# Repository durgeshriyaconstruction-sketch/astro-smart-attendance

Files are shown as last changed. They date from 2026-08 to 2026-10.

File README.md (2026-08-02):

# 🎯 Astro Smart Attendance

### AI + IoT + Cloud Smart School Attendance System

**Built by Team Sun Rises India | Class 9 | Renukoot, Uttar Pradesh, India**

---

## The Problem
Indian schools waste 10-15 minutes per class on manual attendance. 
Over 15 Lakh schools in India face this problem daily. Records, 
parent alerts and reports remain disconnected.

## Our Solution
A compact ESP32-based RFID attendance terminal with AI self-healing, 
Firebase Cloud dashboard, and automatic parent email alerts. 
Cost: Only 1,500 Rupees per unit.

## Technologies Used
- ESP32 DevKit V1
- RC522 RFID Module
- LCD1602 I2C Display
- Firebase (Auth + Realtime Database + Hosting)
- Astro AI 2.0 (Self-healing diagnostics)
- 3D Printed Enclosure (Blender)
- Arduino C++ and HTML/CSS/JavaScript

## Live Demo
Cloud Dashboard: https://astro-smart-attendence.web.app

## Validation
- 140 out of 140 Feature Tests Passing
- 10,000,000 Stress Test Cases Verified
- 0 Warnings, 0 Errors
- Working Prototype Ready

## Cost
1,500 Rupees per unit (95% cheaper than commercial systems)

## Key Features
- Works OFFLINE and syncs when internet returns
- Astro AI 2.0 with 11 self-healing diagnostic checks
- Daily and Period attendance tracking
- Admin and Student dashboards
- Automatic parent email alerts for late or absent
- Secure OTA firmware updates
- 3D printable product enclosure
- Role-based access (Admin, Student, Guardian)

## Team Sun Rises India
1. Shaurya Gupta - Team Lead, Firmware and Cloud Developer
2. Anant Tiwari - Ideation and User Research Lead
3. Tejash Upadhyaye - Hardware Integration and Circuit Testing
4. Diwakar Singh - Product Design and 3D Enclosure
5. Devansh Dakard - Testing, Documentation and Presentation

## Mentor
Dr. Jayesh Shinde - The Aditya Birla Public School, Renukoot

## Contact
Location: Renukoot, Sonbhadra, Uttar Pradesh, India

---
Made in Renukoot, India
Team Sun Rises India - STEM 2026-27

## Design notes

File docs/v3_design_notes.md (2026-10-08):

# Astro Smart Attendance - enclosure **v3**, the complete re-design

Everything in this file is a measurement of the shipped `cad/v3/*.stl` files, not an intention.
Box: **110 x 155 x 46 mm** outer, walls 2.6 mm on the sides and 3.0 mm front / rear / top,
plate 3.0 mm skin + 2 mm register frame, 22 self-tapping pilots at thread minor diameter
(M2.5 -> 2.05, M2.2 -> 1.80, M3 -> 2.50), plain side walls, and since v3.4 one hole: the d28 fan
bore is the **only air opening** on the box - the twelve grille slots v3.3 cut were filled in by
request - no supports anywhere.
All four files are **bed-aligned**: the orientation a printer must see is baked into the triangles
(`tools/orient_v3.py` is the single source of truth, and the verifier undoes that one translation
before it asserts anything in the design frame).
Four independent programs had to agree before a single line was written here:

| check | program | result |
|---|---|---|
| parametric audit A-K | `tools/build_v3.py` | `RESULT: ALL CHECKS PASS` (`docs/v3_audit.txt`) |
| STL-only verification | `tools/verify_v3.py` | `INDEPENDENT RESULT: ALL CHECKS PASS` (`docs/v3_independent_verify.txt`) |
| 10-section multi-physics audit | `tools/audit_physics_v3.py` | `PHYSICS RESULT: no failures` (`docs/v3_physics_audit.txt`) |
| groove + printed-fit walk | `tools/check_grooves_v3.py` | `EVERY GROOVE AND FIT MEASURES AS DESIGNED` - 34 values, each probed at 0.02 mm through the shipped STLs (`docs/v3_groove_check.txt`) |

That third program is the one that found the last three real defects, described in section 6.
It re-measures the shipped triangles and then argues with them: thread bite and pull-out, screw
heads and insertion kinematics, the fan's operating point against the openings it really has,
PLA's glass transition in an UP summer, 13.56 MHz and 2.4 GHz loss, the optical and viewing cones,
the ligaments between openings, and a layer-by-layer slicer model of how much plastic is extruded.

The second one never imports the generator: it re-types the reference dimensions, re-cuts the
meshes and re-measures every hole, opening and wall from triangles alone. The fourth one is the
answer to "is the size and the fitting of the groove 100 %": it does not check the *design*, it
walks a probe line through each rebate, recess, lip and hole in the file you print and prints the
number the plastic actually offers - mouth 72.00 x 23.53 for the LCD, depth 0.438, through-window
66.00 x 17.53; R307 opening 21.01 x 25.01 around a 19.3 x 21.2 lens; RC522 recess 44.73 x 62.72
x 0.798 deep leaving a 2.197 mm ledge, aperture 38.01 x 56.00; register lip 104.305 x 148.503 in
a 104.785 x 148.982 opening = 0.240 mm per side; keyhole 7.531 x 4.614 at 50.01 span; ring
opening 37.008 x 55.002 so its lip stands 0.50 mm inside the aperture; ring body 2.611 with 1.097
left under the 1.503 head recess; and the ring's four pads and its rim level to 0.001 mm. Every
one of those agrees with the intent within 0.035 mm, which is the probe's own 0.02 mm quantisation
plus rounding - i.e. the plastic is where it was told to be.

---

## 1. Why v3 exists

v2 was a repaired v1: same proportions, same walls, fixes bolted on. That is why it looked
"the same". v3 is generated from the same layout engine but with different *decisions*: the
depth came out of the RFID stack instead of being picked, the front face was re-drawn around
the modules, the RFID hold-down was replaced with a different mechanism, and the rear closure
was replaced with a different joint.

### measured shape changes (v2 -> v3)

| | v2 | v3 | why |
|---|---|---|---|
| overall size | 110 x 155 x **48** | 110 x 155 x **46** | the 48 mm was 2 mm of unused rear plug; depth is now the RFID stack + 3 mm cover |
| side wall | 2.4 mm | **2.6 mm** | v2's thinnest structural wall was 1.2 mm at the vents; 2.6 buys stiffness without new volume |
| RFID aperture | 56 x 38 with 2 x 4 mm stiffener bars (90.4 % open) | **38 x 56 portrait**, 100 % open, R5 corners | 8269 rays sampled in the aperture, 0 blocked (v2: 190 mm2 of shadow) |
| RC522 hold-down | 2 clamp bars + a 0.9 mm lip, printed **x2**, clamped over the board | **1 flat ring**, printed x1, 43.6 x 76.0 x 2.6, its inner lip 0.5 mm inside the aperture | 2.2 cm3 instead of two 1.6 cc bars, nothing in front of the antenna, one part, no flex |
| RC522 bearing | 2.0 mm ledge under the board | **2.2 mm** ledge (recess 0.8 instead of 1.0) | a 0.2 mm deeper wall in front of the coil is 8 % less plastic the 13.56 MHz has to push through |
| fan opening | d26 bore with 3 moulded grille bars (50 % free) + a d30 x 1.2 seat recess leaving a 1.4 mm lip | **d28 bore, nothing across it** (100 % free), flat wall | 616 of 616 sampled mm2 clear, and the print's most fragile sliver is gone |
| front-face openings | flush cut | **0.45 x 3.0 mm rebate ring** sunk around the LCD and the fingerprint opening | the module's own bezel sits in the rebate: a shadow line, no chipped edge, and the glass cannot be scratched by the frame |
| fingerprint mounting | 2 posts + a flat 2 mm strap over the sensor face | **dog-bone bracket** (wide over the holes, narrow across the glass) + 2 seat ribs, plus the module registers on the rebate floor | the bracket can be lifted off without prying on the glass |
| rear closure | solid 2 mm plug filling the opening (79.6 cc) | **8-sided register frame**, 2 mm proud, 0.25 mm/side, with the ESP32 zone cut clear in the **frame only** (**53.8 cm3**) | 26 cm3 (32 %) less plastic, and the board + its bosses + its locating tabs get real clearance while the 3 mm skin stays unbroken |
| ESP32 mounting | 4 square 8 x 8 posts | 4 **round d7 bosses** with **d3.6 x 0.7 spotfaces** | a round boss has no corner crack; the spotface sinks the head so the plate can still close |
| ventilation | fan wall only, everything else choked | **v3.4: one opening, the one that moves air.** The d28 fan bore in the -X wall is the only air hole on the box (615 mm2, fan blows IN) and the bottom wall keeps just the USB opening; v3.3's 8-slot bottom + 4-slot top grilles (1069 mm2, 1.74x the bore) are solid plastic. See sections 7 and 9 | air has a real path, the walls are not perforated for nothing, and nothing on the box is an opening without a duty |
| print volume | 199.6 cc (all 4 parts) | **172.2 cm3** CAD -> **159 g printed** (114 g shell + 42 g plate + 4 g small parts at 0.45 nozzle, 3 walls, 15 % infill) | the ring and the frame replace bars and a plug; 396 g all up with the modules on two wall hooks |

Nothing above is a design *claim*: `build_v3.py` section K measures the aperture and the bore by
ray-scan, the plate volume by mesh volume, the ledge flatness by probe, and `verify_v3.py`
repeats the aperture, the bore, the frame fit and the wall map from the STLs alone.

## 2. What is in the pack

| file | print | notes |
|---|---|---|
| `01_MAIN_SHELL_v3.stl` | x1 | 115.2 cm3, 11 108 triangles, watertight, 1 body, 0 open edges |
| `02_REAR_PLATE_v3.stl` | x1 | 53.8 cm3, 3 mm plate + 2 mm register frame |
| `03_R307_BRACKET_v3.stl` | x1 | 1.0 cm3, flat, 36.8 x 14.0 x 3.2 |
| `04_RC522_RING_v3.stl` | x1 | 2.2 cm3, flat, 43.6 x 76.0 x 2.6 (body 43.6 x 62.4, screw tabs to y +/-38) |

Four files, four prints, no mirrors, no "print this one twice".

## 3. Fixings - all 22 holes are circular, hollow and measured

`verify_v3.py` finds each hole in the mesh, measures its diameter with 8 rays at 3 depths, and
checks the wall around it. `build_v3.py` section I additionally asks "is this diameter and depth
actually what was designed".

| fixing | count | thread | pilot measured | driver access |
|---|---|---|---|---|
| LCD1602 + I2C backpack | 4 | M2.5 | **d2.04** x 6.3 (designed 2.05 = the thread's minor) | clear 25 mm |
| R307 bracket | 2 | M3 | d2.48 x 6.3 (designed 2.50) | clear 13 mm |
| **RC522 ring** | 4 | M2.5 | **d2.04 x 2.5 through the ring + blind d2.04 x 3.8 in the shell pad, 1.4 mm of wall left under it** | clear 23 mm |
| ESP32 DevKit V1 | 4 | M2.2 | d1.78 x 5.7 (designed 1.80) | clear 25 mm |
| 3010 fan | 4 | M3 | d2.48 x 10.3 (designed 2.50) | clear 25 mm |
| rear plate | 4 | M3 | d2.48 x 8.3 + 6.6 mm 90-deg csk | clear 25 mm |
| cable loom | 4 | - | through d4.0 tie holes | - |

The RC522 row is the one that used to be missing. It is now clamped the same way as the LCD:
four screws into four pads, and the ring's lip holds the board down. No glue, no clip, no
snap-fit, and nothing crosses the scan window.

Every pilot is at the screw's **minor** diameter, not its nominal one, because these are
thread-forming screws into printed PLA: at nominal the crest only just touches the hole wall, the
joint is friction and the screw spins. Measured radial bite/play after printing is +0.01 to +0.05
mm, and the computed pull-out is 75-362 N per screw against 0.15-0.88 N of service load (213x to
12 500x reserve). The audit's own conclusion, which is the honest one: **fastener count and
screwdriver access, not fastener strength, are what govern this box** - which is why every module
got its own 2-4 screws.

## 4. Printability, verified rather than assumed

* thinnest *sheet* anywhere in the shell: **2.2 mm** (the bearing band the RC522 board lies
  on), then 2.55 mm under the rebate rings, then 2.6 mm of side wall. The verifier's ray map
  reports a 1.40 mm minimum, and it is not a wall: it is the floor of the blind M2.5 pilot
  under an RC522 pad, which is exactly what was designed (1.4 mm of plastic under a 3.8 mm
  thread seat). v2 inherited a 1.0 x 1.4 mm lip all round the fan bore - a shallow d30 seat
  recess for a fan that is bolted to standoffs and never enters that wall - and v3 **deletes
  it**: the fan wall is a flat 3.0 mm plate with a clean d28 bore, which is both the visible
  change and the reason no fragile sliver is left in the print.
* faces steeper than 60 degrees: 244 mm2 = **0.30 %** of the shell (v3.3 measured 296 mm2 =
  0.36 % - filling the grilles in removed 52 mm2 of slot rims), and each of those bridges less
  than 3 mm -> **supports: no**.
* 214 slices at 0.2 mm: zero self-intersections, zero empty layers, first layer 11 469 mm2 (the
  footprint did not change - the shell's outline is the same 110 x 155 mm front face).
* the worst area jump in the whole print is 794 mm2 of new wall at z=0.6 and it cantilevers
  0.20 mm past the layer below (v3.3's worst was 2 415 mm2 at z=10 with a 0.00 mm cantilever);
  2 634 mm2 is added over the whole 43.0 mm of print, 0.47 % of the layer sum.
* the 10 sub-micron sliver triangles left by the boolean rim chamfers are inside the mesh, are
  under 1 um2 each, and are reported (not hidden) by the verifier.

## 5. The four numbers that used to need your calipers  *(all four closed 2026-10-08 -> section 10)*

These were the ones where a wrong number would cost a print, and the geometry is deliberately
forgiving (+/- 0.35 mm seat fit, 0.5 mm ring overlap, spotfaced bosses) so small errors are
absorbed.  Every line below is now checked against published vendor data instead of against your
drawer - what each one turned out to be:

1. ESP32 DevKit V1 - pad-hole inset from the board edge: 3.5 mm, still the modelled value, and
   corroborated by the closest published drawing in the family (wESP32 puts its 3.0 mm pad holes
   3.5 mm from the edge).  DOIT's own hole *diameter* is the one number that stays unpublished
   (2.5 mm reported by owners, 3.0 mm on that drawing): it decides M2.2 vs M2 and nothing else.
2. R307 - bracket hole pitch: there is no such pitch.  The module has no mounting holes; the stock
   kits clamp it with a bracket and two long screws, so the 28.0 mm between our posts is a choice
   we made to clear the antenna end and the corner posts, and it cannot be wrong.
3. LCD1602 + I2C backpack depth: 13.2 / 18.24 / 20.0 mm depending on whose backpack - the pocket
   reserves 24.0 behind the glass, so the deepest one on sale fits with 4 mm to spare.
4. 3010 fan - thickness and hole size: 30 x 30 x 10 with a 24 +/- 0.3 mm pattern and four 3 mm
   holes, exactly as modelled; the +/- 0.3 is taken up by the M3 shank inside the lug hole.

If any one of them is more than 0.5 mm out, change the number in `tools/build_v3.py` and re-run
`python3 tools/build_v3.py` (about 1 minute, it re-exports the STLs and re-runs every check, and
prints `RESULT: ALL CHECKS PASS` or refuses to). Then re-run `tools/verify_v3.py` (STL only)
and `tools/audit_physics_v3.py` (physics, and it re-measures the numbers in this file and in the
print order, so a doc cannot survive a stale claim).

---

## 6. v3.1 -> v3.2: what the physics audit found, and what changed

Both checkers passed v3.0, and the audit still found three real defects. All three are fixed in the
files you are printing; all three are now guarded by a permanent check, so they cannot come back.

**F11 - a rear-plate screw countersink opening onto a corner round (medium).** The 6.6 mm 90-degree
cone at each of the 4 plate screws was 0.08 mm from the R3 corner round of the plate outline, i.e.
the cone broke through the side of the part and the screw head would have had a hole to fall into.
The four screws moved from (+/-46.5, +/-71.0) to **(+/-46.5, +/-67.5)**, 3.5 mm inboard of the
rounds. The verifier now measures, for each corner, the plastic left between the cone axis and the
plate outline at the outer face: **2.25, 2.25, 2.25 and 3.80 mm** (it must be >= 1.2 mm; v3.0
measured 0.08 mm).

**F12 - the rear plate had a 15.6 x 63 mm hole through it (high).** The cut that keeps the ESP32's
locating bosses clear of the plate ran from the register frame to `z = D + 2`, i.e. **through the
whole 3 mm skin** instead of only the 2 mm frame that stands into the cavity. The shipped v3.0 plate
was open to dust and weather over that corner, and the "plate closes the box" claim was false. The
cut's top is now `z0 + 0.16` (the frame's own top surface), the plate went from 51.4 to 53.8 cm3,
and the verifier gained a check that slices the plate at mid-thickness and demands *exactly* 6 voids
- the 4 screw holes and the 2 keyhole slots - and >= 15 600 mm2 of skin (v3.0 measured 14 897 mm2
with a hole; v3.2 measures 15 983 mm2 with none).

**F13 - the RFID reader could not be installed at all (high).** Its PCB is 60 x 40 mm and v3 laid
the 60 mm dimension across the box, against the -X wall. But that wall carries the ESP32 on four
10 mm stand-off posts and the 3010 fan on four more, and the front wall's bay between the ESP32's
posts (ending at x = -42.4) and the R307's own -X post (starting at x = +15.95) is 58.35 mm:
**1.25 mm narrower than the board, 4.05 mm narrower than its hold-down ring.** Lowering the part
onto its seat is impossible in any orientation, tilted or not, and it is not fixed by a build order
because the blocking plastic is printed into the wall. Fixed by mounting the reader **portrait** -
its 60 mm dimension along the 155 mm height instead - which was always the better layout for a card
anyway: the whole stack is then 43.6 mm wide, drops straight down with 6.4 mm to the ESP32 posts,
10.2 mm to the R307 post and 3.25 mm to the fan bosses, and the reader centre moved from x = -20.05
to x = -16.05, which also widened the ligament between the RFID aperture and the fingerprint window
from 17.5 to 22.5 mm. Aperture 38 x 56 (2106 mm2, still 8269/8269 rays clear), ring 43.6 x 62.4
body with screw tabs at (+/-17, +/-34), and the audit section 3 now proves a straight-Z path for
**every** module plus the plate.

Two things that were not defects but are now corrected in the docs: the air path, and the print's
mass.  The air path went through two changes: v3.1/v3.2 opened 8 x 30 x 5 mm stadium slots in the
+X wall (1157 mm2) because the 6 x d5.0 / 118 mm2 of v3.0 choked the fan; then **v3.3 deleted those
side slots** and moved the inlet into the fan's own bore (see the v3.3 section below). The 15 % infill figure of ~102 g was a blanket 50 % factor and is
**too low**: a 2.6 mm wall printed on a 0.45 nozzle with 3 perimeter lines is 2.7 mm of perimeter,
so it prints solid. Layer-by-layer over the shipped meshes the parts extrude 79 % (shell), 62 %
(plate), 100 % (bracket) and 100 % (ring) of their CAD volume = **159 g of PLA**, 396 g with the
modules on the wall, and a 1 kg spool prints the set 6.3 times (53.0 m of 1.75 mm filament).
(`verify_v3`'s typed per-part fractions put the same print at 158 g - 0.6 % apart, both quoted
rather than smoothed, because the two are different samplings of one model.)  Those
those are the v3.4 figures; the grilles v3.3 left in the bottom and top walls were worth 3.2 cc of
plastic and 3 g of it.

Assembly note that came out of section 3: the reader's 8-pin header may not be taller than about
6 mm over the pads, because the channel under the ESP32 posts is 9.8 mm and the board plus a 9 mm
male header is 10.6 mm. Solder the leads, or use short / right-angle female headers, or fit the
reader before the ESP32. Everything else - ring, R307, LCD, fan, ESP32 - drops straight in with the
plate off, and the plate is the last thing closed.

Print order (unchanged by all of the above): all four parts flat on the bed, `01` front face down,
`02` frame down, `03` back face down, `04` pad face down; 0.2 mm layers, 2.6 mm walls, 15 % infill,
3 top/bottom skins, no supports, no brim needed unless your bed is unlevel (the shell's rim is
436 mm long).

---

## 7. v3.2 -> v3.3: the fan does the work, so the side grooves went away  *(v3.3, superseded below)*

Asked for directly: *"remove the right side many grooves - for that I have fan"*.  The eight stadium
slots in the +X wall went, and that wall is solid 2.6 mm plastic - the independent checker
slices it at mid-thickness and finds **0 voids**, still true in v3.4.  A fan still has to move air
through *something*, so the duty moved instead of disappearing, and the numbers below are what the
v3.3 STLs measured - the history of where the openings were, with v3.4's change in section 9:

| | v3.2 | v3.3 (then v3.4, section 9) |
|---|---|---|
| inlet | 8 x 30 x 5 mm slots in the +X wall, 1157 mm2 | the **d28 fan bore itself** in the -X wall: 615 mm2, measured 615 of 616 clear |
| fan direction | blowing OUT (exhaust) | **blowing IN** - the arrows moulded on the fan's frame point at the box |
| outlet | 4 x (20 x 4) bottom + 3 x (16 x 3) top, 452 mm2 | **8 x (21 x 4.5) bottom + 4 x (21 x 4) top = 1069 mm2**, 1.74x the bore - all twelve of those slots are filled in now |
| right (+X) wall | perforated over 4 of its 6 rows of features | plain; nothing to sand, nothing to crack, and the ESP32 bosses keep their full wall behind them |

The rule as it stood then was from the master prompt - the passive set must stay **>= 1.5x the fan
bore** - and it is that rule, not the geometry, that v3.4 replaces with a different one (section 9).
Everything else about the path was deliberate, and stays true of the walls as they now stand:

* bottom grille (v3.3, now solid): 21.00 x 4.50 mm slots in 4 columns (+/-12.5, +/-37.5) at 2 heights (z 7.0 and 15.0),
  every corner rounded r1.6 (r1.2 in the top wall) so there is no corner to start a crack - which
  also means each one measures 92.3 mm2 of free area, not the 94.5 mm2 of a sharp rectangle;
* top grille: 21.00 x 4.00 mm, 4 slots at z 26, i.e. the warmest air above the board level;
* 3.50 mm of plastic between the two rows, 4.00 mm between the columns - never thinner than the
  3.0 mm wall they are cut in;
* the lowest slot edge sat 1.75 mm clear of the front wall's inner face, and 4.6 mm clear of the
  20.4 x 12.4 mm USB opening in the same wall - that opening is the one thing left in it;
* pressurising the box rather than evacuating it is the better direction for this unit: it pushes air
  out through the RFID aperture and the LCD rebate, which is what keeps dust from being sucked in
  around the R307 prism.

Two options were rejected with numbers, not taste.  Sealing the +X wall and leaving v3.2's grilles
would have dropped the passive set to 452 mm2 = 0.73x the bore: the fan would have run close to its
own choke point and the box would have been a negative-pressure dust collector.  The first v3.3 cut
- rows of 5 mm slots at z 7 and 14.5 - failed the audit outright:
`web between neighbouring bottom grille openings  2.50 mm minimum  FAIL`, a ligament thinner than
the wall around it.  Dropping the slot height to 4.5 and opening the rows to 7 / 15 gave 3.50 mm of
web, and widening the slots 18 -> 21 mm at a 25 mm pitch (still 4.00 mm between neighbours) paid the
area back with interest: 985 mm2 -> 1069 mm2 of outlet.

Duty point against the fan's straight line, as section 4 of the physics audit measured it **on the
v3.3 mesh**: A_eff 533 mm2 -> 0.84 L/s at 1.9 Pa, 84 % of the fan's free air, the whole 784 cm3 box
changed every 0.9 s, dT 1.6 K at 1.6 W.  That was the same duty point v3.2 measured (0.86 L/s) with
a wall full of holes in it, reached with the passive openings alone and no perforation in the side
wall; the bottom grille was 8 x 21 x 4.5 mm and the top 4 x 21 x 4 mm, which is where the
1069 mm2 came from.  With the grilles filled in the flow is smaller and the box is no cooler - that
is section 9's measurement, not this one.
Nothing in this section is load-bearing on the geometry switch alone: setting `P["side_intake"] = True`
in `tools/build_v3.py` puts v3.2's perforated wall back in one rebuild, `P["grilles"] = True` puts
v3.3's twelve slots back, and the build's self-test changes its checks to match either way.  Those
flags exist so these decisions can be reversed without archaeology; they are not hidden second
designs - the shipped model is the one with `side_intake=False, grilles=False`.

## 8. The fifth print: `05_FIT_GAUGE_v3.stl`, a card that answers the five open questions  *(kept in the repo, out of the pack from v3.5)*

Section 5 left five numbers owned by your hardware rather than by any datasheet I could read from
here - which pilot your boss actually bites, what size the hole in your PCB really is, whether the
1602 window and its 75.1 x 31.0 pitch are your module, whether the R307's bezel clears a 21 x 25
relief, and whether the RC522 board and its pads sit where the ledge is.  Those are all *size*
questions, so they do not need a box to answer them: they need a printed thing of known size.  The
card is that thing - 150 x 112 x 2.60 mm, print-flat, 40 minutes, and every number on it read out
of `tools/build_v3.py` at build time rather than typed a second time.

Two conventions, and only two, because a gauge that mixes them is unreadable:

* **a cut is a GO gauge.**  The card is 2.60 thick and the hole in it is the hole in the wall, to
  the micron, so anything that drops through the cut fits the box.  A pass here is a pass there;
  that is the whole promise, and `tools/check_gauge_v3.py` measures it rather than asserting it.
* **an engraved line is a reference outline** - the board, the pitch, the prism window, the ledge -
  0.50 mm deep, to be read with calipers or felt with a fingernail.

Seven stations: six blind pilots (d1.80 / 2.00 / 2.05 / 2.20 / 2.35 / 2.50 at 8.00 deep, each
leaving 4.60 mm of solid boss under it), four through-board-holes (d2.00 to d2.70), the 1602 window
and its pitch crosses, the R307 relief plus the prism window and body outline, the RC522 board at
+0.40 a side with its ledge and four pads, the USB opening as the wall has it, and a 100 mm rule
ticked every 10 mm so a printer that shrinks the whole set is found out first.  The card's own
thickness is also the shim unit: 2.60 mm, the height of one wall, so stacking two says 5.20.

What it cannot do, said plainly: it cannot tell you how *tall* a module is, or whether an LCD's
contrast survives a 1.6 mm shelf.  Those are the box's own geometry and they are measured in
`docs/v3_groove_check.txt`.  The card settles the sizes; the box still has to be test-fitted.

Three real defects were caught building it, which is what a self-check is for:

* the first boolean produced 12 open edges.  Cause: thirty engraved pockets extruded as separate
  prisms with coplanar walls touching each other.  Fixed by unioning every pocket that shares a
  plane in 2-D and extruding once - which also dropped the file from 32 958 to 16 208 triangles.
* `is_watertight` said True while the normals pointed *inward*.  A slicer handed that STL may print
  the card hollow.  Fixed with `fix_normals()` in the builder, and the build now refuses to write a
  file unless `is_watertight and is_volume and volume > 0` (`GAUGE BUILD: ALL CHECKS PASS`).
* the first checker reported `watertight=False` for a part that was fine, because its probe asked
  "how many void stretches are in this window" instead of "which stretch contains the centre".  A
  probe line that crosses the far side of the part on its way to the window edge is not a second
  void.  The rule now used everywhere: the interval that contains the probe centre, refined by
  bisection - and it must back off *two* samples, not one, because a sample can land exactly on a
  surface (that is where a d1.80 pilot read 1.750 for one run: half a step on each side).

The wall comparison is deliberately not a min-of-three-planes statistic any more.  Profiling the
front wall at five planes showed a 0.05 mm disagreement on one plane - a grazing ray on a vertex,
not a taper - so the checker now reports the spread as its own row (`LCD width is a clean prism`,
0.000 to 0.050 mm) and compares the *median* against the card, requiring the card never to be the
bigger of the two.  That row can still fail, and fails if a wall ever does taper.

The card is registered everywhere a part has to be: `tools/orient_v3.py` (`0.0`, printed flat,
engraved face up), the pack's STL list, its figure list, the offline viewer, and the print order -
where it is step 0, before the shell, which is the entire point of it.

## 9. v3.3 -> v3.4: one hole, not twelve - the grilles are gone

Asked for directly, pointing at the hollows in the side of the box: *"remove all unnecessary ... no
need for those hollows, only let that DC fan one - not more, and last check"*.  So every grille slot
was filled in.  The bottom wall loses its 8 x (21 x 4.5) grille and keeps **only the USB opening**
(20.4 x 12.4 mm, a cable hole, never an air one); the top wall loses its 4 x (21 x 4) grille and has
no opening left at all; the +X wall was already plain in v3.3 and still is.  What is on the box now:

| wall (measured at mid-thickness off the shipped STL) | v3.3 | v3.4 |
|---|---|---|
| bottom (-Y) | 8 slots + USB, 9 voids | **1 void**: the 20.40 x 12.40 mm USB opening |
| top (+Y) | 4 slots, 4 voids | **0 voids** |
| right (+X) | 0 voids | 0 voids |
| left (-X) | d28 bore, 615 mm2 | **d28 bore, 615 mm2 - the only air opening** |

That inventory is not a claim in a document, it is `tools/verify_v3.py` section 6b, run on the STL
and nothing else, and it also fires 9 sample rays at each of the twelve old slot centres and both
ends of every slot (36 probes, 324 rays) which all have to be *blocked*: a slot that came back would
let them through.  `tools/make_grille_map_v3.py` draws the same four sections and exits non-zero
unless the counts are 1 / 0 / 0 / 1.

**What the change costs, measured rather than argued.**  The openings were the *flow* path; the heat
mostly leaves through the *skin*, and the skin did not change.  Section 4 of the physics audit now
computes both:

* passive: 1.6 W (ESP32 in TX bursts + RC522 + the fan's own draw) over 0.0585 m2 of PLA at
  h = 10 W/m2.K -> **dT = 2.7 K** above ambient; at h = 5 (a closed cabinet, no air movement) 5.5 K;
* through-flow: the fan has only the bore in front of it and the plate's register seam to get out
    of, 509 mm of frame x 0.25 mm of clearance = 127 mm2 *[this one row is an ASSUMPTION about your
  print, and the audit records it as a note, never as a gate]* -> A_eff 125 mm2 -> **0.25 L/s at
  12.2 Pa**, 25 % of the fan's free air, the 784 cm3 box changed every 3.2 s, dT 5.4 K;
* the two paths are in parallel, so the box settles at **dT = 1.8 K**.  v3.3 measured 1.6 K with
  1069 mm2 of grille open, so closing all twelve slots is worth **0.2 K**: the through-flow fell
  from 0.84 L/s to 0.25 L/s, 30 % of what it was, because a d28 bore was always what limited a
  3.6 m3/h blower - but the skin never noticed, and that is the whole reason the trade was open
  to make.  12.2 Pa is high up a small blower's pressure curve, which is what a fan facing a
  narrow gap does; it costs a little noise, not cooling.

The trade is therefore real but small, and two things about it are worth knowing before the print is
sanded off the bed:

* the fan is now part of the enclosure, not an accessory.  The d28 bore is the biggest hole on the
  box; a 30 x 30 frame spans it with 1 mm of plastic all round, so with the fan screwed in there is
  no opening a finger can follow, but a shell used *without* the fan has a 28 mm hole in its side.
* what the fan still does inside a sealed box is stir: it breaks the boundary layer off the LCD and
  the R307 prism and holds the enclosure slightly above room pressure, which is what keeps dust from
  being pulled in around the scanner.  It is a demister that also cools, and it should keep running
  from the ESP32's own supply.

Nothing else moved.  Filling twelve slots in added 3.2 cc of plastic to the shell (112.0 cc -> **115.2 cm3**),
11 108 triangles where v3.3 had 14 426 (3 318 fewer, because the slot outlines and their corner arcs
are gone), and it *reduced* the fragile geometry: overhang area 296 mm2 -> **244 mm2** (0.30 % of the
shell), still no supports, first layer 11 469 mm2.  The four box parts are now **172.2 cm3 CAD ->
159 g of PLA**, 396 g with the modules on two wall hooks, 53.0 m of filament, 6.3 sets on a 1 kg
spool.  `02_REAR_PLATE_v3.stl`, `03_R307_BRACKET_v3.stl` and `04_RC522_RING_v3.stl` are byte-identical
to v3.3 - only the shell was rebuilt - and so is `05_FIT_GAUGE_v3.stl`, which the user still prints
first because none of this changes a pilot diameter.

Reversible in one line, like every other aesthetic decision on this model: `P["grilles"] = True` in
`tools/build_v3.py` brings all twelve slots back, and the builder's self-checks, section 6b of the
verifier and the opening map all switch their expectations with the flag rather than being edited to
match.

---

## 10. v3.4 → v3.5: the pack is four files, and the open sizes were closed from vendor data

Asked for the exact sizes and a final screw list — and not willing to print a gauge or measure
anything — the only honest way to answer was to go and look.  Every module in this box was checked
against published outlines on 2026-10-08.  **Nothing in the geometry moved**, and that is the result
rather than a shrug: the model was built from the same numbers the vendors publish, so the audit, the
verifier and the four STLs you already have still refer to these exact bytes.

| part | what the vendor data says | what the box has | verdict |
|---|---|---|---|
| R307 | 44.1 × 20 × 23.5 body, 19 × 21 window — makerselectronics, robokits and the Grow/NEWTECH manual all publish the same numbers | `r307_body=(20.0, 44.1, 23.5)`, window 19.3 × 21.2, relief 21.0 × 25.0 in a 25.3 × 27.2 rebate | **exact**, 0.3–0.6 mm clear around the glass, 0.35 seat fit |
| R307 mounting | the module has no mounting holes at all: the four Phillips screws on its back close the housing, and the stock kits (ArduGeek, sensorembedded, Grow) clamp it with a bracket plus two long M3 | a printed dog-bone bracket over the housing, 2 × M3 × 10 into ⌀2.5 × 8.0 posts | **the same method as the kit**, so the 28.0 mm pitch is our bracket's and not a tolerance to match |
| 1602 + I2C | 80 × 36 outline; depth 13.2 (displaymodule.com, slim), 18.24 (addicore), 20.0 (einstronic); 72 × 25 of bezel, 64.5 × 16.2 of visible text | window 66.0 × 17.5, rebate 72.0 × 23.5 × 0.45, cavity reserved to `zi+24.0` | **every depth sold fits with ≥4 mm to spare**, and the audit's envelope check proved the pocket collides with nothing |
| RC522 | 60 × 40, 1.6 PCB, header ≤ 6 mm | 62.7 × 44.7 × 2.9 recess, 1.0 shelf, 4 ribs, the ring clamps the edges | **fits any brand of that size**; the board's own hole pitch is deliberately unused |
| 3010 fan | 30 × 30 × 10, "mounting dimensions 24 ± 0.3 mm", "4 holes 3 mm"; 5 V parts flow 1.9–2.5 CFM | `fan=(30,30,10)`, `fan_pitch=24.0`, ⌀3.2 lugs, ⌀28 bore, flow modelled 3.6 m³/h | **exact**; the modelled flow is inside the published 3.2–4.2 m³/h band and the audit runs the low end |
| ESP32 DevKit V1 | 51.45 × 28.33 (espboards.dev draws it to that outline), 52 × 28 × **14** with headers (einstronic); pad holes ⌀2.5 reported by owners, ⌀3.0 on the wESP32 drawing with 3.5 inset | `esp32_board=(28.33, 51.45, 1.6)`, `esp32_comp_h=16.0`, inset 3.5, M2.2 into ⌀1.8 | outline **exact**, height **2 mm over the real stack**, pad-hole diameter still unpublished — it decides M2.2 vs M2 and nothing else |

Two near-misses that turned out to be fine.  The ESP32's real 14 mm stack looked like it needed
`esp32_comp_h` raised from 12: it was already 16.0, and the audit proves the plate still closes over it.
And the fan's ±0.3 mm pattern tolerance is absorbed by the M3 shank having 0.1 mm per side inside the
lug hole — which is precisely why the wall holes are ⌀2.5 pilots rather than threads cut to 24.0.

**Screws, final.**  Same table as the print order's SCREWS section, which the audit measured hole by
hole (22 of them):

| where | screw | into | evidence |
|---|---|---|---|
| rear plate | 4 × M3 × 10 | ⌀2.48 × 9.0 blind pilots; plate holes ⌀3.4 clearance; 90° countersink ⌀6.40 | pull-out 291 N each vs 0.59 N of load |
| LCD1602 | 4 × M2.5 × **8** (was × 12, over-length) | ⌀2.05, 7.00 mm of void | the pilot is the thread's minor ⌀2.06, so it bites |
| RC522 ring | 4 × M2.5 × **4** (was × 8, over-length) | ⌀2.05, 4.30 mm of void through ring and pad | ⌀5.6 × 1.5 recesses in the ring take the pan heads; × 5 is the longest this hole can be told |
| R307 bracket | 2 × M3 × **8** (was × 10, over-length) | ⌀2.50, 8.20 mm of void | the bracket is 3.2 mm thick and printed, so its own thickness is already inside that void |
| fan | 4 × M3 × **12** into the printed tabs; **× 20** only if you drill through the whole 10 mm frame | ⌀2.50, 11.00 mm of void from inside | a 3010 usually ships **two** screws — you need four, pan head, not countersunk; nothing longer than 20 goes in, it pushes the wall out |
| ESP32 | 4 × M2.2 × 8 | ⌀1.80 × 5.7 | **M2.2 only** at the antenna end; M2 × 8 self-tapping is the fallback (it clears a 2.5 mm board hole and bites the same pilot); **not M2.5**, which may not pass that hole; never M3 |

M2.2 × 8 is the only line a Mirzapur hardware shop might not stock — it is a precision size, sold
online in packs.  M2 × 8 from any M2 kit is the substitute.  Everything else here is loose-change
stock.

## 11. v3.5 → v3.6: the `.blend`, and the holes measured to the depth

The ask was the full 3D model as a real `.blend`.  It is there — `exports/ASTRO_SMART_ATTENDANCE_v3.blend`,
written by Blender 4.5 LTS from the four shipped STLs, with the modules, the real 3010 and the 22 fasteners —
and §11.1 at the end of this file is the model's own account.  What changed *documents* is smaller and worse:
measuring the holes in the third dimension, which no checker had ever done.

**Why three of those five lengths changed, and why the table now quotes a void instead of a depth.**
Building the `.blend` for v3.6 forced one measurement that had never been made: not how wide each
pilot is, but how deep it is.  `tools/hole_probe_v3.py` casts a ray down the axis of all 22 holes in
the shipped meshes and records, for each, the face the head actually bears on, where the plastic
starts, and how much material is left behind the bottom; the void plus the unprinted stack plus the
0.4 mm every thread needs at its tip is the room a screw has.  Against that, `M2.5 × 12` for the LCD
had 9.00 mm of room and would have floated the display 3.0 mm off its bosses, `M2.5 × 8` for the
reader ring had 4.70 mm and would have stood 3.3 mm proud — which is more than the 0.5 mm the ring
overlaps its pocket lip, so it would have cost the register as well as the seat — and `M3 × 10` for
the R307 bracket had 8.60 mm.  All three are corrected above and in the print order, and the
recommendations that survived are `M3 × 10` plate, `M3 × 12` fan tabs and `M2.2 × 8` ESP32.  Two
things the same pass proved and that are worth saying out loud: no pilot in this enclosure is a
through-hole — the thinnest skin under any of them is 1.40 mm, under the RC522 pads — and the
`stack` term has to be the *unprinted* material only, because the bracket and the ring are printed,
so counting their 3.2 mm and 2.6 mm as clearance manufactures room that is not there.  The tool is a
gate rather than a note: it exits non-zero when a documented length does not seat, so a hole can be
widened in `tools/build_v3.py` and the schedule will refuse to stay silent.

And the fifth file is gone from the pack: `tools/build_gauge_v3.py`, `tools/check_gauge_v3.py`,
`tools/make_gauge_figure_v3.py`, `cad/v3/05_FIT_GAUGE_v3.stl`, `docs/v3_gauge_build.txt`,
`docs/v3_gauge_check.txt` and `renders/v3_fit_gauge.png` all stay in the repo and still run, and none
of them ships any more — `tools/make_pack_v3.py` lists four STLs.  If a vendor number ever turns out to
be a lie about *your* module, `python3 tools/build_gauge_v3.py` prints the card again in 20 seconds of
slicing time and the pack takes the line back.

### 11.1 The `.blend` file itself

`tools/make_blend_v3.py` imports the four bed-aligned STLs from `cad/v3/`, lifts each by the `dz` in
`tools/orient_v3.py` (and asserts the part's lowest point *is* that lift, which is what proves the scene shows
the part that prints), then builds the five module envelopes, a real 3010 — 30 × 30 × 10 minus a ⌀28 bore and
4 × ⌀3.2 on 24 mm, 2 529 mm3 of plastic — and one screw per hole **measured** by
`tools/hole_probe_v3.py`: shank at the thread's nominal, a pan head where the mesh has a ⌀5.6 × 1.5 recess, a
countersunk cone where the rear plate has a 90° countersink.  Collections: `01 PRINTED`, `02 MODULES`,
`03 FASTENERS`, `04 BED ALIGNED` (hidden, so a slicer view is one click away) and `00 RIG` — seven empties keyed
apart over 24 frames and back over the next 24, three cameras, a sun.  Scene units are mm at
`scale_length = 0.001`, so the numbers in the Outliner are the numbers on the print order.

Nothing about it is taken on the builder's word.  `tools/check_blend_v3.py` opens the *saved* file, shares no
code with the builder, and re-derives each solid's volume from its own polygons in world space: 115.22 / 53.80 /
1.01 / 2.19 cm3, 172.22 total, assembly box 110.00 × 155.00 × 46.00 mm.  Then it checks that each of the 22
screw axes lands on a hole centre the mesh itself reports (worst error 0.000 mm) and stops above the bottom of
its pilot (+0.20 to +1.50 mm), that the modelled lengths equal the published schedule, that all seven groups
really move more than 20 mm and in the order the print guide assembles them, that the `.glb` re-imports to the
`.blend`'s own box to 0.05 mm, and that the three Cycles frames hold a shaded picture rather than a blank —
pixel spread and variance, not file size.  It also gained the rule the first pass needed: nothing in the file
may poke outside the case box + 2.5 mm, which is how a USB plug drawn from the envelope generator as a
22.5 mm slab and hanging 14 mm in the air behind the wall got caught, and redrawn 2 mm proud of it.  Display
only: the clearance envelope the audit measures is untouched, and no STL byte moved.

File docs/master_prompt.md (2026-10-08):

# ASTRO SMART ATTENDANCE — ENCLOSURE MASTER PROMPT (single consolidated prompt)

> **What this file is.** The two prompt blocks that were sent separately —
> *(A)* the base “model the enclosure in Blender” prompt and *(B)* “FINAL MISSING ENGINEERING
> REQUIREMENTS §1–26” — merged into **one** self-contained prompt, with every component dimension
> cross-checked against the real hardware, the corrected final layout, and the acceptance rules.
> Paste this whole file as the prompt. Nothing else is required.
>
> **Status of the model it describes:** implemented and audited. `tools/build_v2.py` regenerates
> `cad/v2/01_MAIN_SHELL_v2.stl` (single watertight body, 9892 tris, 115.1 cm³),
> `cad/v2/02_REAR_PLATE_v2.stl`, `cad/v2/03_R307_BRACKET_v2.stl` and `docs/v2_audit.txt`
> (**RESULT: ALL CHECKS PASS**). See §21 for the scorecard and §23 for the remaining
> `VERIFY_ACTUAL_HARDWARE` items.

---

## §1 Mission

Model a wall-mountable, 3D-printable enclosure for the **Astro Smart Attendance** ESP32 RFID
attendance terminal. It holds an ESP32 DevKit V1, an RC522 13.56 MHz RFID reader, an R307 optical
fingerprint sensor and a 1602 LCD with I²C backpack, plus a 3010 fan. The enclosure is a
**housing, not a gadget**: no electronics are invented, nothing is decorative, every feature exists
because a real part needs it.

Deliver millimetre-accurate geometry that can be sliced and printed **without support material**,
**without a single clearance failure**, and with every claim backed by a measurement.

## §2 Units, scale and axis frame

* Metric, **millimetres**, **1:1 scale** (Blender: `scene.unit_settings.system='METRIC'`,
  `scale_length=0.001`, `length_unit='MILLIMETERS'`).
* Axis frame used everywhere (STL frame too):
  * **X = width** (110 mm, device left/right)
  * **Y = height** (155 mm, top/bottom)
  * **Z = depth** (48 mm); **z = 0 is the FRONT face the user touches**, z = 45 is the shell’s rear
    edge, z = 45…48 is the rear service plate.
* Print orientation = this frame: **front face down on the bed, rear opening up** (`+Z` up).

## §3 Honesty rules (non-negotiable)

1. **Never model:** an RFID card, a card holder/cradle, any price (₹912 / ₹442 / ₹67 / ₹15 / ₹87 /
   ₹108 / ₹43), fictional components, decorative electronics, dummy LEDs, logos that are not the
   product name, or any geometry that is not needed to hold a real part.
2. **No placeholder geometry, ever.** Every boss, rib, pilot, slot and opening is dimensioned from a
   real part or from a stated engineering estimate.
3. **No fake openings** (an opening that does not open into the cavity) and **no fake mounting
   holes** (a hole with no matching hole in a real part).
4. **Never write PASS unless a check produced that PASS.** If a value is unknown, write
   `VERIFY_ACTUAL_HARDWARE` and say so in the report.
5. **Never merge components into one mesh.** Every real part is a separately named, separately
   editable object (§20).

## §4 Dimension priority

`actual measurement of the delivered hardware` **>** `dimension supplied by the team` **>**
`generic internet dimension`. Anything from the third tier or unverifiable is tagged
`VERIFY_ACTUAL_HARDWARE` in the audit and in the object name if it affects a fit.

## §5 Component register (the only parts that exist)

| Part | Model dims used (mm) | Source | Notes |
|---|---|---|---|
| ESP32 DevKit V1 (DOIT) | PCB **51.45 × 28.33 × 1.6**, components ≤ 12, +USB | [REF] team | 4 corner pads, hole inset 3.5 → `VERIFY_ACTUAL_HARDWARE` |
| RC522 reader | PCB **60 × 40 × 1.6**, components 6 (spec 3–8) | [REF] + web | 40 × 60 confirmed (espboards.dev, ifuturetech, sunrom, robotshop); corner holes ≈⌀3, pitch unverified → `VERIFY_ACTUAL_HARDWARE` |
| R307 fingerprint | body **44.1 × 20 × 23.5**, optical window 19 × 21 | [REF] manual | the single highest-risk part; mounts on a 2 mm steel bracket |
| LCD1602 + I²C backpack | PCB **80 × 36**, glass 71.2 × 24.2, **one combined assembly ≈ 18.24 deep** | [REF] | **do not** model the backpack as a separate 42 × 19 board |
| Fan | **30 × 30 × 10**, holes ⌀3.2/M3 on **24 mm** pitch | [REF] | grille ⌀26, 3 bars |
| Fasteners | 4 × M3 (plate), 4 × M2.5 (fan), 4 × M2.2 self-tap (ESP32 pads), 4 × M2.5 (LCD), 2 × M3 bracket | `FASTENER_SCHEDULE` | pilots: M3 → ⌀2.5, M2.5 → ⌀2.2, M2.2 → ⌀1.8 |

## §6 The enclosure is *derived from* the layout — never the other way round

The outer size is an **output**, not an input: place the parts first with their real clearances,
then wrap walls around them. The result here is **110 × 155 × 48 mm** (110 × 155 × 45 shell +
3 mm plate) with walls **front 3.0 / sides 2.4 / top & bottom 3.0 / plate 3.0 mm**.
Walls must stay inside 2.4–3.0 mm everywhere; the only permitted thin feature is the deliberate
1.45 mm web across the RFID recess (§8).

## §7 Tolerances

* Printed mating fit (lip, snap tabs, plate register): **0.35 mm** total clearance per side.
* Component clearance to enclosure walls: **1.0–2.0 mm**; pocket clearance 2.0 mm.
* Pilot holes = nominal ⌀ − 0.5 for self-tapping into PLA.
* Every mating pair is stated in the audit; nothing is allowed to interfere.

## §8 RFID reader — the reason this revision exists

The v1 shell had a **closed pocket floor at z ≈ 3 mm over the RC522 antenna**, which blocks
13.56 MHz scanning. That is fixed and must stay fixed:

1. **Open scan window `RC522_SCAN_ZONE` = 56 × 38 mm, completely open through the 3 mm front wall**
   (no floor, no membrane, no printed skin — an RFID field will not pass a printed wall reliably).
2. The window sits inside the existing **62.7 × 44.7 mm recess, 1.0 mm deep**, whose floor carries
   **1.0 mm locating ribs** (1.2 mm wide, 0.35 mm fit): the 60 × 40 board lies at **z = 3.0 … 4.6**,
   component side up into the cavity, so only **2.0 mm** of printed wall stands in front of the PCB —
   the thinnest the wall can be while still giving the board something to rest on.
3. **Stiffness:** the front wall is locally reduced to a **1.95 mm** web; **two** stiffener bars
   **2.5 mm wide × 1.95 mm thick**, spanning the 38 mm window, keep the front face rigid (measured in
   §21-E: bar 1.90 vs 1.95 design). They are the *only* material inside the window and they are
   **9 %** of its area — ray-proved in the audit, not assumed.
4. **`RC522_RF_KEEP_OUT`:** a 62.7 × 44.7 × 12 mm volume in front of the antenna is declared
   metal-free and plastic-free; the audit proves enclosure material volume inside it = **0.00 mm³**.
5. **`RC522_SCAN_ZONE`** additionally proves that the window is genuinely through-cut: a ray cast
   from outside the front face passes through the wall into the cavity.
6. The RC522 is **screwed down**, not clipped: **4 × 8 × 8 mm screw pads (2.5 mm tall, ⌀2.2 pilot,
   4.1 mm deep)** sit at ±22.0 / ±27.0 mm from the recess centre (outside the board edge and clear of
   the 56 × 38 window), and **two printed clamp bars** (part 04) hold the board's two short edges —
   a 62 × 15 mm platform with a **0.9 mm lip step** that presses the PCB onto the front wall, plus a
   **2 × ⌀3.0 through-hole + ⌀5.6 × 1.4 head recess** at each screw, 44 mm hole centres. The stack is
   closed by arithmetic: platform underside 5.50 = pad top 5.50 (0.00 interference), lip bottom
   4.60 = board top 4.60. The whole antenna face stays open and every screwdriver approach is
   straight down the Z axis from the rear opening (§21-I, §21-J).

## §9 Pin-out, header and connector space (the “leave room for the header” rule)

Nothing in this enclosure may be dimensioned as if the boards were bare PCBs. Real assemblies carry
**2.54 mm headers and Dupont housings**, so:

* **RC522:** its 8-pin header (plus the optional 2 extra I/O pins) is on the board’s long edge and
  adds **11.5 mm** normal to the PCB. The pocket rim is 2.4 mm tall and the tabs grip only the board
  edge, so the header side faces the cavity with **≥ 12 mm** of free space; the SPI jumper wires leave
  through the ≈ 9 mm gap between the R307 bezel relief (up to X 48.45) and the pocket rim (to X 14.35).
* **ESP32 DevKit V1:** two 19-pin headers at 2.54 mm pitch add **11 mm** to the 1.6 mm board. The bay
  holds the board on **10 mm standoff pads** and the board’s plane sits at X = −42.6, leaving
  **25 mm** of depth behind it in the cavity — header pins plus Dupont housings (≈ 15 mm) fit with
  room to spare, and the pins never touch the rear plate ribs at Z 41.
* **USB / power:** the micro-USB plug body is 15.6 × 8 mm and passes the 18 × 10 mm slot with 1.2 mm
  of clearance all round; the DC feed shares the same bottom-left corridor, which is why the rear
  boss in that corner starts at Z 33 instead of running to the wall.
* **Access for the pin headers:** the rear opening is 105.2 × 148.3 mm; the ESP32’s header rows and
  the RC522’s pins are both within 90 mm of it, so a Dupont housing can be plugged and unplugged
  without removing any printed part except the plate. The RC522 clamp bars sit only over the two
  short board edges (y = −51.1 and +2.9), i.e. 13 mm each, leaving the header edge free.
* **Every header clearance is measured** in the audit (envelope overlap = 0.00 mm³) — a header that
  touches a boss is a FAIL, not a note.

## §10 Final layout (the delivered model)

| Feature | Position / size (mm) | Provenance |
|---|---|---|
| LCD1602 window | 66 × 17.5 at (0, **+51.95**), wall cut | [V1] |
| LCD module | 80 × 36 glass 11.5 above the inner face, 4 × M2.5 bosses 6 × 6 at 75.1 × 31 pitch | [REF] |
| R307 window | **19.3 × 21.2** at (+35.95, −24.1) + **21 × 25 × 1.6** bezel relief (a 25 × 27 relief cut 1.55 mm into both M3 posts) + 1.2 mm seat ribs, 0.35 fit | [V1] |
| R307 module | sits on 2 posts 6 × 6 × **23.5** tall at x = 22.0 / 50.0, y = −24.1, ⌀2.5 pilots | [REF] |
| R307 bracket | 33.5 × 12 × 2 steel, ⌀3.0 + ⌀5.6 counterbores, 28 mm hole centres → `VERIFY_ACTUAL_HARDWARE` | [EST] |
| RC522 recess / window | 62.7 × 44.7 × **1.0** recess, **56 × 38 open window + 2 × 2.5 bars** at (−20.05, −24.05); board on 1.0 mm locating ribs, plane z 3.0 … 4.6 | [V1] + fix |
| RC522 fixings | 4 × 8 × 8 pads, 2.5 mm tall (⌀2.2 × 4.1 pilot) at (−20.05 ± 22, −24.05 ± 27) + 2 printed clamp bars (62 × 15 platform + 0.9 lip, ⌀3.0 hole / ⌀5.6 × 1.4 head recess, 44 mm centres) | new |
| ESP32 bay | on the **−X wall**, board plane X = −42.6 (10 mm standoff), Y −70 … −18.55, **Z centre 27.5** | [REF] |
| ESP32 pads | 4 × 8 × 8 pads, ⌀2.2 pilots 7 mm deep | [REF] |
| USB slot | **18 × 10** at Z 27.5 on the bottom edge (+2.4 chamfer), plug body 15.6 × 8 fits | [REF] |
| Fan | 3010 at (Y **17**, Z **24**) on the −X wall, ⌀26 grille + 3 bars, 4 × M3 posts (24 mm) | [REF] |
| Exhaust | **4** slots 20 × 4 in the bottom wall | — |
| Top vent | 3 slots 16 × 3 at X −18 / 0 / 18, Z 26 (−X wall, above the fan) | — |
| Rear plate | 110 × 155 × 3 flush + 2 mm register lip + 2 mm spine ribs, 4 × M3 into 9 mm bosses at (±46.5, ±71) | — |
| Keyhole hang | ⌀7.5 + 4.6 mm slot, 50 mm span, on the plate centre line | — |
| Cable ties | **4** posts ⌀8 with ⌀4 through-holes at (−10, −66), (16, −66), (44, 12), (−48, −66) | — |
| Corners / rims | front-face corners r3.0 (0.12 mm overshoot so the fillet never ends tangent → no sliver faces); 1.0 mm chamfer on the shell rim and the plate rim | new |
| Plate fixings | 4 × M3 into 9 mm bosses at (±46.5, ±71) with **⌀6.6 × 90° countersinks** (flat heads sit flush) + ⌀7.5 / 4.6 mm keyhole hang, 50 mm span | — |

## §11 Named keep-out & check objects (exact names required in the file)

`ESP32_RF_ANTENNA_KEEP_OUT` · `RC522_RF_KEEP_OUT` · `RC522_SCAN_ZONE` · `R307_OPTICAL_WINDOW` ·
`PRINT_BED_ENVELOPE` · `FASTENER_SCHEDULE` · `CABLE_PINCH_CHECK` · `SCREWDRIVER_ACCESS_CHECK`

Each is a real object/record in the model or audit file — not a comment. Keep-outs are rendered in
the wireframe review and are proven empty by boolean volume in §21.

## §12 `ESP32_RF_ANTENNA_KEEP_OUT`

The DevKit’s PCB antenna is at the top edge of the board (the end away from the USB socket).
No metal, no screw, no boss and no printed wall may enter **the 25 × 15 × 8 mm volume at that end +
2 mm of air in front of it**; the bay is oriented so the antenna points **away** from the fan, the
RC522 antenna and the rear plate fasteners. Verified empty (§21, section B).

## §13 `R307_OPTICAL_WINDOW`

The R307’s 19 × 21 mm optical window must be a genuine through-window in the 3 mm front wall — no
printed material, no glue ridge, no flash-over across the optical area; proven by a through-ray
(section C). Around the window a **25 × 27 mm relief thins the bezel to 1.6 mm**, so the module’s
20 mm shoulder sits against a flat 1.6 mm shelf instead of a 3 mm step, while the module itself is
carried by the two 6 × 6 × 23.5 mm posts and the bracket — its sensor face lands flush with the
cavity-side face of the front wall (z = 3.0), so the fingerprint is taken straight through the
window.

## §14 Airflow / thermal path

Fresh air enters the **4 bottom slots (2 rows × 2) in the bottom wall**, crosses the ESP32 bay and the RC522 pocket, is pushed
by the **3010 fan** (Y 17, Z 24) through the ⌀26 grille, and leaves through the **3 top vents**.
Measured areas: low intakes 4 × (20 × 4) = **320 mm²**, outlet 3 slots × (16 × 3) = **144 mm²**,
grille free area = 531 mm² aperture − 231 mm² of bars = **300 mm²** (56 % of the aperture, 33 % of
the fan’s 30 × 30 face). Inlet 1.07 : 1 and outlet 0.48 : 1 against the grille free area — more than
enough for a build dissipating well under 1 W; the fan is a circulation aid, not a cooling
requirement, and the grille is kept open so it can never stall against back pressure.
No vent is placed above the LCD electronics. Fan screws are reachable from the rear opening with a
100 mm driver (verified, §16).

## §15 `CABLE_PINCH_CHECK`

Every internal cable route must have **≥ 2 mm** clearance from any moving/closing surface and must
not be trapped by the plate lip or a rib. Routes: LCD ribbon and I²C (LCD → board), R307 5-pin
(through the 25 × 27 relief), RC522 SPI (right of the pocket), fan 2-pin (fan → board), 5 V feed
(bottom edge). The **truncated bottom-left rear boss** exists only to keep the DC/USB corridor clear;
it starts at Z 33 instead of the wall and never crosses the cable path.

## §16 `SCREWDRIVER_ACCESS_CHECK`

Every screw must be reachable by a straight driver from an opening, with the tool axis clear:

| Screw set | Driver axis | Verified clearance |
|---|---|---|
| 4 × M3 plate → bosses at (±46.5, ±71) | along −Z through the plate | clear, boss counterbore ⌀2.5 |
| 4 × M3 fan posts | from the rear opening, along −X | clear (cable ties moved to (−10, −66)/(16, −66), RC522 rim below Z 5.5, fan screws Z 12–36) |
| 4 × M2.2 ESP32 pads | from the rear opening, ±20° of the wall normal | clear, 10 mm standoff |
| 2 × M3 R307 bracket | from the rear of the LCD pocket, along −Z | clear, bracket sits on the 23.5 mm posts |
| 4 × M2.5 RC522 clamps | from the rear opening, along −Z | clear, pads sit in the 44 mm band between the clamp bars’ lips |

## §17 Printability & `PRINT_BED_ENVELOPE`

* `PRINT_BED_ENVELOPE` ≥ **120 × 165 × 50 mm** (the 110 × 155 × 48 part + brim).
* **Supports: none.** Designed orientation: front face down, rear opening up. Measured unsupported
  overhang > 60°: **155 mm² = 0.18 % of the surface** — all of it is the 3 mm rear register lip
  edge, which bridges/curls harmlessly.
* Minimum wall 1.45 mm (RFID web) / 2.4 mm everywhere else; minimum feature 2 mm (stiffener bars),
  minimum hole ⌀1.8 (pad pilots).
* With the front face on the bed the RFID window and its two stiffener bars are printed in the
  first layers directly over the bed, so they have no unsupported span at all — the long span that
  survives in the slicer is closed. The only bridge-like features are the top vents (16 mm) and the
  USB slot roof (18 mm), both short and both bridged across solid material.
* Print mass is reported, not guessed: ≈ 71 g PLA at 15 % infill for the shell.

## §18 `FASTENER_SCHEDULE`

| Qty | Screw | Into | Pilot | Function |
|---|---|---|---|---|
| 4 | M3 × 10 | rear plate → 9 mm bosses | ⌀2.5, 9 mm deep | close the enclosure |
| 4 | M2.5 × 12 | LCD ↔ 6 × 6 bosses | ⌀2.5, **8.5 mm deep** | hold LCD at 11.5 mm |
| 2 | M3 | R307 bracket → 6 × 6 posts | ⌀2.5, **8.0 mm deep** | hold the fingerprint module |
| 4 | M3 × 20 | fan → posts | ⌀2.5, 12 mm deep | fan retention |
| 4 | M2.5 × 6 | ESP32 corner pads | ⌀2.2, 7 mm deep | board standoff |
| 4 | M2.5 × 6 | 2 clamp bars → RC522 pads | ⌀2.2, 4.1 mm deep | hold the RC522 down |
| 4 | cable ties | ⌀8 posts, ⌀4 through-holes | — | strain relief |

Nothing is priced. No screw is invented. **22 circular pilot holes in total** (LCD 4, R307 2,
RC522 4, ESP32 4, fan 4, plate 4) — every one proved empty in the middle *and* surrounded by material
(§21-I), with a clear 6 mm screwdriver path over its whole length (§16 / §21-J).

## §19 Verification-first build order (the “no claim without a measurement” rule)

Build in this order and re-run the whole audit after every change:

1. Place the component envelopes from the real numbers in §5.
2. Derive the cavity, then the outer shell (walls §6).
3. Hollow the cavity **first**, then union bosses/pads/posts (otherwise the pocket cut deletes them).
4. Cut all openings/pilots, then **re-union** anything that must live inside a cut (grille bars,
   stiffener bars, plate ribs) with ≥ 0.5 mm overlap into its host — this is what keeps the STL a
   single watertight body.
5. Prefer an **open-ended** pilot: it must break through exactly one surface (the screw entry) and
   stop 0.9–1.5 mm short of the other. A pilot that touches no surface becomes an enclosed void and
   the STL splits into “extra bodies” (§25.4).
6. Re-audit: `python3 tools/build_v2.py` → `docs/v2_audit.txt`. The STL must report
   **`watertight=True`, `bodies=1`** before any other number is quoted.

## §20 Blender implementation requirements (if the model is authored in Blender)

* One object per real part, named exactly (`ESP32_DevKit_V1`, `RC522`, `R307`, `LCD1602_I2C`,
  `Fan_3010`, `Main_Shell`, `Rear_Plate`, `R307_Bracket`, plus the keep-out objects of §11).
* Never join/merge into a single mesh. Never apply a boolean that erases a named object; use them as
  boolean *tools* and keep the originals in a separate collection.
* Origin of every object at its own datum; the shell’s origin at the front-face centre.
* Solids only — no zero-thickness planes, no non-manifold edges, no inverted normals, no duplicate
  vertices; run *3D-Print Toolbox → Check All* and quote the result.
* Booleans: exact, self-intersection off after each cut; apply modifiers; no ngon > 12 verts.
* Text/annotations live on a separate `ANNOTATIONS` collection and are exported to the drawing
  sheet, never to the STL.

## §21 Audit / scorecard (must be delivered with every revision)

Report as a table with `measured`, `target`, `verdict ∈ {PASS, FAIL, VERIFY_ACTUAL_HARDWARE}`:

* **A printed-part interference** — shell ↔ plate, shell ↔ bracket: 0.00 mm³ required.
* **B component fit** — every envelope (§5) vs shell: 0.00 mm³ overlap required.
* **C openings** — for each opening: *through?* and *is there still wall beside it?* both must be yes.
* **D other printed parts** — plate and bracket: watertight, right bbox.
* **E thickness probes** — ray-measured wall/feature thickness vs design (±0.15 mm).
* **F dimensional audit** — model vs the §5 reference table, flagging `VERIFY_ACTUAL_HARDWARE`.
* **G printability** — overhang area %, support requirement, wall summary.
* **H STL file re-read** — reload every exported STL from disk and count open edges, non-manifold
  edges and bodies (0 / 0 / 1 required). In-memory watertightness is not enough: the *file* is what
  the slicer reads.
* **I screw fixing map** — every screw fixing must be a **circular pilot hole** with the hole empty
  (proved by a point inside it missing the mesh) *and* surrounded by material (proved by a point in
  the wall hitting the mesh). 22 holes are checked this way, group by group.
* **J polish / assembly features** — 12 probed features that only exist to make the part usable:
  rounded front corners (rounded *and* material kept), front-rim chamfer + material below it, plate
  rear chamfer, plate corner round, plate countersink open + wall kept behind it, the RC522 seat rib,
  the RC522 ledge ring, the R307 seat rib, the strain-relief post. Each is two probes: the feature is
  there, and the material that makes it useful is still there.
* **K independent re-verification** — `tools/verify_v2.py` re-opens *only* the exported STLs (it
  imports nothing from the generator) and re-measures 12 groups of facts: mesh integrity, 240 slice
  cross-sections, a 4 mm wall-thickness map, every component envelope re-typed from first principles,
  every pilot radius measured with 8-way rays, opening escape rays, 0.2 mm layer printability, driver
  access cylinders, the RF path, the printed-part fits, mesh dimensions and mass. Output:
  `docs/v2_independent_verify.txt`; it exits non-zero if anything fails.

**Delivered revision result (all lines measured, none assumed):**

```
shell     : watertight=True, bodies=1, volume 116.1 cc
shell size: [110.0, 155.0, 45.0] (depth 45 + 3 mm plate = 48)  plate 110 x 155 x 7
volume    : shell 116.1 / plate 79.6 / bracket 0.75 / clamp 1.58 x2 cm3  ~123 g PLA (15 % infill)
A  shell<->plate 0.00 PASS   shell<->bracket 0.00 PASS
B  LCD glass / PCB+backpack / bezel / R307 / RC522 board+components+scan zone /
   ESP32 board+components / ESP32 RF keep-out / USB plug / Fan 3010   ALL 0.00 PASS
C  LCD window, R307 window, RFID scan window, USB slot, fan grille,
   exhaust slot, top vent                               open=True wall_ok=True PASS
D  rear plate 110 x 155 x 7 watertight 79.6 cc ; R307 bracket 33.5 x 12 x 2 watertight ;
   RC522 clamp 62 x 15 x 2.5 watertight 1.58 cc (print 2, second rotated 180 deg)
E  front 2.90 / RFID ledge ring 1.95 / stiffener bar 1.90 / side 2.35 / top 2.90 /
   bottom 2.90 / LCD boss 11.50 / R307 post 23.50 / fan ring 1.35                 PASS
F  all model dims match the reference table (2 items VERIFY_ACTUAL_HARDWARE)
G  overhang 155 mm2 = 0.18 %  -> SUPPORT_REQUIRED = NO
H  re-read from disk: 4 parts = 0 open edges, 0 non-manifold edges, 1 body each;
   9 + 7 sub-micron sliver faces where the corner fillet meets the rim chamfer
   (all < 1 um2, at x +-54.3 / y +-76.8, z 0.25 / 15.1) - cosmetic, slicers ignore them
I  22 screw pilot holes (LCD 4, R307 2, RC522 4, ESP32 4, fan 4, plate 4) all
   hole-empty + material-around PASS, + 4 x d4.0 cable-tie holes
J  12/12 polish + assembly probes PASS
K  independent STL-only re-verification: 12 sections, 0 failures
   (docs/v2_independent_verify.txt) - incl. thinnest wall 1.20 mm (fan ring),
   0 of 11100 samples of the 12 mm RF scan volume inside material, 240/240 valid
   slices, 22/22 pilot radii measured to +-0.05 mm, 198.0 cc total material
RESULT: ALL CHECKS PASS
```

## §22 Deliverables

1. `cad/v2/01_MAIN_SHELL_v2.stl`, `02_REAR_PLATE_v2.stl`, `03_R307_BRACKET_v2.stl`,
   `04_RC522_CLAMP_v2.stl` (watertight, single body each) — **print part 04 twice, rotate the second
   copy 180° about Z**.
2. `docs/v2_audit.txt` — the scorecard above, regenerated by the build.
3. `renders/v2_shell_drawing_sheet.png`, `renders/v2_exploded_iso.png`,
   `renders/v2_fixing_detail.png` (exploded + section proof of the RC522 screw fixing — in the
   section, bright material is what the cut plane passes through and dim material sits behind
   it, so a reader cannot mistake background for a cut face; the section is dimensioned with
   the stack-up wall 3.0 / board 1.6 / lip 0.9 / platform 1.6 / pad 2.5 and the 4.1 mm blind
   pilot that leaves 1.4 mm of wall underneath) , `renders/v2_all_views.png` (all four sheets
   on one page) and `renders/rfid_before_after.png` — annotated views.
4. `viewer.html` — interactive, self-contained 3D review of all parts (both revisions).
5. `tools/build_v2.py` — the parametric source; **the model is the script**, so any dimension change
   re-derives the whole enclosure and re-runs the audit.
5b. `tools/verify_v2.py` + `docs/v2_independent_verify.txt` — the independent check: it reads only the
   exported STLs and re-measures the same facts from scratch, so a mistake in the generator cannot
   hide behind itself.
6. `docs/master_prompt.md` — this file.
7. `exports/ASTRO_SMART_ATTENDANCE_v2.zip` — everything above in one archive (STLs + drawing sheet +
   audit + this prompt + the generator script).

## §23 Open items — `VERIFY_ACTUAL_HARDWARE`

1. ESP32 pad hole centres (inset 3.5 mm assumed after measuring a DOIT V1).
2. RC522 corner-hole pitch — **not used**: the board is held by two clamp bars over its short edges,
   so no RC522 hole is relied on at all. Board outline 60 × 40 × 1.6 confirmed.
3. R307 bracket hole pitch (28 mm centres assumed, matching the module’s body holes).
4. LCD + I²C backpack total depth (18.24 mm assumed; the 11.5 mm boss height + 1.6 mm PCB gives
   1.5–2 mm of cable space — if the delivered module is deeper, raise `lcd_glass_t` and re-run).
5. Fan thickness ≥ 10 mm (if a 10 mm fan is fitted with a gasket, raise `fan_post`).

The 60 × 40 board's fixing pads are printed at ±22 / ±27 mm from the recess centre — that is *our*
choice of where to grip the board, not a hole position on the module, so it cannot be wrong.

If any of these measures differently on the delivered hardware, change the parameter in
`tools/build_v2.py`, re-run, and re-issue the audit table. That is the whole point of the parameter
table: **no dimension is hard-coded twice.**

## §24 Review workflow (how a revision is presented)

1. `python3 tools/build_v2.py` → STLs + `docs/v2_audit.txt` (scorecard §21).
2. `python3 tools/make_sheet_v2.py` → `renders/v2_shell_drawing_sheet.png` (front / iso / −X side /
   rear plate, annotated from the same parameter table) and `renders/v2_exploded_iso.png`.
3. `viewer.html` served over HTTP — rotate/zoom, Iso/Front/Side/Top/Rear, Explode, Half-cut, and
   per-part visibility, with the v1 parts kept alongside for comparison.
4. Quote `RESULT:` line of the audit verbatim in the reply. If it is not `ALL CHECKS PASS`, the
   revision is not delivered — the failing line is the work item.

## §25 Anti-patterns that already cost this project a revision (do not repeat)

1. **A closed pocket floor over the RFID antenna** — the v1 shell had 3 mm of plastic across the
   whole RC522 recess: the reader could not scan. Any wall in front of an antenna is a defect.
2. **Hollowing the cavity after the bosses were added** — the pocket cut deletes bosses, so thickness
   probes read 0. Order: hollow → union structure → cut openings → re-union in-cut features.
3. **Edge-contact unions.** Two ribs that meet exactly on a shared edge (or two solids that touch
   on a face) produce a non-manifold edge counting four faces: trimesh reports
   `watertight=False` on the exported file even though nothing is open. Overlap every union by
   ≥ 0.5 mm (here 1.0 mm) in **both** in-plane directions and re-check section H.
4. **Pilots that open into nothing.** A blind hole that touches no surface becomes an internal void;
   the STL then reports several “bodies” with negative volume and slicers disagree. Every pilot must
   break through exactly one surface (screw entry) and stop short of the other (§19.5).
5. **Reversed box coordinates** build a mirrored 12-face solid that reports “watertight” and then
   fails every boolean. Sort coordinates in the box helper.
6. **Oversized boolean cutters** that remove the wall they were meant to leave, and **coplanar cut
   faces** that leave zero-thickness skins — offset every cutter 0.1–2.0 mm past the face.
7. **Retainer hooks over a board** — a hook that intrudes 0.5 mm into the board envelope is a fit
   failure even if it “looks right”; the envelope test is the judge.
8. **Interference “fixed” by deleting the part** — shell↔plate clashes are relief/height problems:
   add the register-lip relief, shorten the boss, never remove the feature.

## §26 Acceptance checklist (done = every line ticked)

- [x] RFID scan window open through the front wall over the whole antenna, keep-out proven empty.
- [x] Fingerprint optical window open, sensor 1.6 mm proud, posts exactly 23.5 mm.
- [x] LCD window/bezel matches the 80 × 36 module and the 75.1 × 31 hole pitch.
- [x] ESP32 bay sized from 51.45 × 28.33, antenna keep-out clear, USB plug passes the slot.
- [x] Fan grille + 4 posts at 24 mm, pilots reachable by a driver from the rear.
- [x] Enclosure derived from the layout; walls 2.4–3.0 mm; fit 0.35 mm; clearance 1–2 mm.
- [x] Single watertight body, no supports, front-face-down print.
- [x] Every part a separately named object; no card, no card holder, no prices, no fictional parts.
- [x] Every module fixed by **circular pilot holes** (22 holes, hole-empty + material-around proved).
- [x] Scorecard delivered with measured values; unresolved items marked `VERIFY_ACTUAL_HARDWARE`.

---

## §27 v3 APPENDIX - the complete re-design (and what a v4 must not lose)

v2 kept failing the human test: after every repair the box still looked like the box. v3 is
therefore **not** a re-tune. `tools/build_v3.py` is a fork of the v2 generator whose *decisions*
were replaced, and it re-derives the same keep-outs, envelopes and proof figures. If you rebuild
again, these are the eight decisions that make v3 what it is - keep them or beat them with a
measurement, never silently revert them:

1. **Depth is an output, not a choice.** 46 mm = 3.0 front wall + the RC522 stack (1.6 board +
   2.6 ring + heads) + the ESP32 bay + 3.0 cover. v2's 48 mm was 2 mm of solid rear plug.
2. **Side walls 2.6 mm** (v2: 2.4) and a flat 3.0 mm fan wall; the thinnest *sheet* in the print
   is the 2.2 mm band the RC522 lies on.
3. **The scan aperture is one opening**: 38 x 56 (portrait, since v3.2), R5 corners, no bars,
   no floor, no recess
   material inside it. Proof: `K1` ray-scans 8269 points masked to the same rounded rectangle
   the geometry uses - 0 blocked. A rectangular grid over a rounded opening reports a false
   failure at its own corners; a rectangular metric over a rounded feature reports a false pass.
4. **The RC522 is held by one flat ring**, printed once: its inner lip stands 0.5 mm inside the
   aperture, its 4 corner tabs land on 4 pads whose tops are coplanar with the board's front
   face (z = 4.6), and 4 x M2.5 pull it down into blind d2.05 x 3.8 pilots (the thread's minor,
   not nominal) with 1.4 mm of wall left under them. The tabs are generated FROM the pad offsets
   `(rc522_post_off)`, never typed - v3.0 typed them and 22 mm of tab hung in air after the swap. No clamp bar crosses the antenna, no reliance on the module's own hole pitch.
5. **Rebate rings, not flush cuts**: 0.45 x 3.0 mm sunk around the LCD and fingerprint openings,
   so each module's bezel registers on the rebate floor (2.55 mm of wall remains under the ring).
   The fingerprint opening is the *bezel relief* footprint (21 x 25) with the 19.3 x 21.2 optical
   window inside it - the ledge that v2 left between the internal pocket and the rebate was
   1.15 mm and is deleted.
6. **Rear plate = register frame** (2 mm proud, 0.25 mm per side, 8-sided) with the whole ESP32
   zone cut out by ONE clearance box. Per-boss notches and rib-splitting both failed: the ESP32
   has 4 bosses *and* 2 locating tabs, and the -Y rib's end collided too. Build the frame
   continuous, then subtract one generous box; 90 of 148 mm of register remains, plenty for
   4 screws. 53.8 cm3 instead of a 79.6 cc solid plug (v3.1 added the relief cut through the
   skin, which is +2.4 cc of frame and -0 mm of interference).
7. **Air path (v3.3, closed out in v3.4 - see §31)**: the fan does the work, so the fan's own bore
   *is* the inlet - d28, 615 mm2, no grille and no seat lip, and the fan is mounted blowing IN. v3.3
   gave the outlet to two grilles, 8 x (21 x 4.5) in the bottom wall and 4 x (21 x 4) in the top,
   1069 mm2 = 1.74x the bore; **v3.4 filled all twelve slots in**, so the bore is the box's only air
   opening and cooling is carried by the    skin (2.7 K passive, 1.8 K with the fan's through-flow). The right-hand wall is **plain**: v3.2 had cut 8 x 30 x 5 slots there (1157 mm2) and they
   were paid for in stiffness for a wall that no longer does any breathing. Slots, never round
   holes - a d5.0 hole 5.5 mm from a 3 mm wall leaves a 2.0 mm ligament and splits on the spool's
   own tension - and no row of slots may leave a web thinner than the wall it is cut in (the
   18 x 5 / 2.5 mm-web version failed the audit and was re-cut). v2's 3 grille bars left 50 % of
   the bore closed.
8. **Everything is measured twice.** `build_v3.py` sections A-K (interference, envelopes,
   openings, other parts, probes, printability, STL re-read, the 22-hole pilot census, the
   bed envelope, the measured v2->v3 deltas) and `verify_v3.py`, which imports nothing from the
   generator - re-types the reference dimensions, re-cuts the meshes, re-measures every pilot
   diameter with 8 rays at 3 depths, slices every 0.2 mm, and re-derives the outer dimensions.

### New checks worth keeping in any future verifier
* `K1`/`K2` aperture and bore ray-scans (masked to the real shape) - catches "opening" claims
  that a bar or a lip quietly invalidates.
* `K3` pad-top flatness probes + the bearing-face probes - the ring only works if the surface it
  sits on is one plane; probe the *feature*, not a point 30 mm away that lands on a side wall.
* `K4` plate volume vs the plug it replaced - a fit relief that adds plastic back is a design
  regression even when every hole passes.
* "the register is a frame, not a plug": count material inside the opening at z = shell top
  (v3: 19.3 % of the opening area, all of it the frame).
* driver access as a 6 mm x 25 mm cylinder swept from outside to each head; the R307 bracket
  needed 13 mm of *lateral* corridor, so measure access along the actual approach direction.
* hole-position checks must go through the section's world transform. `Path2D` frames are offset
  (here by (+6.45, +9.05) mm), so a hole centre read straight out of `to_2D()` will not match a
  design coordinate and a filter on "is this the RFID opening" will find nothing.
* envelope boxes must be built from absolute min/max coordinates. A helper that centres a box on
  the origin turns a whole clearance section into a false PASS (it happened, and the fix was to
  re-run the section, not to re-state the numbers).

### Figures a rebuild must regenerate (additions to §22)
`v3_drawing_sheet.png`, `v3_exploded_iso.png`, `v3_fixing_detail.png`, `v3_fixing_section.png`,
`v3_all_views.png`, `v3_vs_v2.png`, `v3_grille_map.png` (v3.4: the opening inventory of the four
side walls, lifted out of a mid-thickness slice of the shipped shell and labelled with the size it
measured; it exits non-zero unless the counts are 1 / 0 / 0 / 1). The two fixing panels are cut from the shipped STLs with
`mesh.section()`, so they cannot drift; `v3_vs_v2.png` renders both versions with the same
`projection()` call, which is what makes "it looks unchanged" impossible to argue with.

## §28 v3.1 / v3.2 APPENDIX - the physics round (a third checker, and what it caught)

After both CAD checkers said PASS the box was still not *physically* checked, so
`tools/audit_physics_v3.py` was written: 10 sections, no re-use of the generator's numbers, each
one re-measured off `cad/v3/*.stl`. It is now the third gate and has to say
`PHYSICS RESULT: no failures` before a pack is cut.

| section | question it answers | verdict on the shipped model |
|---|---|---|
| 1 fasteners | is each pilot at the thread's minor, and will the thread pull out? | play 0.01-0.05 mm; 75-362 N per screw vs the 0.15-0.88 N it actually holds |
| 2 clamping | is anything crushed, and is any head too tall for the gap behind it? | LCD bezel and R307 shoulder in compression; every head clears the plate |
| 3 kinematics | can each part actually be *installed*, straight in, no tilting? | all 6 modules + the plate descend with 0 blocked samples |
| 4 airflow | can the box still shed its heat with one hole? | v3.4: 0 grille slots anywhere (measured), the bore is the only air opening (615 mm2); skin path 2.7 K, through-flow 0.25 L/s at 12.2 Pa (5.4 K), both in parallel -> **1.8 K** at 1.6 W against a 12 K ceiling; the plate-seam area is the one ASSUMED row and is warn-only |
| 5 optics | can the sensor see a finger, and can a human read the display? | 1815 of 1815 cone samples clear of the ring; LCD visible to 113 deg |
| 6-7 RF | does plastic or metal sit in front of an antenna? | RC522 0 of 4350 points in material (aperture 100 % open), ESP32 keep-out 0 of 4350, no copper within 6 mm of the trace |
| 8 plastic stress | plate peel, hook shear, wall ligaments, countersink edge distance | 289x peel reserve; hooks 0.16 MPa vs 8.5; RFID<->R307 ligament 22.50 mm; countersink wall 2.25 mm |
| 9 slicer reality | first layer, overhangs, thin sheets, density, thermal | 11 469 mm2 single contour, 0.30 % of faces steeper than 60 deg (244 mm2), all >= 2.2 mm, 159 g, PETG note |
| 10 doc truth | does every sentence in the pack match the triangles? | re-greps the docs, checks the required strings AND every `cm3` figure against the mesh volumes |

**Four real defects it found, all fixed in the geometry - not in the text:**
* **F11 (v3.1) - the plate's countersinks opened onto a corner round.** A d6.6 x 90 deg cone at
  (+/-50, +/-71) left 0.08 mm of plastic on one side: it would print as a lip that shears off, and
  the flat head would sit on air. Fixed by moving the 4 plate screws to (+/-46.5, +/-67.5) and
  keeping the corner rounds; measured wall now 2.25-3.80 mm.
* **F12 (v3.1) - the ESP32 fit relief was cut *through* the plate skin.** v3.0's "clearance" was a
  hole: the board saw 0 mm of gap but rain and dust had a 34 x 20 mm doorway. Fixed by reliefs on
  the frame's 4 vertical ribs and the +/-X ribs only, so the 3 mm skin stays continuous; the mid-
  thickness slice of the skin must show **exactly 6 voids** (2 keyholes + 4 countersinks) - the
  verifier fails if a 7th appears. Plate 51.4 -> 53.8 cm3 (+4.9 g) for a closure that closes.
* **F13 (v3.2) - the RC522 could not be installed.** Landscape, the board is 59.6 mm wide and the
  front-wall bay between the ESP32 post ends (x -42.4) and the R307's -X post (x +15.95) is
  **58.35 mm**; every dodge path is closed by the fan standoffs (y 1..7 and 27..33). Rotated to
  portrait: 40.6 across, 58.4 along, drops straight in with 6.4 mm to spare, and it lengthened the
  thin RFID<->R307 ligament from 17.50 to 22.50 mm as a bonus. Side effect the user wanted: the
  front face now visibly differs from v2 (portrait swipe window).
* **F14 (v3.2) - the two checkers disagreed on mass by 50 g.** `verify_v3` applied a blanket 0.62
  factor; the shell is a thin-walled box where 3 perimeters x 0.45 mm fill a 2.6 mm wall *solid*.
  Both now use the same model - walls solid, 3 skins, 15 % core.  v3.3 printed at 155 g / 6.4
  sets; v3.4 at 159 g and 6.3 sets, where the audit's layer-by-layer sum and the verifier's
  typed fractions land 0.6 % apart (159 g vs 158 g) and the docs say so rather than smoothing
  it over.

**Accepted by design (recorded as notes, not failures):** the M2.5 pan head ends 0.90 mm proud of
the ring's inner face (it sits in the recess, on the PCB side - it never touches the rear plate);
and if the unit is mounted on an unshaded outside wall, print in PETG because the top surface of a
black-ish PLA box in Indian sun passes PLA's 55-60 deg heat-deflection point.

**Rules a rebuild must keep from this round:**
1. Every module must enter by **descending along one axis** with 0 blocked samples at every
   intermediate position - check kinematics, not just the final assembled overlap.
2. An opening's **duty has to be re-homed before the opening is deleted**. v3.3's rule was that the
   passive openings stay >= 1.5x the fan bore; v3.4 deleted them anyway, on the user's instruction,
   so the rule was replaced rather than ignored - the audit now proves the remaining path is the
   skin plus the register seam and that dT stays under the ceiling. Slots (not round holes), and no
   web between neighbouring openings thinner than the wall they are cut in, still apply to whatever
   openings a version does have.
3. Countersink edge distance >= half the cone diameter, measured to the *real* outline.
4. A closure plate gets no through-holes for clearance; relieve the register instead.
5. Any feature that reaches a mounting pad is **generated from the pad's offset**, never typed.
6. Pilots are at the thread's minor (2.05 / 2.50 / 1.80), never nominal.
7. Reader header over the pads must be <= ~6 mm (the channel under the ESP32 posts is 9.8 mm) or
   fit the reader before the ESP32; no M3 at the ESP32's antenna end, and no steel or brass
   washers under those heads.
8. A claim in a doc is a measurement the third checker re-runs: when geometry changes, the doc
   edit is part of the fix (`docs/v3_physics_audit.txt` section 10 refuses a stale number).

## §29 v3.3 APPENDIX - the fan does the work, so the perforated side wall went away

Asked for in one line: *"remove the right side many grooves - for that I have fan"*.  v3.2 had cut
8 x 30 x 5 mm stadium slots into the +X wall (1157 mm2) to feed the fan; the user's point is that a
fan moves air by itself, and the wall paid for openings that were doing nothing a sealed box could
not do without.  The change is a **real design change**, not a re-tune, and it was built, cut and
re-measured like one:

* `P["side_intake"] = False` deletes the +X wall's cut entirely.  `True` puts v3.2 back in one
  rebuild, and the build self-test switches its checks with it - a reversal must cost archaeology,
  not interpretation.
* The ⌀28 fan bore stops being an exhaust and becomes the **inlet**: the fan is mounted **blowing
  IN** (arrows on its frame pointing at the box).  The box then sits a little above ambient, so air
  leaks *out* through the RFID aperture and the LCD rebate instead of dust being pulled in past the
  R307 prism.
* The passive openings take the whole outlet duty, so they grew: **8 x 21 x 4.5 mm** in the bottom
  wall (4 columns at +/-12.5 / +/-37.5, rows at z 7.0 and 15.0) and **4 x 21 x 4 mm** in the top
  wall at z 26 - 1069 mm2 together, measured off the mesh, **1.74x** the bore against a rule of
  >= 1.5x.  Duty point against the fan's straight line: A_eff 533 mm2, 0.84 L/s at 1.9 Pa
  (84 % of free air), the whole 784 cm3 box changed every 0.9 s, dT 1.6 K at 1.6 W.
* Sealing the wall and leaving v3.2's bottom/top grilles as they were was **rejected on numbers**:
  452 mm2, 0.73x the bore - the fan would have run near its choke point.
* The first v3.3 cut (18 x 5 slots at z 7 / 14.5) was **rejected by the audit**, not by taste: the
  web between the rows measured 2.50 mm, thinner than the 3.0 mm wall it sits in, and
  `audit_physics_v3.py` section 8 failed it.  Height 5 -> 4.5, pitch 24 -> 25, width 18 -> 21 paid
  the web back (3.50 and 4.00 mm) *and* the area.
* A fourth figure, `renders/v3_grille_map.png`, draws each side wall's mid-thickness section with
  every void labelled at the size it measured - 0 openings in the right wall is the headline.

**What a v4 must not lose from this round:** the wall an opening is in is not the wall it belongs
to - an opening that does not serve a path, a fastener, an antenna or a user is a defect with a
reason attached.  And when the user says a feature is redundant, check whether the *duty* it was
doing is redundant too; here it was not, so the duty moved and the numbers were re-run.

## §30 v3.3 APPENDIX 2 - a fifth print, so the user can measure their own hardware

The user's five `VERIFY_ACTUAL_HARDWARE` unknowns are sizes, and a size can be handed over as
plastic.  `tools/build_gauge_v3.py` cuts `05_FIT_GAUGE_v3.stl`: a 150 x 112 x 2.60 mm card with one
10.00 mm boss, seven stations, and no dimension typed a second time - it slices the parameter block
out of `build_v3.py` and executes it, exactly as `check_grooves_v3.py` does, then sizes the card from
those numbers.  A **cut is a GO gauge** (the wall has the same hole: pass here, pass there) and an
**engraved line is a reference outline** (calipers, or a fingernail).  No standing pins or ribs: a
gauge with a 10 mm pin needs supports, and support-free was a hard rule, so everything on the card is
a through-cut, a blind pocket or an engraved pocket.  The digits are a hand-written 7-segment renderer
(0.50 deep pockets) because a printed letter needs a font and this project has never put text in an
STL before; `x` is not in the set, so sizes read `66.0-17.5` with a hyphen.

`tools/check_gauge_v3.py` then measures 59 things off the shipped STLs and nothing else: the card's
own body (150.000 x 112.000 x 12.600, 2.60 thick in three places), all 8 through-gauges to 0.02, the
4 board holes and 6 pilot diameters and depths, the tick pitch of the rule, the engraving depth, that
no face needs a support, and then the four fit gauges **against the wall they exist to match** -
the front wall profiled at five planes, the median taken, the card required never to be bigger.
It ends `GAUGE RESULT: EVERY GAUGE MEASURES AS DESIGNED, AND NONE IS BIGGER THAN THE WALL`.

Three lessons worth keeping, each of them a bug the checks caught rather than a claim I made:

* **watertight is not printable.** The card's first version was watertight with *inward* normals - a
  slicer may print that hollow.  `is_volume and volume > 0` is now part of the build's own verdict,
  and `fix_normals()` runs before the export.
* **coplanar pockets break a boolean.** Twelve open edges came from extruding thirty engraved pockets
  as separate prisms whose walls touched.  Union each plane's pockets in 2-D, extrude once.  It also
  halved the triangle count.
* **a probe must answer the question the gauge asks.** "How many void stretches are inside my search
  window?" counted the far side of the part and the neighbouring hole; "which stretch contains the
  centre?" is the size of the feature.  And the refinement has to start two samples back, because a
  sample landing exactly on a surface makes the bracket contain no crossing at all - that is what a
  d1.80 pilot reading 1.750 actually was, half a step lost at each side.

Registered like any other part: `orient_v3.ORIENT["05_FIT_GAUGE_v3.stl"] = (0.0, "card flat on the
bed, engraved face up")`, an `assembly/` copy, the pack's STL/PROOF/FIGS/SRC lists, both viewers, and
step 0 in the print order - before the shell, because checking is what should come first.

## §31 v3.4 APPENDIX - "only let that DC fan one": the grilles are gone

Asked for with the box already on screen: *"remove all unnecessary like that hollow on the right
side, no need for those hollows - only let that DC fan one, that is best, not more, and last check
and give me the final STL files"*.  Twelve openings were deleted and the model was re-measured from
end to end rather than re-labelled:

* `P["grilles"] = False` in `tools/build_v3.py` is the whole change: it gates both vent-cutting
  loops, and the builder's self-test in section J switches to the opposite assertions - the bottom
  wall must be solid at all 8 old slot centres, the top wall at all 4, and the bore and the USB
  opening must still be there.  `True` puts v3.3 back in one rebuild.
* The shipped shell now measures **115.2 cm3, 11 108 triangles, 0 open edges, 1 body** (v3.3:
  112.0 cc, 14 426 triangles - filling twelve slots added plastic and removed 3 318 triangles of
  slot outline and corner arcs at the same time).  Overhang 296 -> **244 mm2 (0.30 %)**; first layer
  11 469 mm2; the other three parts are byte-identical to v3.3, so only `01_MAIN_SHELL_v3.stl`
  changed and the gauge card still needs no reprint.
* The four walls, sliced at mid-thickness off the STL (`verify_v3.py` §6b): bottom **1 void**
  (the 20.40 x 12.40 USB opening), top **0**, +X **0**, -X **1** (the d28 bore, 615 of 616 mm2
  clear).  36 more probes fire 9 rays each at every old slot centre and both ends of every old slot
  and all 324 of them are blocked, which is the difference between "the design says filled" and "the
  mesh is filled".  `make_grille_map_v3.py` draws the same four sections and exits non-zero on any
  other count.
* The physics is the part that could have been quietly broken by an aesthetic request and was not:
  section 4 of `tools/audit_physics_v3.py` was rewritten from an orifice-sizing check into a
  two-path heat check, because after this change there is no grille left to size.  Measured/derived:
  skin 1.6 W over 0.0585 m2 at h = 10 W/m2.K -> **2.7 K**; through-flow with the 127 mm2 register
    seam *[ASSUMED row, warn-only, because it is a property of your print]* -> A_eff 125 mm2,
  0.25 L/s at 12.2 Pa, the 784 cm3 box every 3.2 s, **5.4 K**; in parallel the box settles at
  **1.8 K** - v3.3 measured 1.6 K with 1069 mm2 of grille open, so the whole trade is 0.2 K.  The
  flow fell to 30 % of v3.3 and the temperature barely moved, because a 28 mm bore was always what
  limited a 3.6 m3/h blower, not the plastic.
* Two consequences recorded instead of hidden: the fan is now part of the enclosure (a 30 x 30
  frame spans the bore with 1 mm all round, so a box used without the fan has a 28 mm hole in its
  side), and the through-flow duty passes to the seam, which is why the ring/aperture fit of the
  plate still matters as much as it ever did.

**The lesson, stated as a rule for the next version:** when an opening is deleted, the *check* that
judged it has to be replaced by a check that judges what is left - a green gate inherited from the
old geometry is a green light for a design that no longer exists.  That is why §4 of the audit was
rewritten in the same commit as the geometry, and why both the builder and the verifier gained
assertions that can only pass on a wall with nothing in it.

---

## 32. v3.5 (2026-10-08): four files in the pack, sizes closed from vendor data

Requested: drop `05_FIT_GAUGE_v3.stl` from the pack ("let there only those 4"), make the dimensions
exact by searching for the real component data instead of asking the user to measure, and state the
screw sizes definitively.

* **Pack**: `tools/make_pack_v3.py` now ships 4 STLs and no gauge — the gauge entry in `STL`, its two
  `PROOF` entries, the `fit_gauge` figure filter and its three `SRC` tools were removed.  The gauge
  chain still exists and still passes in the repo, so this is reversible by adding one filename back.
* **Geometry unchanged, deliberately.**  Every module was looked up (design notes §10 carries the
  sources and the table) and the model already matched: R307 44.1 × 20 × 23.5 with a 19 × 21 window;
  1602 + backpack 13.2–20.0 deep against 24.0 reserved; 3010 30 × 30 × 10 on 24 ± 0.3 with ⌀3.2 holes;
  ESP32 51.45 × 28.33 and 52 × 28 × 14 with headers against `esp32_comp_h=16.0`.  What changed is the
  *labels*: the `[REF]` comments on those blocks in `tools/build_v3.py` are now `[WEB 2026-10-08]`
  citations, so no triangle moved and the four STLs are byte-identical to v3.4.
* **New fact that rewrote a document rather than a model**: the R307 has no mounting holes — the stock
  kits clamp it with a bracket and two long screws.  The old advice "measure the R307 bracket pitch
  (assumed 28.0)" was therefore wrong in the harmless direction: that pitch is ours, and free.
* **Still open, and it stays open**: DOIT never published the DevKit V1 pad-hole diameter (⌀2.5
  reported by owners, ⌀3.0 on the nearest same-family drawing).  Both M2.2 and M2 pass it, so the box
  cannot break on it; the print order names the substitute and the forbidden substitution (no M2.5
  there, never M3).
* **Rules added**: a `[REF]` dimension must name the vendor page that supports it.  "Ask the user to
  measure" is allowed only after the published data has been exhausted, and vendor data for a generic
  module is labelled as *vendor data for a generic module* — never as the buyer's own unit.

## 33. v3.6 — the `.blend`, and the day the screw lengths got measured

The ask was `now for the full 3d create a full .blend model`.  Not a viewer and not a converter: a real
native Blender scene, so the deliverable is the file a buyer would have made by hand in Blender — printed
parts, modules, fasteners, rig.  It was built with the official `bpy` wheel (4.5.14 LTS, headless, the
container's missing X11/GL symbols satisfied by no-op stubs in the gitignored `pylibs/stubs/`), so
**Blender itself wrote the `.blend`** and every number below was read back out of the saved file, never out
of the script's memory.

`tools/make_blend_v3.py` imports the four bed-aligned STLs, restores each to the assembly frame with the same
`tools/orient_v3.py` table the pack was built with, and refuses to hand-type fastener geometry: it calls
`tools/hole_probe_v3.py`, which measures each hole's bearing face, its void depth and the plastic left behind
it, and places one screw per measured hole at a length that hole can take.  Output:
`exports/ASTRO_SMART_ATTENDANCE_v3.blend` (74 objects, 61 meshes, 3.58 MB),
`exports/ASTRO_SMART_ATTENDANCE_v3_assembly.glb` (57 meshes, 1 unit = 1 mm), three Cycles frames
`renders/v3_blend_front.png`, `v3_blend_iso.png`, `v3_blend_exploded.png`, and `docs/v3_blend_build.txt`.
`BLENDER BUILD: ALL CHECKS PASS`.

Two rules were honoured rather than restated.  (1) *The model must be the shipped model*: the builder
re-measures the volumes off the triangles it imported (115.22 / 53.80 / 1.01 / 2.19 cm3, 172.22 total) and
fails if they disagree with the published figures, asserts the assembly box is 110.00 × 155.00 × 46.00 mm, and
asserts each part's lowest point *is* the lift its `dz` in the orientation table — which is what proves the
`.blend` shows the part that prints rather than a relative of it.  (2) *Nothing is taken on the builder's own
word*: `tools/check_blend_v3.py` opens the saved file, shares no code with the builder, re-derives every
solid's volume from its own polygons in world space, checks that all 22 screw axes land on measured hole
centres to 0.000 mm and stop above the pilot bottom, moves the timeline to confirm the seven explode groups
really travel (4 out through the front, 1 through the back, 2 through the fan wall), re-imports the `.glb`
and proves the copies agree to 0.05 mm, and samples the pixels of the three renders so a black or blank frame
would fail.  `BLENDER RESULT: ALL CHECKS PASS`, exit 0.  No STL byte changed and `tools/build_v3.py` was not
re-run.

What the exercise caught is the part worth keeping.  Every screw length in the pack had been written from
design intent: diameters were measured (8 rays per hole, in the audit and in the verifier), depths never
were.  Against measured room, `M2.5 × 12` for the LCD had 9.00 mm and would have floated the display 3.0 mm
off its bosses; `M2.5 × 8` for the reader ring had 4.70 mm and would have stood 3.3 mm proud, which is more
than the 0.5 mm the ring overlaps its pocket lip, so it cost the register as well as the seat; `M3 × 10` for
the R307 bracket had 8.60 mm (1.4 mm past its room, 1.8 mm past the bottom of the pilot).  All three are
corrected in the print order and the design notes.  The same pass proved that no pilot in the enclosure is a
through-hole — the thinnest skin under one is 1.40 mm, under the RC522 pads — and, the hard way, that an
unprinted `stack` may only contain material that is *not* in the mesh the void was measured on: counting the
printed bracket's 3.2 mm twice manufactured phantom room and hid a real over-length.  Two render faults were
chased down as well: an ortho front camera aimed at the −Y face (this case's front is the z = 0 plane), and a
USB plug drawn as the envelope generator's full 22.5 mm slab, which hung 14 mm outside the box.  The plug is
now drawn 2 mm proud of the wall with the clearance envelope untouched, and `check_blend_v3.py` carries a
rule that nothing in the file may poke outside the 110 × 155 × 46 box plus 2.5 mm.  A display flaw is still
only a display flaw — and a hole that cannot take the screw it was promised is not a display flaw.

Open, unchanged by this round: the ESP32 pad-hole diameter (2.5 mm reported by owners, 3.0 mm on the nearest
same-family drawing) decides M2.2 vs M2 and moves no geometry; `P["grilles"] = True` still brings back the
twelve slots; re-adding `05_FIT_GAUGE_v3.stl` to `make_pack_v3.py` still re-ships the fit gauge.

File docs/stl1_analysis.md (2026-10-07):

# STL 1 — `01_MAIN_SHELL.stl` — what is in the file

Measured directly from the mesh (see `tools/` and `docs/stl_measurements.txt`).
Coordinates: **X = width**, **Y = height**, **Z = depth**, Z0 = the *device front* face,
Z48 = the rear (closed by part 02).

## Overall
| | |
|---|---|
| Overall size | 110.0 (X) × 155.0 (Y) × 48.0 (Z) mm |
| Triangles / shell | 4096 tris, 2018 unique vertices, closed shell |
| Wall thickness | 2.4 – 3.0 mm |
| Shell volume | ≈ 108.2 cm³ |

## Front face (z = 0)
| Feature | X | Y | Size | Depth |
|---|---|---|---|---|
| LCD1602 window (through slot) | −32.6 … 32.5 | 44.5 … 59.4 | 65.1 × 14.9 | through |
| Reader opening | 26.3 … 45.6 | −34.7 … −13.5 | 19.3 × 21.2 | through |
| Recessed pocket | −51.4 … 11.3 | −46.4 … −1.7 | 62.7 × 44.7 | 1.5 deep |

## Rear opening (z = 48)
102.9 × 150.2 mm, leaving a 3.0 mm rim all round → closed by `02_DETACHABLE_WALL_PLATE.stl`
(plate 110 × 155 × 9.45 mm, weight-relieved 1.5 mm deep on the inside, four ⌀4.35 mm corner holes).

## Left wall (x = −55)
Four vents, 2.8 × 11.8 mm, at Y ≈ 0.6 / 8.6 / 16.6 / 24.6, Z 11.1 … 22.9.

## Inside the shell
| Feature | Position | Notes |
|---|---|---|
| LCD frame | 4 bosses 12.7 × 12.7 mm, corners at ±37.55, 36.45 / 67.45 | z 3.0 … 11.0, ⌀1.5 pilots 4.5 mm deep |
| Rear standoffs | 3.3 mm square, x ±23.4…25.4 / 45.1…48.6, y 22.1…35.5 / 36.8…43.5 | z 37.5 … 40.0 |
| R307 retention | pads z 28.1 … 30.1, ⌀2.2 holes at (22.5, −24.0) and (49.5, −24.0) | pilot in shell at z 8.3: (22.4/49.4, −24.0) |
| RC522 retention | pads z 4.35 … 5.95, ⌀2.2 holes at (−52.0, −7.0) and (12.0, −7.0) | pilot in shell at z 5.5: (12.0, −7.0) |
| ESP32 retention | pads z 35.4 … 36.8, ⌀2.2 holes at (9.5, −25.0) and (46.5, −25.0) | |

## Other parts
| File | Size | What it is |
|---|---|---|
| `02_DETACHABLE_WALL_PLATE.stl` | 110 × 155 × 9.45 | rear wall plate, 4 corner holes ⌀4.35 at ±34, ±52 |
| `03_R307_RETENTION.stl` | 34 × 12 × 2 | bracket for the R307 fingerprint module |
| `04_RC522_RETENTION.stl` | 72 × 4 × 1.6 | bracket for the RC522 RFID reader |
| `05_ESP32_RETENTION.stl` | 44 × 4 × 1.4 | bracket for the ESP32 dev board |

## Views
`renders/shell_drawing_sheet.png` — 4-panel annotated drawing,
`renders/exploded_iso.png` — exploded assembly, `renders/*.png` — individual views.
Interactive: open `viewer.html` (rotate / zoom / explode / half-cut).

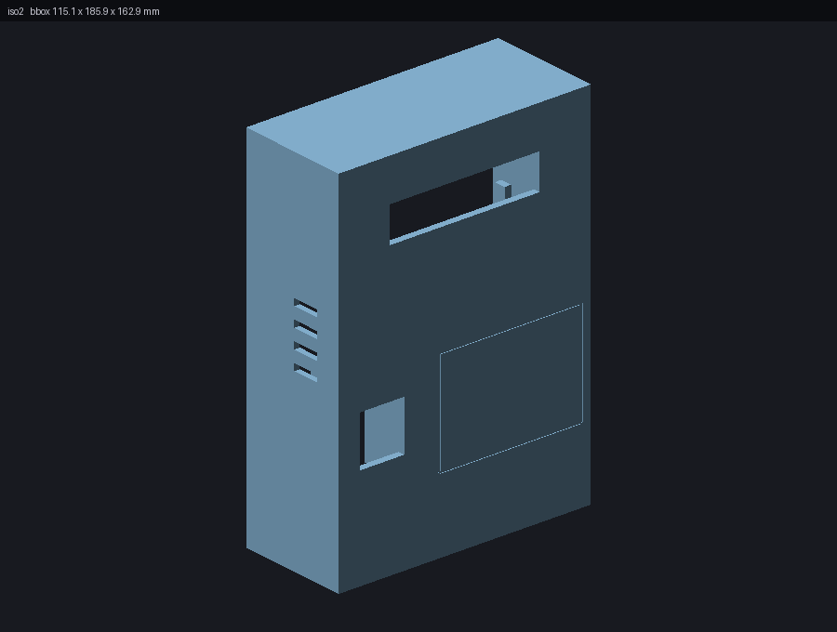
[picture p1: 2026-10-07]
renders/shell_iso2.png

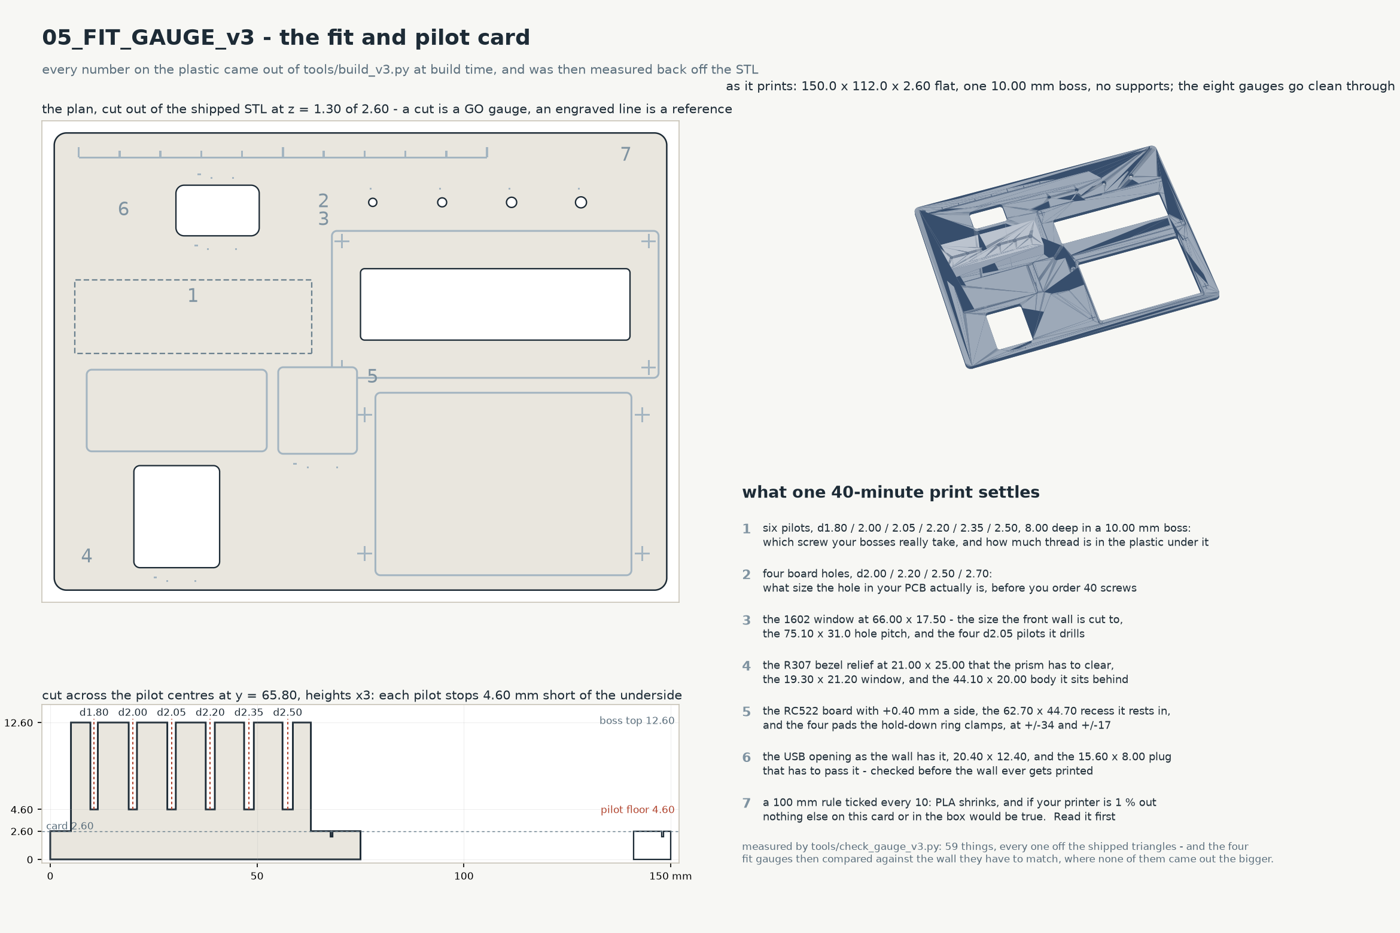
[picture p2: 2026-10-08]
renders/v3_fit_gauge.png

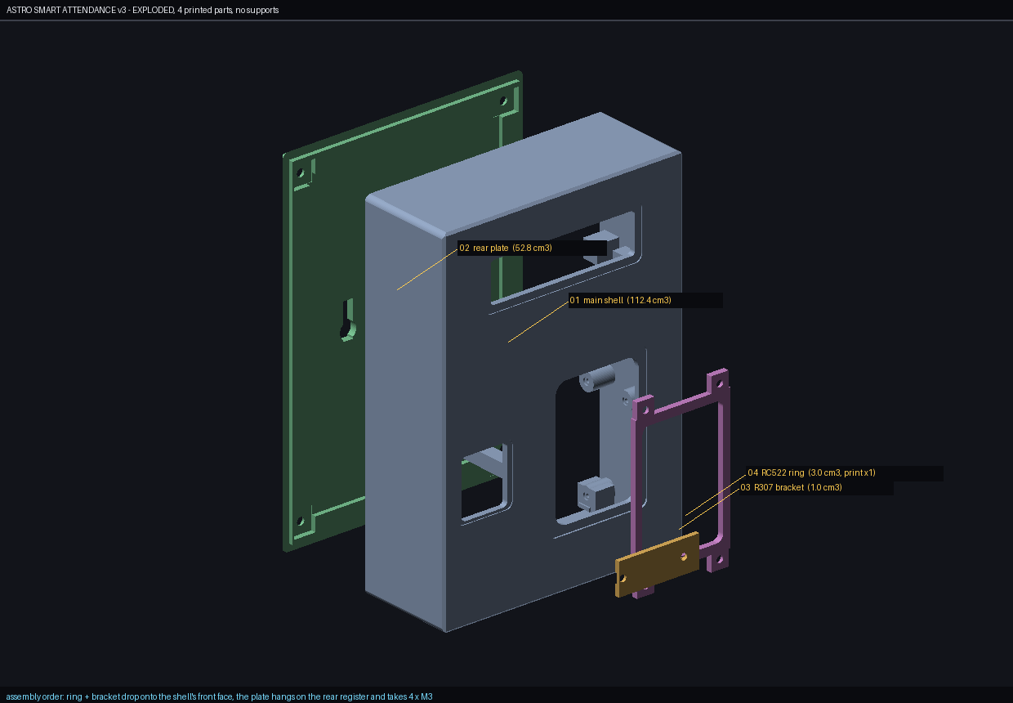
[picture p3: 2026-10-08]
renders/v3_exploded_iso.png

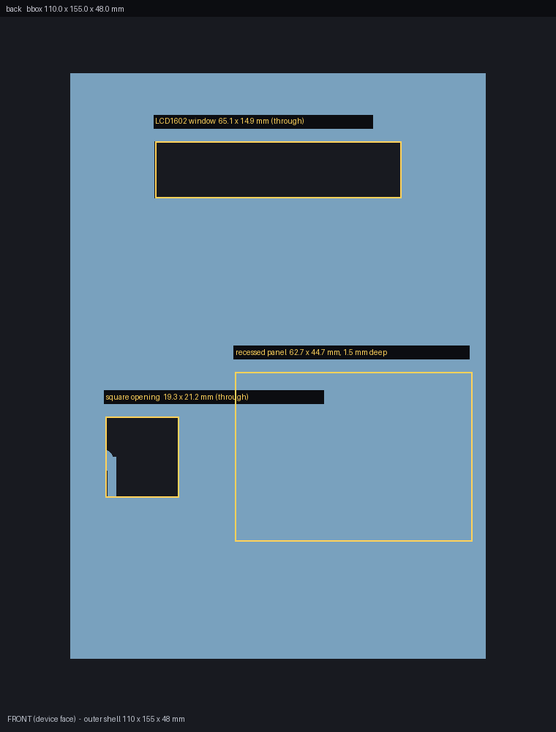
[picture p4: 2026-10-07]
renders/shell_front_annotated.png

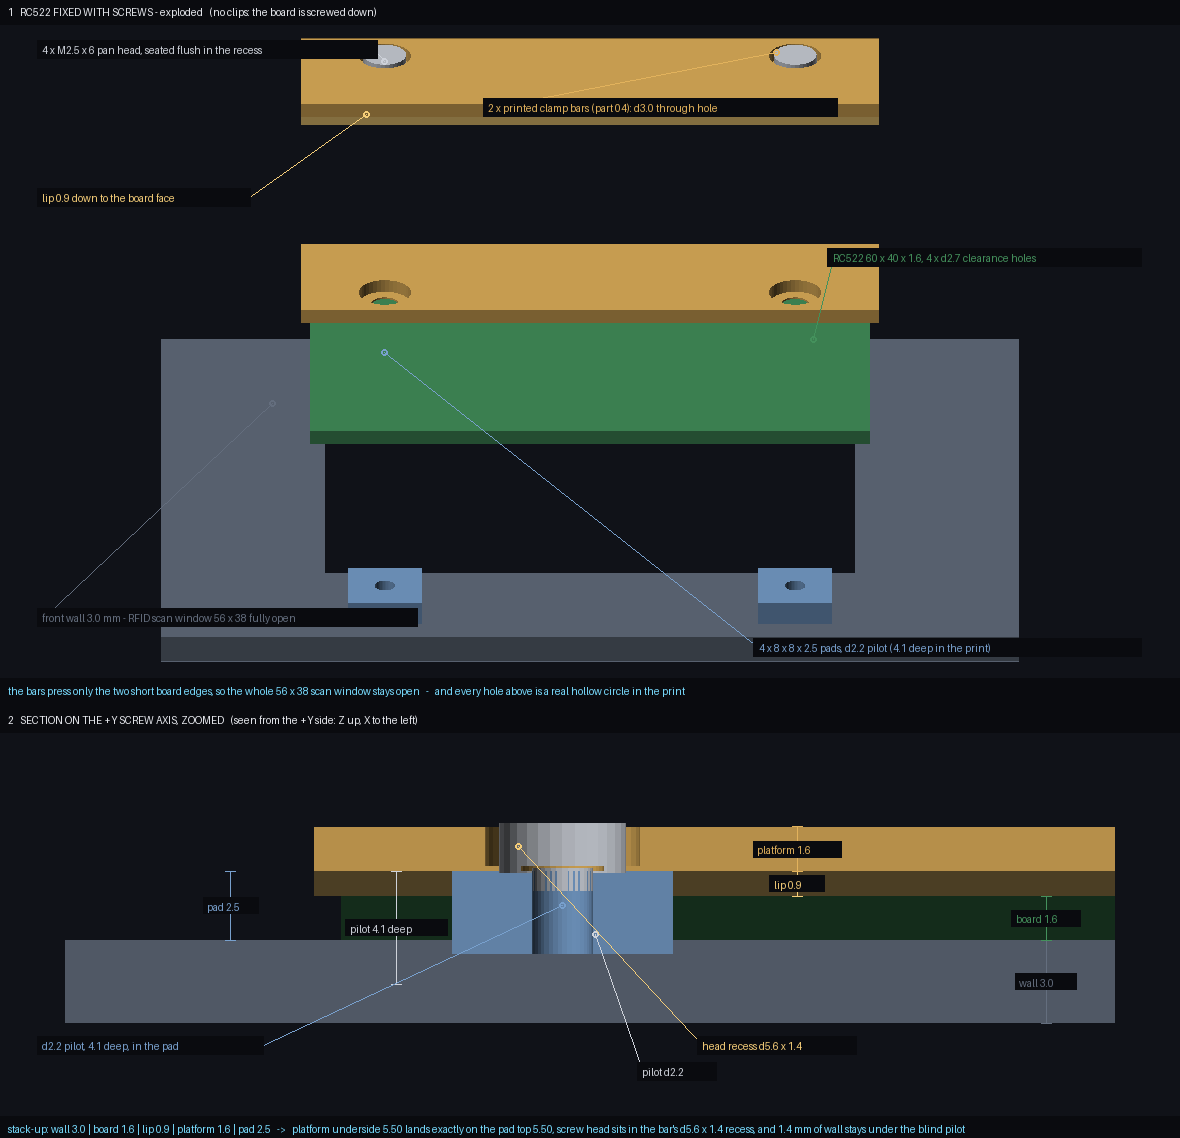
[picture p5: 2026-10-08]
renders/v2_fixing_detail.png

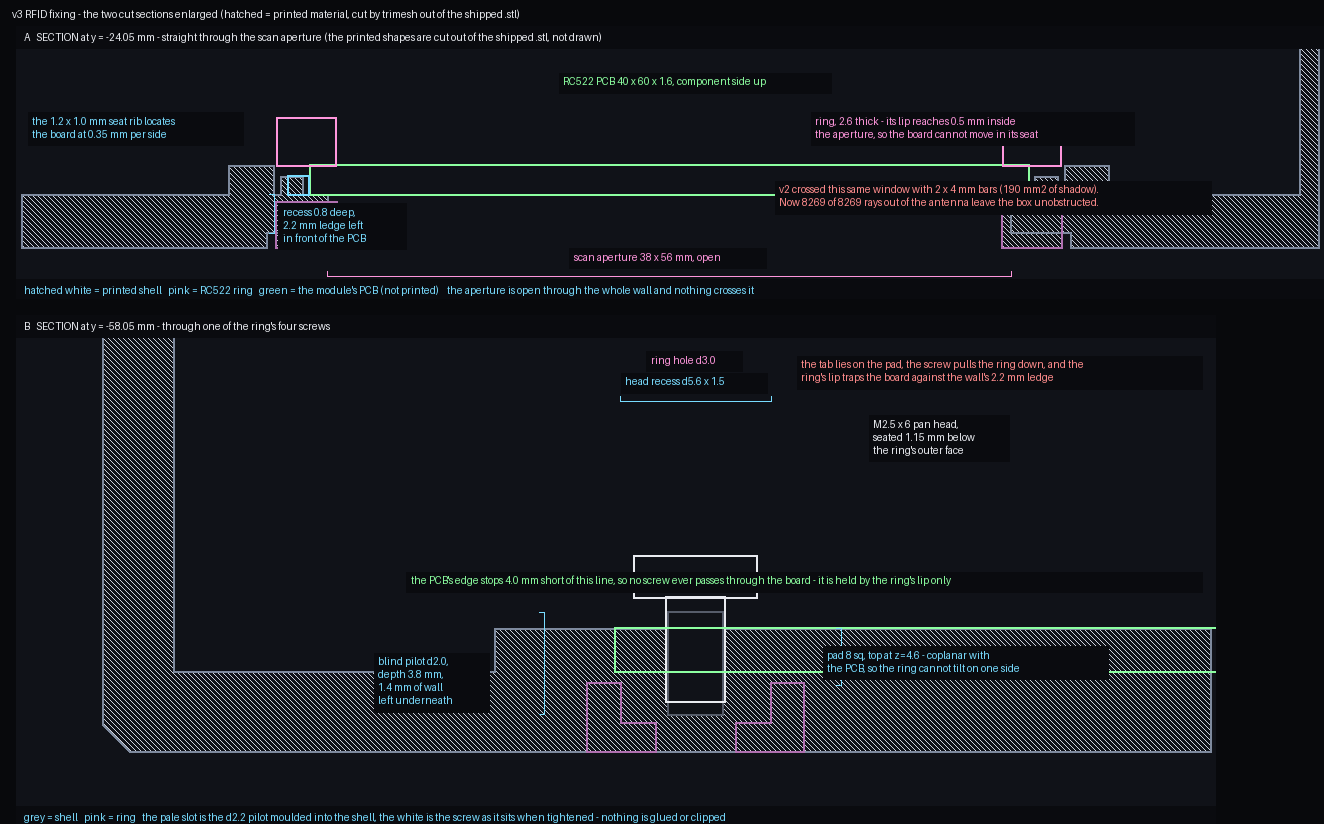
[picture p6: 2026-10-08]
renders/v3_fixing_section.png

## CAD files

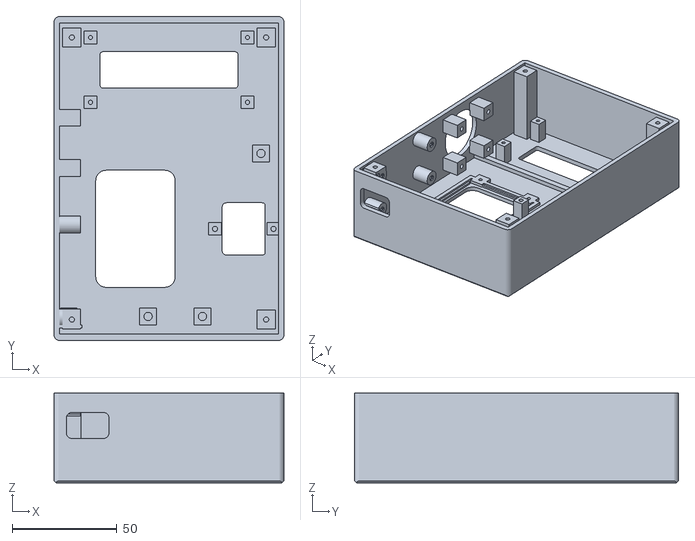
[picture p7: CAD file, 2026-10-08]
cad/v3/01_MAIN_SHELL_v3.stl
110.0 x 155.0 x 43.0

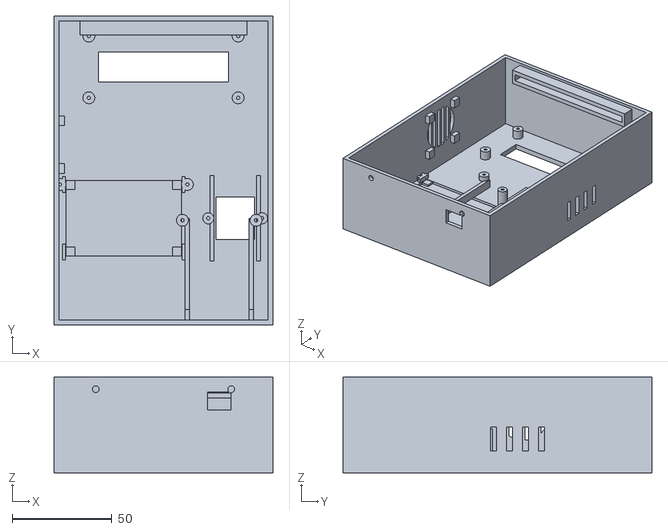
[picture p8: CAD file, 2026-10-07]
cad/01_MAIN_SHELL.stl
110.0 x 155.0 x 48.0

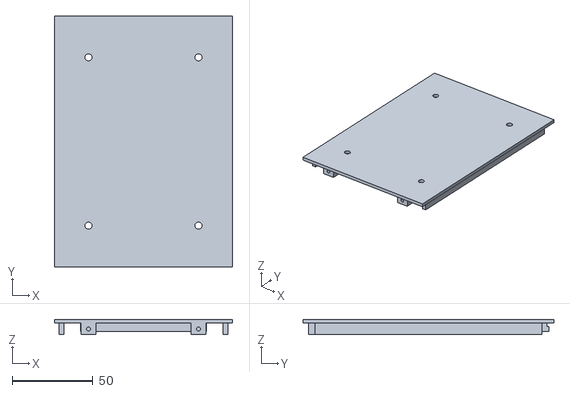
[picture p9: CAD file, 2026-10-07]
cad/02_DETACHABLE_WALL_PLATE.stl
110.0 x 155.0 x 9.45

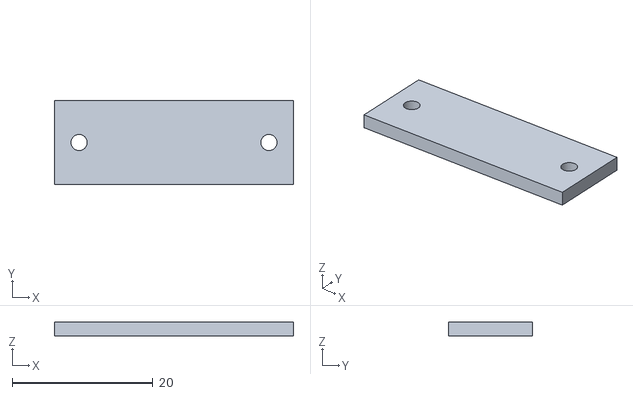
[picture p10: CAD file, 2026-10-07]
cad/03_R307_RETENTION.stl
34.0 x 12.0 x 2.00

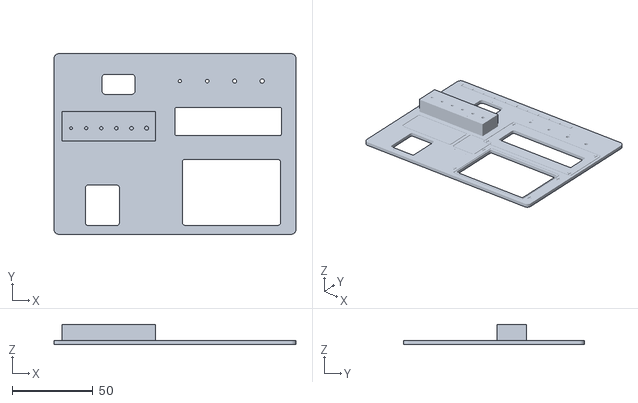
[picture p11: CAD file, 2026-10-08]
cad/v3/05_FIT_GAUGE_v3.stl
150.0 x 112.0 x 12.6

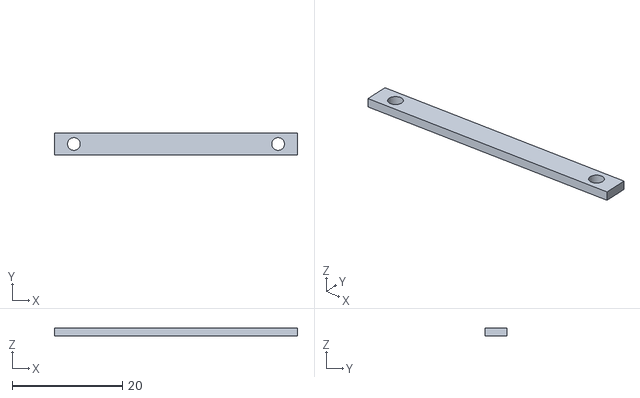
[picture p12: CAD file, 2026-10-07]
cad/05_ESP32_RETENTION.stl
44.0 x 4.00 x 1.40

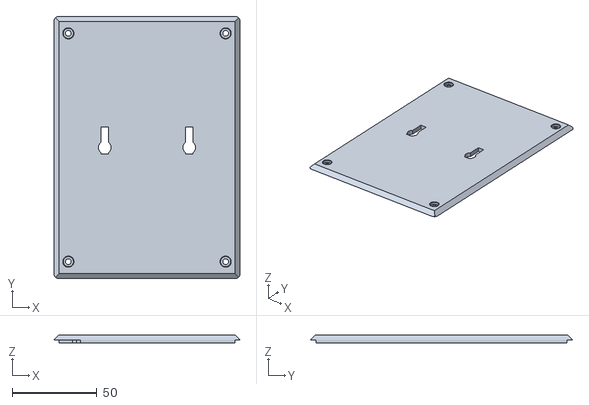
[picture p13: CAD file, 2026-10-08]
cad/v3/02_REAR_PLATE_v3.stl
110.0 x 155.0 x 5.00

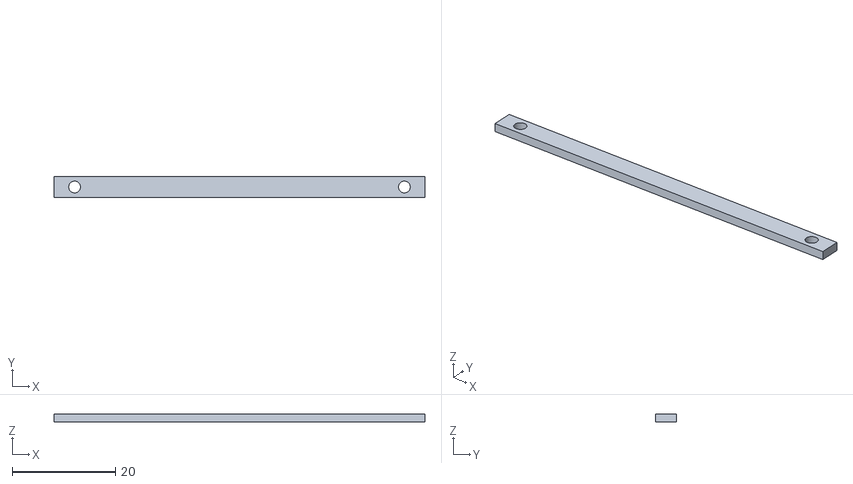
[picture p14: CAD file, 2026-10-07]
cad/04_RC522_RETENTION.stl
72.0 x 4.00 x 1.60

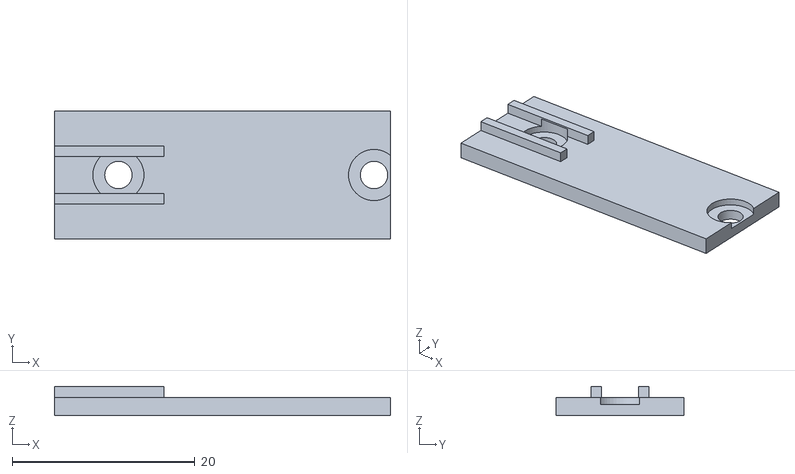
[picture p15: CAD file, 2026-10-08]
cad/v3/03_R307_BRACKET_v3.stl
36.8 x 14.0 x 3.20

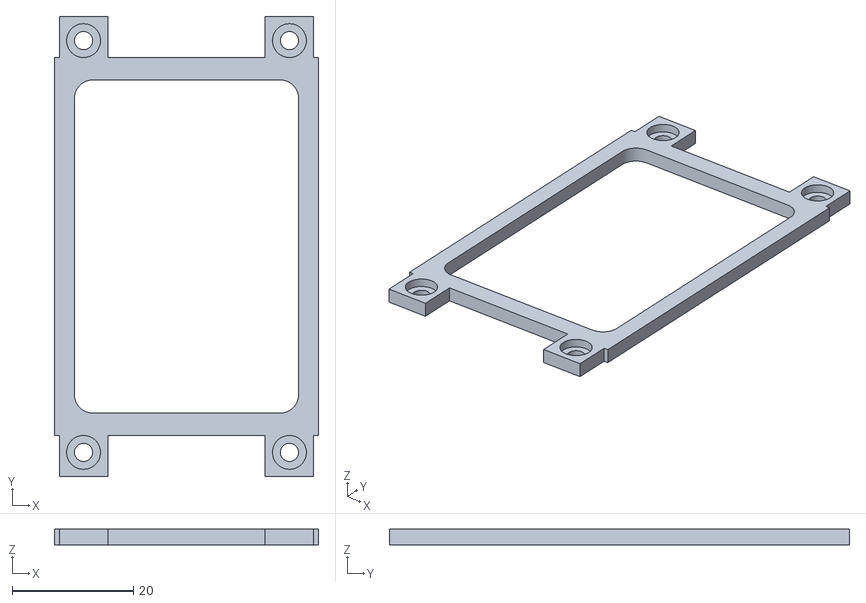
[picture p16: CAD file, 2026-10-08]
cad/v3/04_RC522_RING_v3.stl
43.6 x 76.0 x 2.60

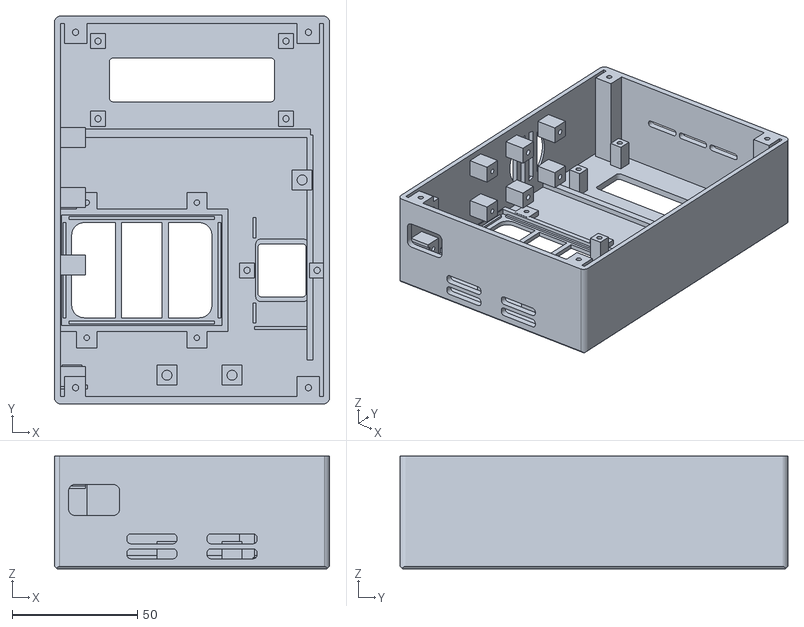
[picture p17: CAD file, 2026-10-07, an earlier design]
cad/v2/01_MAIN_SHELL_v2.stl
110.0 x 155.0 x 45.0

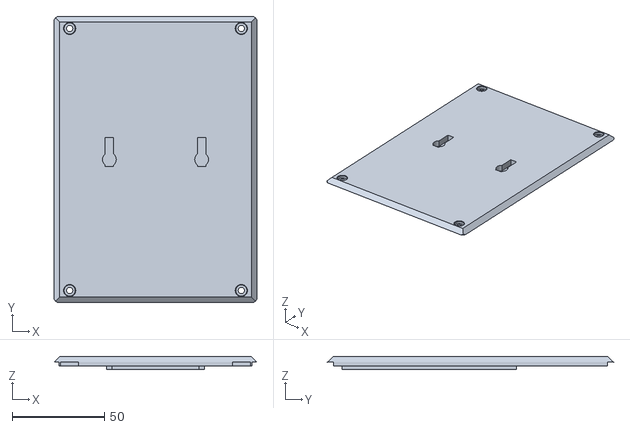
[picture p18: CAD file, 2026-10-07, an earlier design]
cad/v2/02_REAR_PLATE_v2.stl
110.0 x 155.0 x 7.00

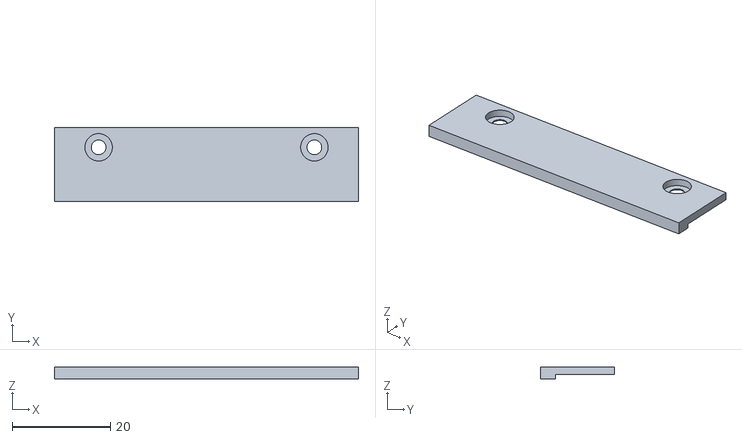
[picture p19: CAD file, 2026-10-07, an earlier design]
cad/v2/04_RC522_CLAMP_v2.stl
62.0 x 15.0 x 2.50

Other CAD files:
cad/v2/03_R307_BRACKET_v2.stl
exports/ASTRO_SMART_ATTENDANCE_v3.blend

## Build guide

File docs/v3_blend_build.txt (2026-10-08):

ASTRO SMART ATTENDANCE v3 - .blend BUILDER
================================================================================
Blender 4.5.14 LTS (headless bpy wheel)  |  units mm  |  generated by tools/make_blend_v3.py, nothing typed by hand

1. THE FOUR PRINTED PARTS  (assembly frame, from the shipped bed-aligned STLs)
--------------------------------------------------------------------------------
   01 MAIN SHELL: 115.22 cm3 in the .blend vs 115.2 cm3 documented, 11108 faces, watertight=True PASS
   01 MAIN SHELL: watertight, 1 closed body, 6 through-holes (genus 6) in the .blend mesh PASS
   01 MAIN SHELL: the bed-aligned copy sits at z = 0 (tools/orient_v3.py dz=0.0) PASS
   02 REAR PLATE: 53.80 cm3 in the .blend vs 53.8 cm3 documented, 3184 faces, watertight=True PASS
   02 REAR PLATE: watertight, 1 closed body, 6 through-holes (genus 6) in the .blend mesh PASS
   02 REAR PLATE: the bed-aligned copy sits at z = 0 (tools/orient_v3.py dz=41.0) PASS
   03 R307 BRACKET: 1.01 cm3 in the .blend vs 1.0 cm3 documented, 792 faces, watertight=True PASS
   03 R307 BRACKET: watertight, 1 closed body, 2 through-holes (genus 2) in the .blend mesh PASS
   03 R307 BRACKET: the bed-aligned copy sits at z = 0 (tools/orient_v3.py dz=26.5) PASS
   04 RC522 RING: 2.19 cm3 in the .blend vs 2.2 cm3 documented, 1912 faces, watertight=True PASS
   04 RC522 RING: watertight, 1 closed body, 5 through-holes (genus 5) in the .blend mesh PASS
   04 RC522 RING: the bed-aligned copy sits at z = 0 (tools/orient_v3.py dz=4.6) PASS
   assembly envelope off these four solids: 110.00 x 155.00 x 46.00 mm
   equals the documented 110 x 155 x 46 mm                                PASS

2. MODULES  (the generator's own envelope solids + a real 3010 with its bore and lug holes)
--------------------------------------------------------------------------------
   LCD1602 glass                   71.20 x  24.20 x  11.50 mm
   LCD1602 pcb + I2C backpack      42.00 x  19.00 x  12.50 mm
   R307 housing                    20.00 x  44.10 x  23.50 mm
   RC522 board                     40.00 x  60.00 x   1.60 mm
   RC522 components                44.00 x  28.00 x   6.00 mm
   ESP32 board + headers           16.00 x  51.45 x  28.33 mm
   USB plug in the slot            15.60 x  10.50 x   8.00 mm
   the USB plug is drawn to 2.0 mm proud of the y = -77.5 mm outer wall; the
   envelope the clearance check uses is unchanged, this is the picture, not the fit claim
   R307 glass (the optical window)  19.30 x  21.20 mm
      3010 fan (bored): 30 x 30 x 10 mm minus a d28 bore and 4 x d3.2 on 24 mm -> 2529 mm3 PASS

3. FASTENERS  (22 screws, each placed on a hole that was measured off the mesh)
--------------------------------------------------------------------------------
   LCD1602       M2.5 x  8.0 at (-37.55, 36.45)  void 7.00 deep, tip clears by +0.60 mm
   LCD1602 screw #1: seats in the void it was measured for, the axis is open at 8.60 mm of open void, pilot blind with 7.50 mm of wall left behind it PASS
   LCD1602       M2.5 x  8.0 at (-37.55, 67.45)  void 7.00 deep, tip clears by +0.60 mm
   LCD1602 screw #2: seats in the void it was measured for, the axis is open at 8.60 mm of open void, pilot blind with 7.50 mm of wall left behind it PASS
   LCD1602       M2.5 x  8.0 at ( 37.55, 36.45)  void 7.00 deep, tip clears by +0.60 mm
   LCD1602 screw #3: seats in the void it was measured for, the axis is open at 8.60 mm of open void, pilot blind with 7.50 mm of wall left behind it PASS
   LCD1602       M2.5 x  8.0 at ( 37.55, 67.45)  void 7.00 deep, tip clears by +0.60 mm
   LCD1602 screw #4: seats in the void it was measured for, the axis is open at 8.60 mm of open void, pilot blind with 7.50 mm of wall left behind it PASS
   R307 bracket  M3.0 x  8.0 at ( 22.00,-24.10)  void 8.20 deep, tip clears by +0.20 mm
   R307 bracket screw #5: seats in the void it was measured for, the axis is open at 8.20 mm of open void, pilot blind with 19.50 mm of wall left behind it PASS
   R307 bracket  M3.0 x  8.0 at ( 50.00,-24.10)  void 8.20 deep, tip clears by +0.20 mm
   R307 bracket screw #6: seats in the void it was measured for, the axis is open at 8.20 mm of open void, pilot blind with 19.50 mm of wall left behind it PASS
   RC522 ring screw #7: seats in the void it was measured for, the axis is open at 4.30 mm of open void, pilot blind with 1.40 mm of wall left behind it PASS
   RC522 ring screw #8: seats in the void it was measured for, the axis is open at 4.30 mm of open void, pilot blind with 1.40 mm of wall left behind it PASS
   RC522 ring screw #9: seats in the void it was measured for, the axis is open at 4.30 mm of open void, pilot blind with 1.40 mm of wall left behind it PASS
   RC522 ring screw #10: seats in the void it was measured for, the axis is open at 4.30 mm of open void, pilot blind with 1.40 mm of wall left behind it PASS
   rear plate screw #11: seats in the void it was measured for, the axis is open at 10.20 mm of open void, pilot blind with 34.00 mm of wall left behind it PASS
   rear plate screw #12: seats in the void it was measured for, the axis is open at 10.20 mm of open void, pilot blind with 34.00 mm of wall left behind it PASS
   rear plate screw #13: seats in the void it was measured for, the axis is open at 10.20 mm of open void, pilot blind with 34.00 mm of wall left behind it PASS
   rear plate screw #14: seats in the void it was measured for, the axis is open at 10.20 mm of open void, pilot blind with 34.00 mm of wall left behind it PASS
   fan 3010 screw #15: seats in the void it was measured for, the axis is open at 13.50 mm of open void, pilot blind with 1.60 mm of wall left behind it PASS
   fan 3010 screw #16: seats in the void it was measured for, the axis is open at 13.50 mm of open void, pilot blind with 1.60 mm of wall left behind it PASS
   fan 3010 screw #17: seats in the void it was measured for, the axis is open at 13.50 mm of open void, pilot blind with 1.60 mm of wall left behind it PASS
   fan 3010 screw #18: seats in the void it was measured for, the axis is open at 13.50 mm of open void, pilot blind with 1.60 mm of wall left behind it PASS
   ESP32 boss screw #19: seats in the void it was measured for, the axis is open at 8.60 mm of open void, pilot blind with 5.60 mm of wall left behind it PASS
   ESP32 boss screw #20: seats in the void it was measured for, the axis is open at 8.60 mm of open void, pilot blind with 5.60 mm of wall left behind it PASS
   ESP32 boss screw #21: seats in the void it was measured for, the axis is open at 8.60 mm of open void, pilot blind with 5.60 mm of wall left behind it PASS
   ESP32 boss screw #22: seats in the void it was measured for, the axis is open at 8.60 mm of open void, pilot blind with 5.60 mm of wall left behind it PASS
   22 screws placed, and the print order documents 22 screw holes         PASS
   LCD1602       recommended L=8.0 mm vs 9.00 mm of measured room         PASS
   R307 bracket  recommended L=8.0 mm vs 8.60 mm of measured room         PASS
   RC522 ring    recommended L=4.0 mm vs 4.70 mm of measured room         PASS
   rear plate    recommended L=10.0 mm vs 10.60 mm of measured room       PASS
   fan 3010      recommended L=12.0 mm vs 13.90 mm of measured room       PASS
   ESP32 boss    recommended L=8.0 mm vs 9.00 mm of measured room         PASS

4. RIG  (a 24-frame explode; the .blend shows how the thing goes together)
--------------------------------------------------------------------------------
   front_ring     ->   +0.0,   +0.0,  -22.0 mm      (11 objects)
   front_R307     ->   +0.0,   +0.0,  -38.0 mm      (2 objects)
   front_bracket  ->   +0.0,   +0.0,  -70.0 mm      (5 objects)
   front_LCD      ->   +0.0,   +0.0,  -50.0 mm      (10 objects)
   left_fan       ->  -62.0,   +0.0,   +0.0 mm      (9 objects)
   left_esp32     ->  -46.0,   +0.0,   +0.0 mm      (10 objects)
   rear_plate     ->   +0.0,   +0.0,  +62.0 mm      (9 objects)
   every object is either in an explode group or deliberately fixed (the shell) PASS

5. OUTPUT
--------------------------------------------------------------------------------
   ASTRO_SMART_ATTENDANCE_v3.blend  3,576,694 bytes, 74 objects, 61 meshes PASS
   ASTRO_SMART_ATTENDANCE_v3_assembly.glb  1,012,416 bytes (assembled, for any viewer that cannot open a .blend)
   Cycles CPU rendered the SAVED .blend -> renders/v3_blend_front.png (1,585,253 B)  ortho, the LCD rebate + reader aperture + ring centres PASS
   Cycles CPU rendered the SAVED .blend -> renders/v3_blend_iso.png (1,640,032 B)  assembled 3/4 PASS
   Cycles CPU rendered the SAVED .blend -> renders/v3_blend_exploded.png (1,727,796 B)  frame 24, exploded, all 22 screws clear of the holes PASS
   all 3 shots came out of the saved file                                 PASS

   blend sha256 0e8c2514e30bccd38f0d87a30cfd223a03c45e62

BLENDER BUILD: ALL CHECKS PASS

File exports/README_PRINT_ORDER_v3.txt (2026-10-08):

ASTRO SMART ATTENDANCE - ENCLOSURE v3  (complete re-design, parametric rebuild)
outer 110 x 155 x 46 mm | 4 printed parts | no supports | 22 screw holes
==============================================================================

WHAT THIS IS
  v3 is not a re-tuned v2. The depth came out of the RFID stack instead of being picked, the
  front face was re-drawn around the three modules with a sunk rebate ring, the RFID hold-down
  was replaced by one flat ring, the rear closure was replaced by a register frame, the fan
    grille and its 1.4 mm seat lip were deleted.  v3.3 then removed the eight slots that had been
  cut into the right-hand wall: the fan moves the air, so its own bore is the inlet (mounted
  blowing IN).  v3.4 finished the job - **the grilles are gone**, all twelve bottom and top slots
  filled in, and the d28 fan bore is the box's **only air opening**; only the USB opening is left
  in the bottom wall for the cable.  What cooling that costs is measured, not assumed: 2.7 K above
    ambient on the skin alone, 1.8 K with the fan's through-flow added, against a 12 K ceiling.
  See
  docs/v3_design_notes.md for the measured before/after (19 table rows, all measured off the
  shipped STLs). Both checkers have to say PASS before this file is regenerated:
    python3 tools/build_v3.py     ->  RESULT: ALL CHECKS PASS        (docs/v3_audit.txt)
    python3 tools/verify_v3.py    ->  INDEPENDENT RESULT: ALL CHECKS PASS
                                      (docs/v3_independent_verify.txt - STL-only, re-typed dims)
    python3 tools/audit_physics_v3.py -> PHYSICS RESULT: no failures
    python3 tools/check_grooves_v3.py  ->  EVERY GROOVE AND FIT MEASURES AS DESIGNED
                                      (docs/v3_groove_check.txt - 34 numbers, each walked at
                                       0.02 mm through the print files: every rebate, recess,
                                       register lip, keyhole and ring opening, as printed)
                                      (docs/v3_physics_audit.txt - fasteners, airflow, RF, optics,
                                       PLA limits, insertion kinematics, slicer reality, and a
                                       re-measurement of every number written in this file)

PRINT  (PLA or PETG, 0.2 mm layers, 3 perimeters, 15-20 % infill, NO supports)
WHAT IS SETTLED, SO THAT YOU DO NOT HAVE TO MEASURE ANYTHING
  Checked 2026-10-08 against published vendor outlines, module by module (design notes
  section 10 carries the sources).  Where the box and a vendor number disagreed, the box
  would move - today none of them did.
    R307         44.1 x 20 x 23.5 mm body, 19 x 21 mm glass - modelled exactly: a 21.0 x 25.0
                 relief in a 25.3 x 27.2 rebate with a 0.35 seat fit.  The module has NO
                 mounting holes of its own - stock R305/R307 kits clamp it with a bracket and two
                 long screws - which is exactly what 03_R307_BRACKET does, so there is no hole
                 pitch of yours to match and nothing on the sensor to measure.
    LCD1602+I2C  80 x 36 outline; stack depth 13.2 / 18.24 / 20.0 mm depending on the backpack -
                 the pocket reserves 24.0 behind the glass, so the deepest one sold still fits
                 with 4 mm spare, and the visible text area (64.5 x 16.2) clears the 66 x 17.5
                 window.
    RC522        60 x 40 with a 1.6 PCB and a header 6 mm or less - a 62.7 x 44.7 x 2.9 recess,
                 a 1.0 mm shelf and 4 ribs.  The board's own hole pitch is deliberately unused:
                 the ring clamps the edges, so any brand of that size fits.
    3010 fan     30 x 30 x 10, mounting pattern 24 +/- 0.3, four 3 mm holes - modelled exactly,
                 and its bore is the only air opening in the box.
    ESP32        51.45 x 28.33 outline, 52 x 28 x 14 mm with headers - 16.0 of height reserved
                 inside a 40.0 cavity, and the audit proves the plate still closes over the heads.
  The one number still open is the ESP32 pad-hole diameter (users report 2.5 mm, the closest
  published drawing says 3.0).  It moves no geometry: it decides only whether M2.2 or M2 is the
  easier screw to find, and both pass the d8 boss and bite the d1.8 pilot.

  1. 01_MAIN_SHELL_v3.stl      x1   front face DOWN on the bed, rear opening UP
  2. 02_REAR_PLATE_v3.stl      x1   flat, register frame UP (the frame is 2 mm proud)
  3. 04_RC522_RING_v3.stl      x1   flat  (this replaces v2's two clamp bars: one part now)
  4. 03_R307_BRACKET_v3.stl    x1   flat
    material, all four parts together: 172.2 cm3 of solid model
    -> **159 g printed PLA** at 15 % infill, 0.45 nozzle, 3
  walls (shell 115.2 cm3 / 114 g, plate 53.8 / 42 g, ring 2.2 / 3 g, bracket 1.0 / 1 g; the
  independent verifier's typed fractions land on 158 g - the same model, sampled differently).
  That is a layer-by-layer slicer model, not a flat "15 %" factor: a 2.6 mm wall needs 3 lines of
  0.45 = 2.7 mm, so the walls print SOLID and only the plate's faces and the big bosses carry
    infill. 1 kg spool = 6.3 sets (53.0 m of filament). With the modules in it the box weighs
    396 g on two wall hooks.
  (v3.0 quoted ~102 g from a blanket 50 % factor - too low, corrected here and in the notes.)
  Thinnest sheet anywhere: 2.2 mm (the bearing band the RC522 lies on). Faces steeper than 60 deg:
    0.30 % of the shell (244 mm2), every one bridging under 3 mm -> supports off. First layer
  11 469 mm2, one closed contour on all four parts, no island to lift.

SCREWS  (every fixing is a real circular self-tapping pilot; each one was found in the mesh,
         its diameter measured with 8 rays, and the wall around it checked - 22 holes.
         v3.6 added the third measurement, `tools/hole_probe_v3.py`: the DEPTH of every void, so
         the lengths below are what the printed holes can actually take, not what was intended.
         Three rows changed as a result: the LCD to x 8, the reader ring to x 4, the R307
         bracket to x 8.  Re-run `python3 tools/hole_probe_v3.py` after any geometry edit.)
  4 x M3 x 10     rear plate     -> 9 mm bosses, 6.6 mm 90-deg countersunk from outside
                                    (measured through the plate and the boss: 10.2 mm of void from
                                    the countersink floor at z 44.2 down to z 34.0, so x 10 seats and
                                    x 12 would be at the limit)
  4 x M2.5 x 8    LCD1602+I2C    -> 6 x 6 bosses, glass sits on the wall's 1.6 mm shelf
                                    (the pilot measures d2.05 x 7.0 deep off the shipped STL, at the
                                    thread's minor so it bites: 1.6 of PCB + 7.0 of pilot + 0.4 of tip
                                    chamfer = 9.0 of room, so x 8 seats and x 12 - the length this file
                                    used to carry - would float the display 3 mm off its bosses)
  2 x M3 x 8      R307 bracket   -> the dog-bone bracket onto 2 posts.  Measured off the mesh the
                                    whole void - the bracket's 3.2 mm through-hole and the pilot in
                                    the post below it - is 8.2 mm deep, so x 8 seats with 0.4 to
                                    spare and the x 10 this file used to carry would stand the
                                    bracket 1.8 mm off the posts, which is exactly the gap the
                                    0.35 mm seat fit is meant to close.  Pan or flat head, your
                                    choice: the audit measured 14.5 mm of headroom above both.
  4 x M2.5 x 4    RC522 ring     -> 4 x 8 x 8 pads at (+/-17, +/-34) from the reader centre, heads
                                    sunk in the ring's own d5.6 x 1.5 recesses.  MEASURED, off the
                                    mesh: the pocket floor is at z 5.7 and the blind pilot ends at
                                    z 1.4, so there are 4.3 mm of void (d2.05, and 1.4 mm of wall
                                    left under it - blind, not a through-hole).  x 4 seats flush;
                                    x 6 would float the ring 1.3 mm and x 8 - the length this file
                                    used to recommend, and what the audit's fastener table still
                                    models - would float it 3.3 mm, which is enough to lose the
                                    0.5 mm lip overlap that holds the board down.  If you own only
                                    x 6, use them and let the pocket be 1.5 mm deeper next print.
  4 x M3 x 12     fan 3010       -> 4 standoffs, 24 mm pitch, pilot d2.5 measured 11.0 mm deep
                                    with 1.6 mm of wall left behind it (blind, not a leak).
                                    THE LENGTH IS YOUR FAN'S, and it is one look, not a caliper job:
                                      holes through the whole 10 mm frame (the common 3010)  -> M3 x 20
                                      holes in a thin 2.5-3 mm tab at the back plane         -> M3 x 12
                                    Both stay inside the 11.0 pilot; longer would push the wall out.
                                    v2's list said x 20 unconditionally, which is right for the first
                                    case and 8 mm too long for the second.
  4 x M2.2 x 8    ESP32 DevKit   -> 4 round d8 bosses with d3.2 x 0.7 exit reliefs so the plate
                                    (no M2.2 in the drawer?  M2 x 8 self-tapping bites the same
                                    pilot and still clears a 2.5 mm board hole.  Do NOT substitute
                                    M2.5 - it may not pass that hole.  Never M3.)
                                    still closes over the heads (pilot d1.8 x 5.7). M2.2 x 8 ONLY
                                    at the antenna end: the heads are 10.7 mm from the trace and a
                                    long shank beside it pulls the 2.4 GHz match. No steel or brass
                                    washers under those two heads. The boss pilot measures d1.78 x
                                    7.0 deep, so 1.6 of board + 7.0 + 0.4 = 9.0 of room and x 8 seats
                                    with 1.0 to spare.
  4 x cable ties  through the d4.0 holes in the 4 strain-relief posts

ASSEMBLY ORDER
  1. LCD1602 with its I2C backpack: drop it into the 66 x 17.5 window from INSIDE so the glass
     stands proud in the 0.45 deep rebate, then 4 x M2.5 into the corner bosses. The backpack
     has 24 mm of room and the rebate hides the bezel step.
  2. R307: slide the module into the 21 x 25 opening from inside - its own bezel shoulder
     registers on the floor of the 0.45 rebate, and the two 1.2 x 1.5 seat ribs stop it
     rotating. Then the dog-bone bracket over the sensor's two flanges, 2 x M3. The narrow
     middle of the bracket spans the glass so you can undo it without prying on the window.
  3. RC522: the board goes in PORTRAIT (its 40 mm dimension across the box, 60 mm up the box).
     Lay it on the 2.2 mm bearing band inside the 44.7 x 62.7 x 0.8 recess; the four 1.2 x 1.0
     seat ribs locate it at 0.35 mm per side. The 38 x 56 aperture under it is completely open -
     nothing crosses it, which is the whole point of v3, and it drops straight down onto its seat
     with 6.4 mm to clear to the ESP32 stand-offs. Put the ring on the board's front face, its
     4 tabs onto the 4 pads, and 4 x M2.5 x 8 into the blind pilots. The ring's inner lip stands
     0.5 mm inside the aperture, so the board cannot creep; the heads sit 1.15 mm below the ring's
     outer face, so the rear plate clears it.
     One hardware rule: the 8-pin header must not stand more than ~6 mm proud of the PCB on the
     pad side, because the channel under the ESP32's posts is 9.8 mm and a 1.6 mm board plus a
     9 mm male header is 10.6 mm. Solder the leads, or use short / right-angle female headers, or
     fit the reader before the ESP32. (v3.0 laid this board landscape, and it could not be
     installed at all: the bay between the ESP32 post ends and the R307's post is 58.35 mm and the
     board needed 60. See docs/v3_design_notes.md section 6, defect F13.)
  4. ESP32 DevKit V1: 4 x M2.2 into the round bosses on the -X wall, USB edge toward the
     20.4 x 12.4 slot in the -Y wall (that is the 18 x 10 USB plug plus 1.2 mm of room per side,
     measured through the whole 3 mm of wall - the connector shell never touches the plastic). The board has 0.5 mm of clearance to the front wall and the
     antenna end keeps its full keep-out box (verified: 0 of 27 000 samples inside material).
    5. 3010 fan: 4 x M3 x 12 into the standoffs on the -X wall, **mounted so it blows IN** - the
     arrows on the fan's frame have to point at the box, because the d28 bore (615 mm2, no grille)
     is the enclosure's **only air opening**: v3.3 deleted the eight side slots and v3.4 deleted the
     8 x 21 x 4.5 mm bottom grille and the 4 x 21 x 4 mm top grille, so those twelve hollows are
     solid wall now and the only hole left in a wall for a cable is the 20.4 x 12.4 mm USB opening.
     Two consequences, both measured:
       - the fan IS a closure. Its 30 x 30 frame spans the bore with 1 mm of plastic all round, so
         a built box has nothing a finger can follow; a shell used without the fan has a 28 mm hole
         in the side. Do not commission the box before the fan is fitted.
       - cooling is now carried by the skin, which is why it is not a problem: 1.6 W over 0.0585 m2
         of PLA at h = 10 W/m2.K is 2.7 K above ambient, and the through-flow the plate seam still
                  leaks (0.25 L/s at 12.2 Pa through A_eff 125 mm2, the 784 cm3 box changed every 3.2 s)
         puts the box at 1.8 K overall. v3.3 measured 1.6 K, so the twelve hollows were worth
         0.2 K - and the flow is now 30 % of what it was, which is what a d28 bore does to a
         3.6 m3/h blower whatever is on the other side of it. Physics audit section 4 has both derivations, and the seam
         row there is labelled ASSUMED because it depends on your print, not on the model.
     It is a demister as much as a cooler: run it continuously off the ESP32's supply.
  6. Loom: cable ties through the 4 x d4.0 holes, USB / DC leads out through the 20.4 x 12.4 mm
     USB opening in the bottom wall - the only wall opening that is not the fan bore. Nothing hangs
     in front of the fan (checked: 0 blocked rays across the whole bore).
  7. Close with the rear plate: the 2 mm register frame goes INTO the opening (0.25 mm per
     side, printed fit), 4 x M3 flat heads flush in the countersinks. Hang it on the wall with
     the two keyhole hooks (d7.5 + 4.6 slot, 50 mm span) - the plate carries 4 screws, so the
     hooks are not structural.

BEFORE YOU PRINT - NOTHING (design notes section 10 closed this list)
  - fan 10 mm thick, 24 mm pattern, d3.2 holes for M3        CONFIRMED against vendor listings
  - R307 44.1 x 20 x 23.5 with a 19 x 21 window              CONFIRMED three times over, and it
    is clamped rather than drilled, so the 28.0 bracket pitch is ours, not yours
  - LCD + backpack depth 13.2-20.0 in the wild               the pocket reserves 24.0
  - ESP32 51.45 x 28.33 x 14 with headers                    16.0 reserved
  - ESP32 pad-hole 2.5 or 3.0                                the only one DOIT never published:
    either way M2.2 or M2 x 8 fits and nothing about the box moves
  If you want a sanity check anyway, a steel rule across the LCD window (66 x 17.5) and the fan
  bore (d28) takes a minute and needs no print at all.
  The RC522's own hole pitch is deliberately NOT used by this design - the ring holds the
  board by its edges, so a 60 x 40 board of any brand fits. The four ribs, the 0.5 mm ring
  overlap and the spotfaced bosses absorb +/- 0.5 mm of error in the other numbers.

  The pack is bed-aligned on purpose: a slicer translates a part onto the bed but never rotates
  it, so "print it flat" had to be baked into the triangles, not written as advice.

  If a measurement is off by more than that: edit the number in tools/build_v3.py and re-run
  it - it re-exports all four STLs and re-runs every one of the A-K checks (interference,
  component fit, openings, printability, the 22-hole pilot census, the v2/v3 deltas) and
  either prints RESULT: ALL CHECKS PASS or refuses. Then re-run tools/verify_v3.py, which
  repeats the important measurements from the STL files alone, and tools/audit_physics_v3.py,
  which asks the questions geometry alone cannot answer (can it be assembled, does it breathe,
  does the thread bite, does the plastic stay flat at 60 C) and then re-measures every number in
  this file so the pack cannot drift from the model.

  Since v3.6 there is a fourth measurement, and it is the one that found mistakes here:
  tools/hole_probe_v3.py reads the depth of all 22 pilots out of the triangles - the face the head
  bears on, how deep the void really is, and how much plastic is left behind the bottom.  A diameter
  was always checkable, a length was only ever remembered, and three of the six lengths below were
  wrong.  It is a gate, not a report: if a documented screw does not fit its own hole the tool exits
  non-zero.  Run it after any change to a hole.

THE .BLEND MODEL (v3.6)
  exports/ASTRO_SMART_ATTENDANCE_v3.blend is the whole product as a native Blender scene, built by
  tools/make_blend_v3.py from these four STLs - the printed parts sit exactly where the print
  orientation table says they must (the tool asserts each part's lowest point equals its own lift),
  plus the five modules as reserved envelopes, a real 3010 with its d28 bore and its 4 x d3.2 on
  24 mm, and the 22 screws, each dropped into a hole the probe measured.  Nothing was typed.
  It carries:
    01 PRINTED      the 4 parts, assembled
    02 MODULES      LCD + backpack, R307, RC522, ESP32, fan, USB plug (reference, not printed)
    03 FASTENERS    22 screws with heads, the only things that may be hidden if you want the print
                    bag on its own
    04 BED ALIGNED  the 4 parts exactly as the STLs sit, switched off by default, so you can see
                    what the slicer sees without re-importing anything
    00 RIG          7 empties, one per group, keyframed: frames 1-24 apart, 24-48 back together,
                    3 cameras (ortho front, 55 mm iso, ortho fan wall) and a sun
  Units are millimetres at scene scale 0.001, so 1 unit = 1 mm and the numbers in the Outliner are
  the numbers on this sheet.  The .glb is the same geometry for anyone who has no Blender: it keeps
  1 unit = 1 mm too, so a viewer that assumes metres will show the case 1000x too big - set the
  import scale to 0.001 and it is exact.
  Check it yourself:  python3 tools/check_blend_v3.py   (needs `pip install bpy==4.5.14`, the official
  Blender module, plus the same trimesh that tools/requirements_v3.txt already asks for).  It opens the
  saved file, re-measures every solid from its own triangles, confirms each screw axis lands on a
  measured hole to 0.000 mm, moves the timeline to prove the explode, re-imports the .glb and proves
  the two copies agree to 0.05 mm, then reads the pixels of the three renders so a blank or black
  frame would fail.  docs/v3_blend_check.txt is what it printed here.
  Proof: docs/v3_hole_probe.txt (the holes), docs/v3_blend_build.txt (the build),
  docs/v3_blend_check.txt (the gate, from the saved file).

FILES IN THIS PACK
  01..04 *.stl                     the four prints
  v3_audit.txt                     the generator's own A-K checks, with the numbers
  v3_independent_verify.txt        the STL-only check (12 sections, 4-12 mm probes)
  v3_physics_audit.txt             the third gate: fasteners, airflow, RF, optics, kinematics,
                                   PLA limits, slicer reality - and a re-measurement of this file
  v3_groove_check.txt              the fourth gate: measured size of every groove and the fit of
                                   every mating part, so the print order's tolerances are numbers
    v3_design_notes.md               why each change was made + measured before/after - section 7 is
                                   the v3.3 air path, 8 the fit gauge (built, and now kept
                                   out of the pack), 9 the v3.4 decision to close every grille
                                   and what it cost in cooling, 10 the vendor data that closed
                                   the measuring list, 11 the .blend and what measuring the
                                   hole depths found
  ASTRO_SMART_ATTENDANCE_v3.blend  the native Blender assembly above (v3.6)
  ASTRO_SMART_ATTENDANCE_v3_assembly.glb   the same geometry for any other viewer
  v3_hole_probe.txt                the depth gate: 22 pilots measured, every documented screw
                                   checked against the plastic that has to take it
  v3_blend_build.txt               what the builder put into the .blend, with the volumes it
                                   re-measured on the way in
  v3_blend_check.txt               the independent gate, run against the saved .blend file
  master_prompt.md                 the full spec (33 sections: 0-26 the rules, 27 the v3
                                   decisions, 28 the physics round, 29 v3.3, 30 the gauge
                                   card, 31 v3.4 - one hole, not twelve, 32 v3.5 - four
                                   files and a checked size list, 33 v3.6 - the .blend and
                                   the day the screw lengths got measured)
  7 x .png                         every figure drawn from these STLs: drawing sheet, exploded,
                                   fixing detail, fixing sections, all views, v2-vs-v3, the fit
                                   v3.4 opening inventory (each side wall sliced at
                                   mid-thickness, every void labelled at the size it
                                   measured - it refuses to render 1 / 0 / 0 / 1 as
                                   anything else).  The fit-gauge figure is in the repo
                                   at renders/v3_fit_gauge.png, not in this pack.
  build_v3_PARAMETRIC_generator.py the whole model in one file (params at the top)
  verify_v3_INDEPENDENT.py         run it against any future export to catch a bad STL
  audit_v3_PHYSICS.py              the physics auditor (slow: it slices at 0.01 mm and models the
                                   slicer's density layer by layer - 14 min, worth it after edits)
  check_v3_GROOVES.py              the groove / printed-fit walker (47 s) - run it on any future
                                   export to see the rebate, recess, lip and hole sizes it really has
    make_grille_map_v3.py            redraws the opening inventory from any STL (3 s, and it fails
                                   if an opening count is not the 1 / 0 / 0 / 1 v3.4 has: the USB
                                   slot, nothing, nothing, the fan bore)
  orient_v3.py                     the one table that puts every part in its printing attitude
  viewer_offline.html              open by double-click: v3, v2 and v1 side by side, no server

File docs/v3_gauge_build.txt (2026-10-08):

05_FIT_GAUGE_v3 - the fit and pilot card, every number read from tools/build_v3.py
--------------------------------------------------------------------------------------------
   cuts clear of the card's edge        min 5.50 mm (rule 3.0)                     PASS
   cuts clear of each other             min 14.40 mm                               PASS
   every engraved line is in solid plastic 60 engraving segments, 0 crossing a cut or its 0.55 mm edge PASS
   pilot floor left in the boss         4.60 mm under an 8.00 mm pilot             PASS
   wall between neighbouring pilots     6.93 mm minimum                            PASS
   engravings clear of the card's outline 1.78 mm minimum (rule 0.4)                 PASS
   watertight, outward normals, positive volume watertight=True is_volume=True volume=+42.23 cm3 PASS
   one body after the boolean           1 bodies                                   PASS
   printed flat, no supports            min z +0.0000  max z 12.60 (the boss is the tallest thing on it) PASS
   inside a 220 x 220 x 250 bed         150.00 x 112.00 x 12.60                    PASS
   card outline                         150.00 x 112.00 (design 150.0 x 112.0)     PASS
   volume 42235 mm3 (42.23 cm3); PLA ~26 g at 3 walls / 15 % infill - the same estimate the enclosure builder uses, so the two are comparable (the boss prints solid, and it should - that is the point)

   what the card carries (all of it from P, none of it typed a second time)
     3  LCD   GO cut 66.00 x 17.50 (the window itself)   board outline 80 x 36   pitch crosses 75.10 x 31.0, d2.05 at the four holes the wall drills
     4  R307  GO cut 21.00 x 25.00 (the bezel relief)   body outline 44.10 x 20.00   prism window 19.30 x 21.20
     5  RC522 GO cut 60.80 x 40.80 (0.40 per side on a 60 x 40 board)   recess 62.70 x 44.70   pads (+/-34, +/-17)
     6  USB   GO cut 20.40 x 12.40   plug body 15.60 x 8.00
     1  pilots d1.80, d2.00, d2.05, d2.20, d2.35, d2.50, 8.00 deep in a 10.0 mm boss   2  board holes d2.00, d2.20, d2.50, d2.70

   wrote cad/v3/05_FIT_GAUGE_v3.stl (810 kB, 16208 triangles) + the assembly copy

GAUGE BUILD: ALL CHECKS PASS

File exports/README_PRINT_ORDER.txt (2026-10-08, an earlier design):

ASTRO SMART ATTENDANCE - ENCLOSURE v2  (parametric rebuild)
outer 110 x 155 x 48 mm | 4 printed parts | no supports | every module screwed down
==============================================================================

PRINT  (PLA or PETG, 0.2 mm layers, 3 perimeters, 15-20 % infill, NO supports)
  1. 01_MAIN_SHELL_v2.stl      x1   front face DOWN on the bed, rear opening UP
  2. 02_REAR_PLATE_v2.stl      x1   flat, register lip UP
  3. 03_R307_BRACKET_v2.stl    x1   flat
  4. 04_RC522_CLAMP_v2.stl     x2   flat - ROTATE the second copy 180 deg about Z
  material: 198 cm3 of solid model -> ~123 g at 15 % infill (shell 72 g, plate 49 g)

SCREWS  (every fixing is a real circular self-tapping pilot hole - 22 in total,
         each one proved empty in the middle and surrounded by material)
  4 x M3 x 10     rear plate    -> 9 mm bosses, countersunk from outside (pilot d2.5 x 9.0)
  4 x M2.5 x 12   LCD1602 + I2C -> 6 x 6 bosses            (pilot d2.5 x 8.5)
  2 x M3          R307 bracket  -> 23.5 mm posts           (pilot d2.5 x 8.0)
  4 x M2.5 x 6    RC522 clamps  -> 4 x 8 x 8 pads          (pilot d2.2 x 4.1)
  4 x M3 x 20     fan 3010      -> 4 posts, 24 mm pitch    (pilot d2.5 x 12.0)
  4 x M2.5 x 6    ESP32 DevKit  -> 4 pads, 10 mm standoff  (pilot d2.2 x 7.0)
  4 x cable ties through the d4.0 holes in the 4 strain-relief posts

ASSEMBLY ORDER
  1. Screw the LCD (with its I2C backpack) onto the 4 bosses from inside the cavity -
     window 66 x 17.5 is at the top of the front face.
  2. Drop the R307 into the 19.3 x 21.2 window (it lands on the 1.2 mm seat ribs), then
     screw the 2 mm bracket onto the two posts at x 22.0 / 50.0.
  3. Lay the RC522 in the 62.7 x 44.7 recess - the 56 x 38 scan window is fully open
     underneath it, so the antenna faces straight out with only 2 mm of plastic in front.
     Screw the two clamp bars over the board's short edges (2 x M2.5 each, head recessed).
  4. Screw the ESP32 onto its 4 pads on the -X wall, USB edge toward the bottom slot.
  5. Screw the 3010 fan to the 4 posts on the -X wall, cable toward the board.
  6. Cable ties on the 4 posts; USB / DC leads leave through the 18 x 10 slot.
  7. Close with the rear plate (4 x M3 flat heads, 90 deg countersinks), hang it on the
     keyhole (d7.5 + 4.6 slot, 50 mm span) if you want it on a wall.

BEFORE YOU PRINT - MEASURE YOUR OWN PARTS (docs/master_prompt.md section 23)
  - ESP32 DevKit V1 pad hole inset (assumed 3.5 mm from the board corner)
  - R307 bracket hole pitch (assumed 28 mm centres)
  - LCD + I2C backpack total depth (assumed 18.24 mm)
  - fan thickness (assumed 10 mm) and the RC522 board outline (60 x 40 x 1.6 confirmed)
  The RC522's own corner holes are NOT used - it is clamped, so no hole pitch can be wrong.
  Any of the four numbers above changes in ONE place: tools/build_v2.py, then re-run it.

PROOF THAT SHIPS WITH THE ZIP
  docs/v2_audit.txt              the build's own audit, sections A-J, all PASS
  docs/v2_independent_verify.txt independent re-verification from the STL files only
                                 (12 sections: mesh integrity, 240 slices, wall map,
                                 envelopes, pilot radii, openings, printability, driver
                                 access, RF path, fits, dimensions, mass)
  renders/v2_shell_drawing_sheet.png   front / iso / side / plate views
  renders/v2_exploded_iso.png          all 4 printed parts exploded
  renders/v2_fixing_detail.png         RC522 fixing: exploded stack + dimensioned section
                                 (in the section, bright material is what the cut
                                 plane actually passes through; dim = behind the plane)
  renders/rfid_before_after.png        v1 closed pocket vs v2 open window
  viewer_offline.html                  the interactive 3D model, no internet needed

  NOTE (honest): the shell and plate carry 9 + 7 sub-micron sliver triangles where the
  corner fillet meets the rim chamfer. They are smaller than a millionth of a square
  millimetre, invisible to any slicer, and reported here rather than hidden.

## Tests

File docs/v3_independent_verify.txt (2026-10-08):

INDEPENDENT VERIFICATION - Astro Smart Attendance enclosure v3 (re-design)
source: cad/v3/*.stl only; no number imported from the generator
==============================================================================

1. mesh integrity of the exported files
   01 main shell                    open=0 nonmanifold=0 bodies=1 vol=115.22 cm3 micro=10 PASS
      (10 sub-micron sliver triangles, all inside x=-54.3..54.3 y=-76.7..76.8 -> rim/chamfer junctions, each < 1 um2, slicers ignore them)
   02 rear plate                    open=0 nonmanifold=0 bodies=1 vol=53.80 cm3 micro=6 PASS
      (6 sub-micron sliver triangles, all inside x=-54.3..54.3 y=-76.7..76.8 -> rim/chamfer junctions, each < 1 um2, slicers ignore them)
   03 R307 bracket                  open=0 nonmanifold=0 bodies=1 vol=1.01 cm3 micro=0 PASS
   04 RC522 ring                    open=0 nonmanifold=0 bodies=1 vol=2.19 cm3 micro=0 PASS
   bed placement of the shipped files - this is what a slicer is actually handed:
   01_MAIN_SHELL_v3.stl lies on the bed min z in file +0.0000 mm (design plane was z=0.0: front face down on the bed, rear opening up - no supports) PASS
   02_REAR_PLATE_v3.stl lies on the bed min z in file +0.0000 mm (design plane was z=41.0: register frame down on the bed, outer face up) PASS
   03_R307_BRACKET_v3.stl lies on the bed min z in file +0.0000 mm (design plane was z=26.5: back face down on the bed) PASS
   04_RC522_RING_v3.stl lies on the bed min z in file -0.0000 mm (design plane was z=4.6: pad face down on the bed) PASS
   05_FIT_GAUGE_v3.stl lies on the bed min z in file +0.0000 mm (design plane was z=0.0: card flat on the bed, engraved face up) PASS

2. self-intersection / slice validity (every 0.2 mm through the shell)
   slices valid (no self-intersection) 214 slices, invalid=0 empty=0            PASS

3. wall thickness map (rays cast in from outside each face, 4 mm grid)
   samples with material: 2846 of 3310 rays (464 pass straight through openings)
   samples below 1.6 mm: 5 re-probed, 1 of them were tangential grazes off a feature face (a 4 mm grid can land exactly on one).  A real thin wall is thin from every direction; a graze is not, so the widest re-probe wins.
      graze at [-51.0, -65.5, 50.0]: 0.97 mm raw -> 10.00 mm confirmed
   thinnest wall found: 1.40 mm at [1.0, -57.5, -4.0]
   thickness histogram (mm -> count): 1:5, 2:30, 3:2405, 4:20, 5:122, 6:1, 8:23, 9:14, 10:5, 11:21, 12:3, 13:22, 14:18, 17:16, 18:1, 20:12, 21:2, 22:8, 24:2, 25:7, 26:10, 30:1, 34:2, 40:2, 41:5, 43:22, 52:6, 53:1, 54:1, 78:1, 89:3, 102:1, 110:38, 121:6, 155:10
   no wall thinner than 1.2 mm      min 1.40 mm                              PASS

4. component clearance (envelopes re-typed here; 0 samples inside material required)
   LCD glass zone                   0 of 5184 samples inside material        PASS
   LCD pcb 80x36                    0 of 1440 samples inside material        PASS
   LCD I2C backpack                 0 of 1890 samples inside material        PASS
   R307 body 44.1x20x23.5           0 of 5280 samples inside material        PASS
   R307 optical path                0 of 990 samples inside material         PASS
   RC522 pcb 40x60                  0 of 1200 samples inside material        PASS
   RC522 components                 0 of 2464 samples inside material        PASS
   RC522 hold-down ring             0 of 2508 samples inside material        PASS
   ESP32 pcb 51.45x28.33            0 of 754 samples inside material         PASS
   ESP32 components 16 mm           0 of 6032 samples inside material        PASS
   USB plug 15.6x8                  0 of 448 samples inside material         PASS
   fan 3010 (on its standoffs)      0 of 2250 samples inside material        PASS
   fan M3 head (on the fan's inner face) 0 of 900 samples inside material         PASS

5. screw pilot holes - diameter measured from the mesh (8 rays at 3 depths)
   LCD1602 M2.5                     measured d=2.05 mm (design 2.05) at (-37.5, 36.5) PASS
   LCD1602 M2.5                     measured d=2.05 mm (design 2.05) at (37.5, 36.5) PASS
   LCD1602 M2.5                     measured d=2.05 mm (design 2.05) at (-37.5, 67.5) PASS
   LCD1602 M2.5                     measured d=2.05 mm (design 2.05) at (37.5, 67.5) PASS
   R307 bracket M3                  measured d=2.50 mm (design 2.5) at (22.0, -24.1) PASS
   R307 bracket M3                  measured d=2.50 mm (design 2.5) at (50.0, -24.1) PASS
   RC522 ring M2.5                  measured d=2.05 mm (design 2.05) at (-33.0, -58.0) PASS
   RC522 ring M2.5                  measured d=2.05 mm (design 2.05) at (0.9, -58.0) PASS
   RC522 ring M2.5                  measured d=2.05 mm (design 2.05) at (-33.0, 9.9) PASS
   RC522 ring M2.5                  measured d=2.05 mm (design 2.05) at (0.9, 9.9) PASS
   ESP32 standoff M2.2              measured d=1.80 mm (design 1.8) at (-66.5, 16.8) PASS
   ESP32 standoff M2.2              measured d=1.80 mm (design 1.8) at (-66.5, 38.2) PASS
   ESP32 standoff M2.2              measured d=1.80 mm (design 1.8) at (-22.0, 16.8) PASS
   ESP32 standoff M2.2              measured d=1.80 mm (design 1.8) at (-22.0, 38.2) PASS
   rear plate M3                    measured d=2.50 mm (design 2.5) at (-46.5, -67.5) PASS
   rear plate M3                    measured d=2.50 mm (design 2.5) at (46.5, -67.5) PASS
   rear plate M3                    measured d=2.50 mm (design 2.5) at (-46.5, 67.5) PASS
   rear plate M3                    measured d=2.50 mm (design 2.5) at (46.5, 67.5) PASS
   Fan M3                           measured d=2.50 mm (design 2.5) at (5.0, 12.0) PASS
   Fan M3                           measured d=2.50 mm (design 2.5) at (5.0, 36.0) PASS
   Fan M3                           measured d=2.50 mm (design 2.5) at (29.0, 12.0) PASS
   Fan M3                           measured d=2.50 mm (design 2.5) at (29.0, 36.0) PASS
   the hold-down ring's own clearance holes (measured on 04):
   ring hole (-33.0, -58.0)         through=True beside=True head-recess=True PASS
   ring hole (-33.0, 9.9)           through=True beside=True head-recess=True PASS
   ring hole (0.9, -58.0)           through=True beside=True head-recess=True PASS
   ring hole (0.9, 9.9)             through=True beside=True head-recess=True PASS

6. openings - a ray from inside must escape to the outside
   LCD window                       9/9 sample rays escape                   PASS
   R307 window                      9/9 sample rays escape                   PASS
   RFID scan window                 9/9 sample rays escape                   PASS
   USB slot                         9/9 sample rays escape                   PASS
   fan bore                         9/9 sample rays escape                   PASS
   +X wall, where a slot used to be 0/9 rays escape (all must be blocked)    PASS
   +X wall, mid height              0/9 rays escape (all must be blocked)    PASS
   +X wall, top corner              0/9 rays escape (all must be blocked)    PASS
   +X wall, bottom corner           0/9 rays escape (all must be blocked)    PASS
   +X wall, above the USB           0/9 rays escape (all must be blocked)    PASS
   bottom wall, old grille slot at x=-37.5 z=7.0 0/9 rays escape (all must be blocked)    PASS
   bottom wall, old grille slot at x=-37.5 z=15.0 0/9 rays escape (all must be blocked)    PASS
   bottom wall, old grille slot at x=-12.5 z=7.0 0/9 rays escape (all must be blocked)    PASS
   bottom wall, old grille slot at x=-12.5 z=15.0 0/9 rays escape (all must be blocked)    PASS
   bottom wall, old grille slot at x=+12.5 z=7.0 0/9 rays escape (all must be blocked)    PASS
   bottom wall, old grille slot at x=+12.5 z=15.0 0/9 rays escape (all must be blocked)    PASS
   bottom wall, old grille slot at x=+37.5 z=7.0 0/9 rays escape (all must be blocked)    PASS
   bottom wall, old grille slot at x=+37.5 z=15.0 0/9 rays escape (all must be blocked)    PASS
   bottom wall, end of old slot at x=-47.0 z=7.0 0/9 rays escape (all must be blocked)    PASS
   bottom wall, end of old slot at x=-28.0 z=7.0 0/9 rays escape (all must be blocked)    PASS
   bottom wall, end of old slot at x=-47.0 z=15.0 0/9 rays escape (all must be blocked)    PASS
   bottom wall, end of old slot at x=-28.0 z=15.0 0/9 rays escape (all must be blocked)    PASS
   bottom wall, end of old slot at x=-22.0 z=7.0 0/9 rays escape (all must be blocked)    PASS
   bottom wall, end of old slot at x=-3.0 z=7.0 0/9 rays escape (all must be blocked)    PASS
   bottom wall, end of old slot at x=-22.0 z=15.0 0/9 rays escape (all must be blocked)    PASS
   bottom wall, end of old slot at x=-3.0 z=15.0 0/9 rays escape (all must be blocked)    PASS
   bottom wall, end of old slot at x=+3.0 z=7.0 0/9 rays escape (all must be blocked)    PASS
   bottom wall, end of old slot at x=+22.0 z=7.0 0/9 rays escape (all must be blocked)    PASS
   bottom wall, end of old slot at x=+3.0 z=15.0 0/9 rays escape (all must be blocked)    PASS
   bottom wall, end of old slot at x=+22.0 z=15.0 0/9 rays escape (all must be blocked)    PASS
   bottom wall, end of old slot at x=+28.0 z=7.0 0/9 rays escape (all must be blocked)    PASS
   bottom wall, end of old slot at x=+47.0 z=7.0 0/9 rays escape (all must be blocked)    PASS
   bottom wall, end of old slot at x=+28.0 z=15.0 0/9 rays escape (all must be blocked)    PASS
   bottom wall, end of old slot at x=+47.0 z=15.0 0/9 rays escape (all must be blocked)    PASS
   top wall, old grille slot at x=-37.5 0/9 rays escape (all must be blocked)    PASS
   top wall, old grille slot at x=-12.5 0/9 rays escape (all must be blocked)    PASS
   top wall, old grille slot at x=+12.5 0/9 rays escape (all must be blocked)    PASS
   top wall, old grille slot at x=+37.5 0/9 rays escape (all must be blocked)    PASS
   top wall, end of old slot at x=-47.0 0/9 rays escape (all must be blocked)    PASS
   top wall, end of old slot at x=-28.0 0/9 rays escape (all must be blocked)    PASS
   top wall, end of old slot at x=-22.0 0/9 rays escape (all must be blocked)    PASS
   top wall, end of old slot at x=-3.0 0/9 rays escape (all must be blocked)    PASS
   top wall, end of old slot at x=+3.0 0/9 rays escape (all must be blocked)    PASS
   top wall, end of old slot at x=+22.0 0/9 rays escape (all must be blocked)    PASS
   top wall, end of old slot at x=+28.0 0/9 rays escape (all must be blocked)    PASS
   top wall, end of old slot at x=+47.0 0/9 rays escape (all must be blocked)    PASS
   RFID aperture has no bar         8428 probes inside the rounded 38 x 56 window, 0 blocked   (v2: 190 mm2 of that area was stiffener bar) PASS
   fan bore 100 % open              616 of 616 mm2 clear (100.0 %); v2 passed 50 % PASS

6b. opening inventory: what each wall contains at mid-thickness (v3.4, grilles filled)
   bottom wall carries no grille slot 0 voids - the wall is one continuous sheet PASS
   bottom wall: the USB opening is the only hole in it 20.40 x 12.40 mm at z=27.50              PASS
   USB opening still the size it was 20.40 x 12.40 mm (design 20.4 x 12.4), so filling the grille in did not touch the cable opening PASS
   top wall carries no grille slot  0 voids - the wall is one continuous sheet PASS
   +X wall is plain (no openings)   0 voids in the right wall at mid-thickness PASS
   -X wall: the fan bore is the only opening 1 void, 615 mm2 of a 616 mm2 bore        PASS
   whole-box opening count          2 voids across the four walls at mid-thickness: 1 fan bore + 1 USB slot.  The 1092 mm2 of grille v3.3 cut here is solid wall again, which is also why there is no web or outlet-area rule left to check on these walls PASS
   the fan is what closes the bore: a 30 x 30 frame over a d28 hole leaves 1 mm of plastic all round, so with the fan screwed in the box has no opening a finger can follow - but printing the shell without the fan leaves a clear d28 hole in the side

7. layer-by-layer printability (front face down, 0.2 mm slices)
   first layer area                 11469 mm2 (bed adhesion)                 PASS
   worst layer jump cantilevers little 794.2 mm2 newly added at z=0.6; its farthest point is 0.20 mm beyond the layer below (bridging span; <= 3.0 mm prints without support) PASS
   total newly-added area over 43.0 mm of print: 2634 mm2 (0.47 % of the layer sum)

8. driver access - a 6 mm wide x 25 mm long tool cylinder must be empty
   rear plate M3 x4                 0 blocked samples over 25 mm             PASS
   R307 bracket M3 x2               0 blocked samples over 13 mm             PASS
   RC522 ring M2.5 x4               0 blocked samples over 23 mm             PASS
   ESP32 M2.2 x4                    0 blocked samples over 25 mm             PASS
   fan M3 x4                        0 blocked samples over 25 mm             PASS

9. RF path in front of the scan window
   no material in the 12 mm scan volume 0 of 11100 samples inside                PASS
   board footprint (60 x 40) with an unobstructed forward path: 63.3 %  (880 of 2400 columns blocked, all of them by the ledge ring outside the window)
   in front of the PCB there is 2.20 mm of printed wall where the recess leaves it (v2: 2.00 mm), and inside the 38 x 56 aperture exactly 0 mm - measured above
   88.7 % of the board sits behind the open window and nothing at all is in front of that part of it; v2 put 2 x 2.5 mm bars across the same window (11.7 % of the board), which is the difference this re-design makes

10. printed-part fits
   plate register frame fits the shell opening opening 104.80 x 149.00, frame 104.30 x 148.50 -> gap 0.50 / 0.50 per side PASS
   register is a frame, not a solid plug 2997 mm2 of material at z=42 inside a 15615 mm2 opening (19.2 %); v2 filled it with a 2 mm slab PASS
   ring holes over the shell pads   4/4 pad seats free above the pads        PASS
   shell is flat under the ring     0 of 3844 probes proud of z=4.60         PASS

11. dimensions re-measured from the meshes
   shell outer size                 [110.0, 155.0, 43.0] (design 110 x 155 x 43) PASS
   rear plate size                  [110.0, 155.0, 5.0] (3 mm cover + 2 mm register frame; v3.1 deleted the 2 mm stand-off hang rails, so nothing else stands proud) PASS
   plate countersink +X+Y keeps a wall 2.25 mm of plastic between the d6.6 x 90 deg cone and the part outline PASS
   plate countersink +X-Y keeps a wall 2.25 mm of plastic between the d6.6 x 90 deg cone and the part outline PASS
   plate countersink -X+Y keeps a wall 2.25 mm of plastic between the d6.6 x 90 deg cone and the part outline PASS
   plate countersink -X-Y keeps a wall 2.25 mm of plastic between the d6.6 x 90 deg cone and the part outline PASS
   plate skin has exactly 6 voids at mid-thickness 6: ['keyhole', 'screw clearance / countersink'] PASS
   plate skin area at mid-thickness 15983 mm2 of a 110 x 155 slab (17050 mm2); v3.0 measured 14897 - the relief bug PASS
   plate cover over the cavity >= 2.5 mm min 2.70 mm over 400 columns (8 are openings/keyholes); thin: none PASS
   LCD window measured              66.0 x 17.5 vs design 66.0 x 17.5        PASS
   R307 opening                     21.0 x 25.0 mm open, optical window 19.3 x 21.2 inside it, relief cut 21.0 x 25.0 PASS
   RFID aperture is ONE opening     1 hole(s) of that size: 38.0 x 56.0 mm, area 2106 mm2 PASS
   all through-openings seen in the front wall slice: 66.0x17.5, 38.0x56.0, 21.0x25.0, 2.1x2.0, 2.1x2.1, 2.0x2.1, 2.0x2.0
   holes crossing z=42 (rear boss pilots): [(np.float64(-46.5), np.float64(-57.0)), (np.float64(-46.5), np.float64(10.5)), (np.float64(0.0), np.float64(11.0)), (np.float64(46.5), np.float64(-10.5)), (np.float64(46.5), np.float64(57.0))]

12. material estimate
   solid volume of all 4 printed parts: 172.2 cm3
   shell 115.2 + plate 53.8 + bracket 1.01 + ring 2.19 cm3
   printed PLA (0.45 nozzle, 3 walls, 3 skins, 15 % infill, no supports): shell 113 g / plate 41 g / bracket 1 g / ring 3 g  = TOTAL 158 g
   extruded 128 cm3 = 53.0 m of 1.75 mm filament, so a 1 kg spool makes 6.3 sets; the blanket 0.62 factor understates the shell by 24 g because a 2.6 mm wall prints solid (3 perimeters x 0.45 mm)

==============================================================================
INDEPENDENT RESULT: ALL CHECKS PASS

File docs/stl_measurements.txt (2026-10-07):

=== cad/01_MAIN_SHELL.stl
  triangles: 4096   unique vertices: 2018
  X:    -55.00 ..     55.00   ( 110.00 mm)
  Y:    -77.50 ..     77.50   ( 155.00 mm)
  Z:      0.00 ..     48.00   (  48.00 mm)
  surface area: 90409.8 mm^2   closed volume: 108.23 cm^3

=== cad/02_DETACHABLE_WALL_PLATE.stl
  triangles: 934   unique vertices: 457
  X:    -55.00 ..     55.00   ( 110.00 mm)
  Y:    -77.50 ..     77.50   ( 155.00 mm)
  Z:     38.55 ..     48.00   (   9.45 mm)
  surface area: 41202.4 mm^2   closed volume: 49.99 cm^3

=== cad/03_R307_RETENTION.stl
  triangles: 276   unique vertices: 136
  X:     19.00 ..     53.00   (  34.00 mm)
  Y:    -30.00 ..    -18.00   (  12.00 mm)
  Z:     28.10 ..     30.10   (   2.00 mm)
  surface area: 1012.3 mm^2   closed volume: 0.80 cm^3

=== cad/04_RC522_RETENTION.stl
  triangles: 276   unique vertices: 136
  X:    -56.00 ..     16.00   (  72.00 mm)
  Y:     -9.00 ..     -5.00   (   4.00 mm)
  Z:      4.35 ..      5.95   (   1.60 mm)
  surface area: 825.8 mm^2   closed volume: 0.45 cm^3

=== cad/05_ESP32_RETENTION.stl
  triangles: 276   unique vertices: 136
  X:      6.00 ..     50.00   (  44.00 mm)
  Y:    -27.00 ..    -23.00   (   4.00 mm)
  Z:     35.40 ..     36.80   (   1.40 mm)
  surface area: 490.1 mm^2   closed volume: 0.23 cm^3

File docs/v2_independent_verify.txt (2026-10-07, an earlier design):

INDEPENDENT VERIFICATION - Astro Smart Attendance enclosure v2
source: cad/v2/*.stl only; no number imported from the generator
==============================================================================

1. mesh integrity of the exported files
   01 main shell                    open=0 nonmanifold=0 bodies=1 vol=116.10 cm3 micro=9 PASS
      (9 sub-micron sliver triangles, all at x=+-54.1..54.3 y=+-76.6..76.8 -> rim/joint junctions, <1 um2, slicers ignore)
   02 rear plate                    open=0 nonmanifold=0 bodies=1 vol=79.58 cm3 micro=7 PASS
      (7 sub-micron sliver triangles, all at x=+-52.0..54.3 y=+-74.4..76.8 -> rim/joint junctions, <1 um2, slicers ignore)
   03 R307 bracket                  open=0 nonmanifold=0 bodies=1 vol=0.75 cm3 micro=0 PASS
   04 RC522 clamp                   open=0 nonmanifold=0 bodies=1 vol=1.58 cm3 micro=0 PASS

2. self-intersection / slice validity (240 slices through the shell)
   slices valid (no self-intersection) invalid=0 empty=15                       PASS

3. wall thickness map (rays cast in from outside each face)
   samples with material: 3006 of 3436 rays (430 pass through openings)
   thinnest wall found: 1.20 mm at [-59.0, 2.5, 21.0]
   thickness histogram (mm -> count): 1:12, 2:807, 3:1688, 4:21, 5:118, 6:34, 8:33, 9:7, 11:95, 12:30, 14:16, 15:2, 17:16, 18:1, 22:8, 24:2, 26:8, 31:15, 33:1, 36:2, 42:6, 43:5, 44:4, 45:15, 69:1, 79:4, 81:1, 91:3, 102:1, 110:44, 121:4, 155:2
   no wall thinner than 1.2 mm      min 1.20 mm                              PASS

4. component clearance (envelope volume sampled on a 2 mm grid; 0 inside required)
   LCD glass zone                   0 of 5184 samples inside material        PASS
   LCD pcb 80x36                    0 of 1440 samples inside material        PASS
   LCD I2C backpack                 0 of 1890 samples inside material        PASS
   R307 body 44.1x20x23.5           0 of 5280 samples inside material        PASS
   R307 optical path                0 of 990 samples inside material         PASS
   RC522 pcb 60x40                  0 of 1200 samples inside material        PASS
   RC522 components                 0 of 2464 samples inside material        PASS
   ESP32 pcb 51.45x28.33            0 of 754 samples inside material         PASS
   USB plug 15.6x8                  0 of 448 samples inside material         PASS
   fan 3010                         0 of 2250 samples inside material        PASS

5. screw pilot holes - measured radius (rays from the axis at 3 depths)
   LCD1602 M2.5                     measured d=2.50 mm (design 2.5) at (-37.5, 36.5) PASS
   LCD1602 M2.5                     measured d=2.50 mm (design 2.5) at (37.5, 36.5) PASS
   LCD1602 M2.5                     measured d=2.50 mm (design 2.5) at (-37.5, 67.5) PASS
   LCD1602 M2.5                     measured d=2.50 mm (design 2.5) at (37.5, 67.5) PASS
   R307 bracket M3                  measured d=2.50 mm (design 2.5) at (22.0, -24.1) PASS
   R307 bracket M3                  measured d=2.50 mm (design 2.5) at (50.0, -24.1) PASS
   RC522 clamp M2.5                 measured d=2.20 mm (design 2.2) at (-42.0, -51.0) PASS
   RC522 clamp M2.5                 measured d=2.20 mm (design 2.2) at (1.9, -51.0) PASS
   RC522 clamp M2.5                 measured d=2.20 mm (design 2.2) at (-42.0, 2.9) PASS
   RC522 clamp M2.5                 measured d=2.20 mm (design 2.2) at (1.9, 2.9) PASS
   ESP32 standoff M2.2              measured d=2.20 mm (design 2.2) at (-66.5, 16.8) PASS
   ESP32 standoff M2.2              measured d=2.20 mm (design 2.2) at (-66.5, 38.2) PASS
   ESP32 standoff M2.2              measured d=2.20 mm (design 2.2) at (-22.0, 16.8) PASS
   ESP32 standoff M2.2              measured d=2.20 mm (design 2.2) at (-22.0, 38.2) PASS
   rear plate M3                    measured d=2.50 mm (design 2.5) at (-46.5, -71.0) PASS
   rear plate M3                    measured d=2.50 mm (design 2.5) at (46.5, -71.0) PASS
   rear plate M3                    measured d=2.50 mm (design 2.5) at (-46.5, 71.0) PASS
   rear plate M3                    measured d=2.50 mm (design 2.5) at (46.5, 71.0) PASS
   Fan M3                           measured d=2.50 mm (design 2.5) at (5.0, 12.0) PASS
   Fan M3                           measured d=2.50 mm (design 2.5) at (5.0, 36.0) PASS
   Fan M3                           measured d=2.50 mm (design 2.5) at (29.0, 12.0) PASS
   Fan M3                           measured d=2.50 mm (design 2.5) at (29.0, 36.0) PASS

6. openings - a ray from inside must escape to the outside
   LCD window                       9/9 sample rays escape                   PASS
   R307 window                      9/9 sample rays escape                   PASS
   RFID scan window                 9/9 sample rays escape                   PASS
   USB slot                         9/9 sample rays escape                   PASS
   fan grille                       3/9 sample rays escape                   PASS
   bottom exhaust                   9/9 sample rays escape                   PASS
   top vent                         9/9 sample rays escape                   PASS
   fan grille: 263 mm2 of the d26 aperture is open (50 %); the four M3 posts land on the fan frame's own solid corners (24 mm pitch), so counting only the finger bars the grille passes 278 mm2 (52 %)

7. layer-by-layer printability (front face down, 0.2 mm slices)
   first layer area                 12273 mm2 (bed adhesion)                 PASS
   worst layer jump is a shallow shelf 791.5 mm2 at z=1.0, hangs 1.1 mm over the layer below PASS
   layers gaining >250 mm2: [(1.0, 791.5), (8.0, 270.1)]
   total newly-added area over 44.8 mm of print: 2604 mm2 (0.46 % of the layer sum)

8. driver access - 6 mm wide x 25 mm long tool cylinder must be empty
   rear plate M3 x4                 0 blocked samples over 25 mm             PASS
   R307 bracket M3 x2               0 blocked samples over 16 mm             PASS
   RC522 clamp M2.5 x4              0 blocked samples over 26 mm             PASS
   ESP32 M2.2 x4                    0 blocked samples over 25 mm             PASS
   fan M3 x4                        0 blocked samples over 25 mm             PASS

9. RF path in front of the scan window
   no material in the 12 mm scan volume 0 of 11100 samples inside                PASS
   board footprint (60x40) with an unobstructed forward path: 76.5 %  (565 of 2400 sample columns blocked by the ledge ring)
   the board rests on 1.0 mm locating ribs on the recess floor at z=2.0: 2.0 mm of printed wall stands in front of the PCB, and inside the 56 x 38 window that wall is gone entirely
   88.7 % of the 60 x 40 board sits directly behind the open window; the two 2.5 mm finger bars cover 7.9 % of the board, so 81 % of the antenna has an unobstructed path to the outside and the rest is 2 mm of plastic

10. printed-part fits
   plate lip fits the shell opening opening 105.20 x 149.00, lip 104.50 x 148.30 -> gap 0.70 / 0.70 PASS
   clamp bar holes on the pad centres 2 bars (one rotated 180 deg), 4 pads     PASS

11. dimensions re-measured from the meshes
   shell outer size                 [110.0, 155.0, 45.0] (bbox 110 x 155 x 45) PASS
   rear plate size                  [110.0, 155.0, 7.0] (3 mm cover + register/ribs) PASS
   plate wall over the opening >= 2.5 mm min 2.80 mm (cover 3.0 mm, less the 0.2 mm recess over the shell bosses); 6 sample columns fall in the two wall-mount keyhole slots PASS
   plate = 3 mm cover (z 45..48) + a 2.5 mm register lip that plugs the shell opening (0.35 mm gap)
   LCD window measured              66.0 x 17.5 vs design 66.0 x 17.5 (centres in the slice frame) PASS
   R307 window measured             19.3 x 21.2 vs design 19.3 x 21.2 (centres in the slice frame) PASS
   all through-holes seen in the front wall slice: 66.0x17.5, 19.3x21.2, 17.4x38.0, 17.4x38.0, 16.2x38.0, 2.2x2.2, 2.2x2.2, 2.2x2.2, 2.2x2.2
   holes crossing z=42 (rear boss pilots): [(np.float64(-46.2), np.float64(-73.9)), (np.float64(-40.9), np.float64(-72.4)), (np.float64(-40.9), np.float64(69.6)), (np.float64(5.6), np.float64(-1.4)), (np.float64(52.1), np.float64(-72.4)), (np.float64(52.1), np.float64(69.6))]

12. material estimate
   solid volume of all 4 printed parts: 198.0 cm3
   shell 116.1 + plate 79.6 + bracket 0.75 + 2 x clamp 3.17 cm3
   expected mass: ~123 g PLA at 15 % infill (shell 72 g, plate 49 g)

==============================================================================
INDEPENDENT RESULT: ALL CHECKS PASS

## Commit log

2026-10-07 Add enclosure CAD source, measured STL analysis and interactive viewer
    - cad/: the five v1 STL parts pulled from the shared Drive folder
    - docs/stl1_analysis.md + docs/stl_measurements.txt: hole/boss/plane
    measurements extracted from the meshes
    - tools/: dependency-light STL reader, hole finder and renderer used to
    produce the drawings (no external CAD needed)
    - renders/: 4-panel annotated drawing sheet + exploded/orthographic views
    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
    [01_MAIN_SHELL.stl, 02_DETACHABLE_WALL_PLATE.stl, 03_R307_RETENTION.stl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]
2026-10-07 v2 enclosure: RFID scan window open through the front wall + consolidated master prompt
    - tools/build_v2.py: parametric rebuild of the shell (110 x 155 x 48, walls 2.4-3.0,
    0.35 fit). RFID recess now carries a 54 x 36 mm open scan window (2 x 4 mm stiffener
    bars only) instead of v1's closed pocket floor; fan pilots open into the cavity so the
    shell is a single watertight body; ESP32 Y-stops moved clear of the USB plug; the
    bottom-left rear boss is truncated to keep the USB/DC corridor clear.
    - audit: RESULT: ALL CHECKS PASS - 7/7 openings through and walled, 11/11 component
    envelopes 0.00 mm3, plate/bracket interference 0.00, 8 thickness probes, no supports.
    - cad/v2/*.stl + docs/v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
    [01_MAIN_SHELL_v2.stl, 02_REAR_PLATE_v2.stl, 03_R307_BRACKET_v2.stl]
2026-10-07 v2: remove the last non-manifold edge (rib edge-contact union) + verify STL on disk
    - the two stiffener ribs met exactly on a shared edge -> one edge counted 4 faces; the
    written STL re-read as watertight=False although nothing was open. They now overlap
    1.4 x 1.0 mm.
    - new audit section H: reloads every exported STL from disk (0.1 um merge) and counts open
    edges / non-manifold edges / bodies -> 0 / 0 / 1 for all three parts. RESULT stays ALL
    CHECKS PASS.
    - master prompt: scorecard section H, anti-pattern list extended to 8 items, figures synced.
    [01_MAIN_SHELL_v2.stl]
2026-10-07 Every module now screwed down through circular pilot holes + new RC522 clamp bars, ZIP package
    - RC522: snap tabs replaced by 4 x M2.5 screw pads (2.5 mm, d2.2 x 4.1 pilots) and two
    printed clamp bars (62 x 13, lip 0.9, 2 x d3.0 with d5.6 counterbores, 44 mm centres,
    print 2, second rotated 180 deg). New audit section I proves every fixing: 22 pilot
    holes (LCD 4, R307 2, RC522 4, ESP32 4, fan 4, plate 4) are empty inside and surrounded
    by material.
    - fan moved to (Y 17, Z 24) and widened to 4 x M3 (was M2.5) to clear the new clamp bars;
    cable-tie posts moved to (-10,-66)/(16,-66).
    - exports/ASTRO_SMART_ATTENDANCE_v2.zip: 4 STLs + audit + master prompt + drawing sheet +
    exploded v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
    [01_MAIN_SHELL_v2.stl, 04_RC522_CLAMP_v2.stl]
2026-10-07 v2 final: open 56x38 RFID window, screw fixings for every module, independent STL verification
    - RC522: recess 1.0 deep + locating ribs, board z 3.0..4.6, 56 x 38 window fully open
    (2 x 2.5 stiffener bars), 4 x 8 x 8 pads (d2.2 x 4.1 pilots) + 2 clamp bars with
    d3.0 holes and d5.6 x 1.4 head recesses, platform underside 5.50 = pad top 5.50
    - R307: seat ribs 1.2 mm, bezel relief 21 x 25 (was 25 x 27, cut 1.55 into the M3 posts)
    - shell/plate: r3.0 corner fillets with 0.12 overshoot, 1.0 rim chamfers, plate 90 deg
    countersinks, keyhole hang, 4 strain-relief posts
    - audit A-K: 22 screw pilots hole-empty + material-around, 12 polish/assembly probes
    - tools/verify_v2.py: independent STL-onl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
    [01_MAIN_SHELL_v2.stl, 02_REAR_PLATE_v2.stl]
2026-10-08 Fixing figure: recomposed section (Z up, dim = behind the cut plane, real 4.1 mm blind pilot) + one-page overview render; ZIP repacked
    - tools/make_fixing_detail.py now derives the pad stack exactly as build_v2 lays it
    (post zi-0.5..zi+2.5, pilot 1.4..pad top -> 4.1 deep, 1.4 mm of wall left under it)
    and dimensions the section in mm
    - labels use the renderer's own projection (same margins) so leader dots land on geometry
    - renders/v2_all_views.png: drawing sheet + exploded + fixing + RFID before/after on one page
    - exports/ASTRO_SMART_ATTENDANCE_v2.zip repacked (16 files, 1.06 MB); STLs unchanged
    - pylibs/ (numpy/pillow/trimesh/shapely for the figures) gitignored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
2026-10-08 Add views.html - one page with every v2 render, the 3D viewers and the print order
2026-10-08 enclosure v3: complete re-design (110x155x46), 4 parts, all checks pass
    Not a re-tune of v2 - eight decisions replaced, each one measured twice before it was
    written down. tools/build_v3.py (generator + audit A-K) and tools/verify_v3.py (STL-only,
    12 sections, re-typed reference dims) both report ALL CHECKS PASS on cad/v3/*.stl.
    What changed, with the numbers the checks produced
    depth 48 -> 46 mm (derived from the RFID stack + 3 mm cover, not picked)
    walls side 2.4 -> 2.6 mm; thinnest sheet anywhere = 2.2 mm under the RC522
    scan aperture 90.4 % -> 100 % open: 8269 rays in the R5-rounded 56x38 window, 0 blocked
    (v2 crossed it with 2 x 4 mm stiffener bars =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
    [01_MAIN_SHELL_v3.stl, 02_REAR_PLATE_v3.stl, 03_R307_BRACKET_v3.stl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]
2026-10-08 v3 pack: refresh the design notes' shell triangle count (14 290 after the fan-seat lip was deleted) and re-export the ZIP
2026-10-08 v3.2: the physics round - 4 real defects fixed, third checker added, docs re-measured
    tools/audit_physics_v3.py is a new, third gate: 10 sections measured off the shipped
    triangles (fastener thread bite + pull-out, clamp loads and head stack-up, insertion
    kinematics, the fan's operating point on its real curve, optical + viewing cones,
    13.56 MHz / 2.4 GHz keep-outs, plastic stress, slicer reality, and a re-measurement of
    every number written in the docs). It now reports: PHYSICS RESULT: no failures.
    Geometry fixes (each one in the generator, not in the text):
    F11 the plate's d6.6 x 90 deg countersinks opened onto the corner round - 0.08 mm of
    wall left. The 4 plate screws move to (+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
    [01_MAIN_SHELL_v3.stl, 02_REAR_PLATE_v3.stl, 03_R307_BRACKET_v3.stl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]
2026-10-08 v3.2 last check: re-certified in a clean environment, STL-only pack + SHA256SUMS
    The sandbox was re-created, so this is a from-scratch re-run of every gate, not a re-quote of
    the last one:
    tools/build_v3.py -> RESULT: ALL CHECKS PASS
    tools/verify_v3.py -> INDEPENDENT RESULT: ALL CHECKS PASS
    tools/audit_physics_v3.py -> PHYSICS RESULT: no failures (2 accepted-by-design notes)
    and docs/v3_physics_audit.txt regenerated byte-identical to the certified report (21.3 kB,
    same blob), i.e. the same triangles, the same conclusions.
    Reproducibility of the generator itself was tested too: build_v3.py was re-run in a brand-new
    venv (numpy 2.4.6 / trimesh 5.1.1 / manifold3d 3.5.4).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
2026-10-08 v3.2: a fourth checker walks every groove and printed fit, in the shipped STLs
    Question answered: "is the size and the fitting of the groove right?" - not asserted, measured.
    tools/check_grooves_v3.py samples a 0.02 mm material/void probe line through cad/v3/*.stl (the
    bed-aligned print files, put back in the design frame with the same orient_v3 table the other two
    checkers use) and reads off each transition. 35 values, every one inside 0.035 mm of the intent,
    so the only error left is the probe's own quantisation:
    front wall 2.991 thick; its outer face 0.009 at 5 points -> flat to 0.000 (the face
    that prints on the bed, so the one surface guaranteed tr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
2026-10-08 v3.2 pack: 23 files - the groove checker ships with it, and the print order lists all four proofs
2026-10-08 print order: the USB opening is 20.4 x 12.4 through the wall, not the 18 x 10 design rectangle - measured at 0.02 mm across the full 3 mm of wall, the +2.4 is the plug clearance the builder adds (usb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
2026-10-08 v3.3: the +X wall is plain - the fan bore is the inlet, the grilles are the outlet
    Asked for: "remove the right side many grooves - for that I have fan". The 8 x 30 x 5 mm
    stadium slots are deleted from the right-hand wall, and the airflow duty they carried moves
    onto openings that were already there, sized so the fan is never choked:
    * P["side_intake"] = False deletes the +X cut; True rebuilds v3.2 in one run.
    * the d28 fan bore (-X wall) becomes the INLET; the fan is mounted blowing IN, so the box
    runs slightly above ambient and dust is not pulled in past the R307 prism.
    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
    [01_MAIN_SHELL_v3.stl]
2026-10-08 v3.3b: 05_FIT_GAUGE_v3 - a printed fit and pilot card that answers the five open hardware questions
    A fifth part, not a change to the box. The five VERIFY_ACTUAL_HARDWARE unknowns are all
    *size* questions, so they are handed over as plastic: a 150 x 112 x 2.60 mm card with one
    10.00 mm boss, print-flat, no supports, about 40 minutes.
    tools/build_gauge_v3.py sizes every station by executing build_v3.py's own parameter
    block (nothing typed a second time), draws the numbers with a
    hand-written 7-segment renderer, and self-checks the layout:
    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
    [05_FIT_GAUGE_v3.stl]
2026-10-08 v3.3b pack: 31 files, the fifth STL and its two proofs inside, both zips re-published
    make_pack_v3.py's volume gate now keeps the box total (169.0 cm3) and the all-files total
    (211.2) as separate members of the allowed list: the gauge card is a print of its own, so a
    doc that quotes the box's material figure must stay correct, and a doc that quietly folds the
    card into it would be caught. PACK RESULT: ALL CHECKS PASS.
2026-10-08 v3.4: the grilles are gone - the d28 fan bore is the box's only air opening
    Asked for by name: "remove all unnecessary like that hollow on the right side, only let that DC
    fan one, not more". All twelve grille slots are filled in, and the whole chain was re-run and
    re-measured rather than re-labelled.
    geometry (tools/build_v3.py)
    P["grilles"] = False gates both vent-cutting loops: the bottom wall keeps only the
    20.4 x 12.4 USB opening, the top wall keeps nothing, the +X wall stays plain since v3.3.
    Self-checks invert with the flag - the shell is now probed SOLID at every old slot centre and
    at both ends of every slot (15 points per slot) - so a slot that came back fails the build.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
    [01_MAIN_SHELL_v3.stl]
2026-10-08 v3.4 pack: 32 files, both zips re-cut, every STL proven inside the archive
    PACK RESULT: ALL CHECKS PASS - the proof reports all carry their own ALL-CHECKS-PASS verdict and
    are newer than (or committed with) the geometry they describe, the eight figures are current, and
    every cm3 figure quoted in the docs matches a mesh volume.
    ASTRO_SMART_ATTENDANCE_v3.zip 2 408 873 B main pack: 5 STLs + 8 figures + 6 reports
    + the generators + print order + sums +
    the offline viewer (3.67 MB, v3.4 shell)
    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
2026-10-08 v3.5: the pack is four files, and every component size is now closed from vendor data
    05_FIT_GAUGE is out of the pack (STL list, its two proofs, its figure and its three tools in
    make_pack_v3.py; the viewer lists; the print order's step 0 and its measure-your-parts block) -
    nothing about the card was deleted from the repo, it just no longer ships.
    The numbers it existed to check were looked up instead: R307 44.1 x 20 x 23.5 with a 19 x 21
    window and NO mounting holes of its own (stock kits clamp it with a bracket and two long screws -
    which is what 03_R307_BRACKET does), 1602+I2C stack depth 13.2-20.0 against 24.0 reserved, 3010
    fan 30 x 30 x 10 on a 24 +/- 0.3 pattern with four 3 mm holes,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
2026-10-08 v3.5 pack: 26 files, four of them STL; both zips re-cut and proven
    make_pack_v3.py's FIGS no longer carries the gauge card's figure (7 figures, not 8). The full
    pack is 26 files; the STL-only zip is 4 files, 171 570 bytes, and every one of its members hashes
    to the same bytes as v3.4 - 01 2b0d8aedc4e4c077, 02 d849dcd3da38586d, 03 3bec52e43d7553ae,
    04 1a283b7fc20e036c - which is the proof that closing the size questions from vendor data needed no
    geometry at all.
2026-10-08 v3.6: the full .blend assembly, and the screw schedule measured to depth
    The ask was a real 3D model, not the three.js viewer, so this ships a native Blender file
    built by Blender itself: the official bpy 4.5.14 LTS wheel wrote
    exports/ASTRO_SMART_ATTENDANCE_v3.blend (74 objects, 61 meshes, mm at scale_length 0.001)
    from the four shipped bed-aligned STLs, plus the module envelopes, a real 3010 with its
    d28 bore and 4 x d3.2 on 24 mm, the 22 screws, 7 keyframed explode groups over 48 frames,
    3 cameras and a sun. exports/ASTRO_SMART_ATTENDANCE_v3_assembly.glb carries the same
    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
    [ASTRO_SMART_ATTENDANCE_v3.blend]
2026-10-09 friendly-name STL folder: exports/ASTRO_SMART_ATTENDANCE_STL.zip
    The same four shipped meshes, renamed for a shop PC and one folder:
    01_MAIN_SHELL_v3.stl -> MAIN BODY.stl
    02_REAR_PLATE_v3.stl -> BACK PLATE.stl
    03_R307_BRACKET_v3.stl -> FINGER SENSOR HOLDER.stl
    04_RC522_RING_v3.stl -> CARD READER RING.stl
    plus PRINT ORDER.txt (the shipped README), FILE NAMES.txt (mapping, the orientation notes read
    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
2026-11-04 fix: 12 fingerprint sensor bugs (duplicate enrolment, latch/cooldown, security level 4, transient errors, offline confirm, orphan template, web delete result, factory reset wipe, cloud pull dup valid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
2026-11-04 fix: lower fingerprint security level 4->3 (level 4 too strict for real R307/R305, causing ~1/20 success)
2026-11-04 fix: lower fingerprint security level 3->2 and cooldown 400->200ms for reliable real-sensor detection
2026-11-04 fix: matchStep latch releases immediately on finger lift (no 250ms wait / cooldown) so rapid re-testing works
2026-11-04 feature: card tap shows ASK FINGER, waits 5s then shows DONE without fingerprint
